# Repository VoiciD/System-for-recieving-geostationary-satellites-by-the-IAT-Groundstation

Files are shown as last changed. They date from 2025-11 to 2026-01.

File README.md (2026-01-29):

# System-for-recieving-geostationary-satellites-by-the-IAT-Groundstation
Die Arbeit beschäftigt sich mit der Planung, Entwicklung und Umsetzung eines Empfangssystems
für geostationären Satelliten mit einem Downlink im X-Band. Als Satellite bietet sich dabei der
Amateurfunksatellit Es’Hail-2 (QO-100) an, welcher einen Schmal- und Breitbandtransponder
mit Downlink im X-Band besitzt. In dieser Arbeit wird nur der Downlink des Schmalbandtrans-
ponder betrachtet.
Neben der Untersuchung des Satelliten gehört zur Planung und Entwicklung des Empfangs-
systems die Auswahl der passenden Komponenten. Im Zuge dessen wird an der Hochschule
vorhandene Antenne auf ihre Tauglichkeit überprüft, sowie neue notwendige Komponenten des
Empfangssystems ausgewählt. Für die Auswahl der passenden Komponenten ist eine theore-
tische Betrachtung des Downlinks notwendig. Besonderer Fokus wird dabei auf die Übertra-
gungsstrecke zwischen dem Satelliten und dem Standort des Empfangssystem am IAT gelegt.
Insbesondere die Dämpfung in der Atmosphäre bei unterschiedlichen Wetterbedingungen - kla-
rer Himmel, leichter Regen und Regen - und ihre Auswirkungen werden untersucht. Ermittelt
werden konnten Dämpfungen für klaren Himmel von LATklarerHimmel = 0.547 dB, leichter Regen
von LATleichterRegen = 0.947 dB und bei starken Niederschlägen von LATRegen = 9.61 dB. Diese
haben ebenfalls Auswirkungen auf das Rauschen des Empfangssystem. Für das Eigenrauschen
des Empfangssystems konnte eine äquivalente Rauschtemperatur Te,sys = 336.63 K und eine
Rauschzahl von Fsys = 3.34 dB ermittelt werden.
Für die einzelen Wetterbedingungen wird anschließend das Link Budget und der Signal-zu-
Rauschabstand am Ein- und Ausgang ermittelt womit eine Aussage über die Aufrechterhaltung
des Downlinks getroffen werden kann. Dabei kommt raus, dass der Downlink auch bei starken
Niederschlägen Aufrecht erhalten werden kann.
Mit dem entwickelten und aufgebauten Empfangssystem am IAT ist es möglichen den Downlink
des Schmalbandtransponder auf Es’Hail-2 (QO-100) zu empfangen. Jedoch ist die Leistung am
Ausgang PRX um 11.59 dB geringer, als in der Theorie berechnet. Da die gemessene Rauschleis-
tung nur um 0.93 dB von der berechneten Rauschleistung abweicht, ist von einer nicht optimalen
Ausrichtung der Antenne auf den Satelliten auszugehen.
Zum Schluss hin werden die berechneten und gemessenen Empfangsparameter des Empfangssys-
tem am IAT mit den Empfangsparameter mit einem Empfangssystem an der Goonhilly Bodensta-
tion in Cornwall (England) verglichen. Die Empfangsparameter an der Goonhilly Bodenstation
sind leicht besser, können aber mit der geographisch gesehen besseren Lage zum Satelliten und
dem größeren Antennendurchmesser von 1.3 m und damit verbundenen größeren Antennenge-
winn erklärt werden.

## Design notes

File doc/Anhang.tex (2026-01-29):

\subsection{Literaturverzeichnis}
\printbibliography
\subsection{Abbildungsverzeichnis}
\listoffigures
\subsection{Tabellenverzeichnis}
\listoftables

\subsection{Python Skripts}
\begin{lstlisting}[caption={Simulation eines Mischers in Python}, label={lst:mischer-python}]
import numpy as np
import matplotlib.pyplot as plt
import scipy.signal as sig
#Define Samplingtime and Sampling Frequency
ts = 0.001              #Samplingtime 0.001s
t = np.arange(0,1,ts)   #time axis
#Define the signals and noise
A_s = 1*10**(-3)
A_r = 1*10**(-3)
A_i = 0.1*10**(-3)
f_s_t = 200                                 #Input Frequency
f_i_t = 100                                 #Image Frequency
f_n_t = 150                                 #LO Frequency
s_t = A_s * np.cos(2*np.pi*f_s_t*t)         #Input Signal
i_t = A_i * np.cos(2*np.pi*f_i_t*t)         #Image Signal
n_t = A_r * np.cos(2*np.pi*f_n_t*t)         #LO Signal
x_t = s_t * n_t                             #Mixing
xsp_t = i_t * n_t                             #Mixing
#Using the FFT
n = len(t)
fs = int(1/ts)                              #Defining the Sampling Frequency and those the sampling points
x_t_fft = np.fft.fft(x_t,fs)                #Doing the FFT
s_t_fft = np.fft.fft(s_t,fs)                #Doing the FFT
n_t_fft = np.fft.fft(n_t,fs)                #Doing the FFT
i_t_fft = np.fft.fft(i_t,fs)                #Doing the FFT
xsp_t_fft = np.fft.fft(xsp_t,fs)                #Doing the FFT
shifted_x_t_fft = np.fft.fftshift(x_t_fft)  #bringing the 0 Hz into the center
shifted_s_t_fft = np.fft.fftshift(s_t_fft)  #bringing the 0 Hz into the center
shifted_n_t_fft = np.fft.fftshift(n_t_fft)  #bringing the 0 Hz into the center
shifted_i_t_fft = np.fft.fftshift(i_t_fft)  #bringing the 0 Hz into the center
shifted_xsp_t_fft = np.fft.fftshift(xsp_t_fft)  #bringing the 0 Hz into the center
mag_x = abs(shifted_x_t_fft)/n                          #calculating the magnitude
mag_s = abs(shifted_s_t_fft)/n                          #calculating the magnitude
mag_n = abs(shifted_n_t_fft)/n                          #calculating the magnitude
mag_i = abs(shifted_i_t_fft)/n                          #calculating the magnitude
mag_xsp = abs(shifted_xsp_t_fft)/n                          #calculating the magnitude
mag_x_dB = 10*np.log10(mag_x[int(fs/2):]/0.001)
mag_s_dB = 10*np.log10(mag_s[int(fs/2):]/0.001)
mag_n_dB = 10*np.log10(mag_n[int(fs/2):]/0.001)
mag_i_dB = 10*np.log10(mag_i[int(fs/2):]/0.001)
mag_xsp_dB = 10*np.log10(mag_xsp[int(fs/2):]/0.001)
freq = np.arange(0,500,len(t)/fs)
#Plotting
plt.figure()
plt.subplot(211)
plt.plot(freq,mag_s_dB, label = "HF-Signal")
plt.plot(freq,mag_n_dB, label = "LO-Signal")
plt.plot(freq,mag_i_dB, label = "SP-Signal")
plt.ylabel("Signalstrength in [dBm]")
plt.xlabel("Frequency in [MHz]")
plt.grid()
plt.legend(loc='upper right')
plt.tight_layout(h_pad=1.5, w_pad=0.8) 
plt.subplot(212)
plt.plot(freq,mag_x_dB, label = "ZF-Signal")
plt.plot(freq,mag_xsp_dB, label = "SP-Signal")
plt.ylabel("Signalstrength in [dBm]")
plt.xlabel("Frequency in [MHz]")
plt.grid()
plt.legend(loc='upper right')
plt.tight_layout(h_pad=1.5, w_pad=0.8)  
\end{lstlisting}

\begin{lstlisting}[caption={Simulation von Rauschen und SNR in Python}, label={lst:Rauschen-SNR-python}]
import numpy as np
import matplotlib.pyplot as plt
import scipy.signal as sig
#Define Samplingtime and Sampling Frequency
ts = 0.001              #Samplingtime 0.001s
t = np.arange(0,1,ts)   #time axis
#Define the signals and noise
A_s = 1*10**(-3)
A_r = 3*10**(-3)
f_s_t = 50
s_t = A_s * np.sin(2*np.pi*f_s_t*t)         #wanted signal
n_t = A_r * np.random.randn(len(t))         #Generating Noise with the length of the time axis
x_t = s_t + n_t
#Using the FFT
n = len(t)
fs = int(1/ts)                              #Defining the Sampling Frequency and those the sampling points
s_t_fft = np.fft.fft(x_t,fs)                #Doing the FFT
shifted_s_t_fft = np.fft.fftshift(s_t_fft)  #bringing the 0 Hz into the center
mag = abs(shifted_s_t_fft)/n                          #calculating the magnitude
freq = np.arange(-500,500,len(t)/fs)
mag = 10*np.log10(mag[int(fs/2):]/0.001)
freq = np.arange(0,500,len(t)/fs)
#Plotting
plt.figure()
plt.subplot(311)
plt.plot(t,s_t*1000,label = "Wanted signal")
plt.plot(t,n_t*1000,label = "Noise")
plt.ylabel("Voltage in [mV]")
plt.xlabel("Time in [s]")
plt.grid()
plt.legend(loc='upper right')
plt.subplot(312)
plt.plot(t,x_t*1000,label = "Mixed signal")
plt.ylabel("Voltage in [mV]")
plt.xlabel("Time in [s]")
plt.grid()
plt.legend(loc='upper right')
plt.subplot(313)
plt.plot(freq,mag, label = "FFT of the mixed signal")
plt.ylabel("Signalstrength in [dBm]")
plt.xlabel("Frequency in [Hz]")
plt.grid()
plt.legend(loc='upper right')
plt.tight_layout(h_pad=1.5, w_pad=0.8)    
\end{lstlisting}

\begin{lstlisting}[caption={Berechnung der Dämpfung durch Regen}, label={lst:Dämpfung-durch-Regen-python}]
import numpy as np
import matplotlib.pyplot as plt
elevation = np.deg2rad(27.36)  #elevation of the Antenna [°]
tau = np.deg2rad(-12.412)       #skew of the Antenna
h_0 = 3                         #Height of the isothermic barrier of the region from the groundstation[km]
h_Station = 0.023               #Height of the groundstation above Sealevel [km]
freq = 10.5                    #Frequency at which the link operates [GHz]
cordiantes_station = (53.055, 8.78,0.0)
#determination of the effective rain height [km]
h_R = h_0 + 0.36
#determination of path length the EM-Wave has to travel below the 
D_s = (h_R-h_Station)/(np.sin(elevation))
#determination of the horizontal projection caused by the path length of the EM-Wave
D_HP = D_s*np.cos(elevation)
#determination of the Rain intensity [mm/h] which exceeding the anual mean by 0.01% of the time
R_001 = 35                    #Mean in the northern part of Germany 35 to 40 mm/h 
R_graph = np.arange(0,40, 0.1 ) #For Graph Plotting 0 mm/H to 40mm/h
#determination of the frequency dependend coeffizients. Equations from the Book
# k_H = 3.949*10**(-6)*freq**(3.4078)
# k_V = 2.785*10**(-6)*freq**(3.5032)
# alpha_H = -0.7451*np.log10(freq)+2.0211
# alpha_V = -0.8083*np.log10(freq)+2.0723
#von ITU-R P.838-3
k_H = 0.01217
k_V = 0.01129
alpha_H = 1.2571
alpha_V = 1.2156
#determination of the specific rain attenuatuion
k = (k_H + k_V + (k_H-k_V) * (np.cos(elevation))**2 * np.cos(2*tau))/2
alpha = (k_H * alpha_H + k_V * alpha_V + (k_H * alpha_H - k_V * alpha_V) * (np.cos(elevation))**2 * np.cos(2*tau)) / (2*k)
gamma_R001 = k*(R_001)**alpha
print("y_R001:",gamma_R001,"dB/km")
#calculation horizontal reduction factor
r001 = 1 / (1 + 0.78 * np.sqrt((D_HP*gamma_R001) / freq) - 0.38 * (1 - np.exp(-2 * D_HP)))
#calculation vertical adjustment factor
cc001 = np.rad2deg(np.arctan((h_R-h_Station)/(D_HP*r001)))
if cc001 > np.rad2deg(elevation):
    D_R001 = (D_HP*r001)/np.cos(elevation)
else:
    D_R001 = (h_R-h_Station)/np.sin(elevation)
if abs(cordiantes_station[0]) > 36:
    X = 36 - abs(cordiantes_station[0])
else:
    X = 0
v001 = 1 / (1 + np.sqrt(np.sin(elevation)) * (31 * (1 - np.exp( (-1)* ( elevation/(1+X))))*(np.sqrt(D_R001 *gamma_R001))/(freq**2)-0.45))
#for graph 
A_graph = np.empty_like(R_graph)
gamma_Rgraph = np.empty_like(R_graph)
for i, R in enumerate(R_graph): 
    gamma_Rgraph[i] = k * (R)**alpha
    rgraph = 1 / (1 + 0.78 * np.sqrt((D_HP * gamma_Rgraph[i]) / freq) - 0.38 * (1 - np.exp(-2 * D_HP)))
    ccgraph = np.rad2deg(np.arctan((h_R - h_Station) / (D_HP * rgraph)))
    if ccgraph > np.rad2deg(elevation):
        D_Rgraph = (D_HP * rgraph) / np.cos(elevation)
    else:
        D_Rgraph = (h_R - h_Station) / np.sin(elevation)
    if abs(cordiantes_station[0]) > 36:
        X = 36 - abs(cordiantes_station[0])
    else:
        X = 0
    vgraph = 1 / (1 + np.sqrt(np.sin(elevation)) * (31 * (1 - np.exp(-1 * (elevation / (1 + X)))) * 
                      np.sqrt(D_Rgraph * gamma_Rgraph[i]) / (freq**2) - 0.45))
    D_Regengraph = D_Rgraph * vgraph
    A_graph[i] = gamma_Rgraph[i] * D_Regengraph
print("Vertikal adjusmentfaktor 0.01:",v001)
#calculation effective path length D_Regen
D_Regen001 = D_R001*v001
print("Effectiv Path lenght through the rain 0.01:",D_Regen001,"km")
#calculation worst case attenuation for rain exceeded for 0.01% of an avarage year
A_001 = gamma_R001*D_Regen001
print("worst case attenuation caused by rain exceeded for 0.01% of an avarage year:",A_001,"dB")
plt.figure("Attenuation caused by rain 10 GHz")
plt.title("Dämpfung durch starke Niederschläge bei f = 10 GHz")
plt.plot(R_graph,A_graph)
plt.ylabel("Dämpfung in dB")
plt.xlabel("Niederschlagsmenge in mm/h")
plt.grid()
# Attenuatuion for other percanteges
unit = 1
p = 5*unit
long = 8.78
if p >= 1*unit or abs(long) >= 36:
    beta = 0
elif p < 1*unit and abs(long) < 36 and elevation >= 25:
    beta = (-1)*0.005*(abs(long)-36)
else:
    beta = (-1)*0.005*(abs(long)-36)+1.8-4.25*np.sin(elevation)
exponent = (-1)*(0.655+0.033*np.log(p)-0.045*np.log(A_001)-beta*(1-p)*np.sin(elevation))
A_other = A_001*(p/0.01)**exponent
print("Attenuation for Rainrates exceeding",p,"% of the time the anual avarage:",A_other,"dB")   
\end{lstlisting}

\begin{lstlisting}[caption={Berechnung des Link Budgets}, label={lst:Link-Budget-python}]
import numpy as np
import matplotlib.pyplot as plt
#Allgemeine Parameter
k = 1.38*10**(-23)
P_T = 17.78                         #Sendeleistung Es'Hail-2 in W
P_T_dBm = 42.5
G_T = 50.12                         #Gewinn der Sendeantenne
EIRP = P_T * G_T                    #EIRP von Es'Hail-2
EIRP_dBm = 59.5
B = 2.7*10**3                       #Bandbreite des Downlinks
L_FR = 2.9*10**(20)                 #Freiraumdämpfung
L_FR_dB = 204.61
L_OT = 3.33                         #Senderseitige Fehlausrichtung
L_OT_dB = 5.23
L_OR = 0.69                         #Empfangsseitige Fehlasusrichtung
L_OR_dB = 0.69
G_R = 7244.36
G_LNC = 316227.76
G_SDR = 1000
L_sys = 5.02  
G_sys = G_LNC*G_SDR*(1/L_sys)
T0 = 290
#Äquivalente Rauschtemperatur
Te1 = 133.4                #133.4
TeLNC = 139.2
Te2 = 200.1
TeBiasTee = 118.9
Te3 = 17.4
TePatchfeld = 58
Te4 = 8.7
TeRFSwitch = 20.3
Te5 = 8.7
TeSDR = 1539.9
G1 = 0.685
GLNC = 316227.77
G2 = 0.59
GBiasTee = 0.71
G3 = 0.94
GPatchfeld = 0.83
G4 = 0.97
GRFSwitch = 0.93
G5 = 0.97
T_esys = Te1 + (TeLNC/(G1) ) + (Te2/(G1*GLNC) ) + (TeBiasTee/(G1*GLNC*G2) ) + (Te3/(G1*GLNC*G2*GBiasTee) ) + (TePatchfeld/(G1*GLNC*G2*G3) ) + (Te4/(G1*GLNC*G2*G3*GPatchfeld) ) + (TeRFSwitch /(G1*GLNC*G2*G3*GPatchfeld*G4) )+ (Te5 /(G1*GLNC*G2*G3*GPatchfeld*G4*GRFSwitch) )+ (TeSDR /(G1*GLNC*G2*G3*GPatchfeld*G4*GRFSwitch*G5) )
print("Äquivalente Rauschtemperatur Te,sys:",T_esys,"K")
#klarer Himmel
print("Für Bedingung klarer Himmel:")
L_ATklarerHimmel = 1.13             #Dämpfung in der Atmosphäre bei klarem Himmel
L_ATklarerHimmel_dB = 0.547
T_AklarerHimmel = 6.5               #Antennentemperatur bei klaren Himmel
P_R_klarer_Himmel = EIRP*G_R*(1/L_FR)*(1/L_OT)*(1/L_OR)*(1/L_ATklarerHimmel)
P_R_klarer_Himmel_dB = 10*np.log10(P_R_klarer_Himmel/(0.001))
print("empfangene Leistung $P_R$:",P_R_klarer_Himmel,"W")
print("empfangene Leistung $P_R$",P_R_klarer_Himmel_dB,"dBm")
P_RX_klarer_Himmel = EIRP*G_R*(1/L_FR)*(1/L_OT)*(1/L_OR)*(1/L_ATklarerHimmel)*G_sys
P_RX_klarer_Himmel_dB = 10*np.log10(P_RX_klarer_Himmel/(0.001))
print("Ausgangsleistung des Empfangssystems $P_{RX}$:",P_RX_klarer_Himmel,"W")
print("Ausgangsleistung des Empfangssystems $P_{RX}$",P_RX_klarer_Himmel_dB,"dBm")
N_i = k*T_AklarerHimmel*B
SNR_i_klarerHimmel = P_R_klarer_Himmel/N_i
SNR_i_klarerHimmel_dB = 10*np.log10(SNR_i_klarerHimmel)
print("SNR am Eingang bei klaren Himmel:",SNR_i_klarerHimmel_dB,"dB")
N_o = k*(T_AklarerHimmel+T_esys)*B
SNR_o_klarer_Himmel = P_R_klarer_Himmel/N_o
SNR_o_klarer_Himmel_dB = 10*np.log10(SNR_o_klarer_Himmel)
print("SNR am Ausgang des Empfangssystems:",SNR_o_klarer_Himmel_dB,"dB")
T_S_klarer_Himmel = (T_AklarerHimmel/L_sys)+T0*(1-(1/L_sys))+T_esys
CN0_klarer_Himmel = P_RX_klarer_Himmel/(k*T_S_klarer_Himmel)
CN0_klarer_Himmel_dBHz = 10*np.log10(CN0_klarer_Himmel)
print("Qualität des Downlinks:",CN0_klarer_Himmel_dBHz,"dBHz")
Link_Budget_klarer_Himmel_label = np.array(["Sende-\nLeistung","EIRP","Freiraum-\nDämpfung","Ausrichtungs-\nVerluste","Dämpfung\n Atmosphäre","Empfangene\nLeistung","Leistung\n am Ausgang"])
Link_Budget_klarer_Himmel = np.array([P_T,EIRP_dBm,EIRP_dBm-L_FR_dB,EIRP_dBm-L_FR_dB-L_OR_dB-L_OT_dB,EIRP_dBm-L_FR_dB-L_OR_dB-L_OT_dB-L_ATklarerHimmel_dB,P_R_klarer_Himmel_dB,P_RX_klarer_Himmel_dB])
plt.figure("LinkBudget clear Sky")
plt.title("Link Budget bei klaren Himmel")
for i, val in enumerate(Link_Budget_klarer_Himmel):
    plt.annotate(f'{val:.2f}', (i, val), textcoords="offset points",
                 xytext=(0,10), ha='center')  # 10 Pkt über dem Punkt
plt.plot(Link_Budget_klarer_Himmel_label,Link_Budget_klarer_Himmel,'o-')
plt.ylabel("Leistung in dBm")
plt.grid()
plt.ylim([-180,90])
plt.xticks(range(len(Link_Budget_klarer_Himmel_label)), Link_Budget_klarer_Himmel_label, rotation=45)
plt.tight_layout(pad=0.5)
plt.show()
#leichter Regen
print("Für die Bedingung leichter Regen:")
L_ATleichterRegen = 1.24
L_ATleichterRegen_dB = 0.947
T_AleichterRegen = 19.29
P_R_leichter_Regen = EIRP*G_R*(1/L_FR)*(1/L_OT)*(1/L_OR)*(1/L_ATleichterRegen)
P_R_leichter_Regen_dB = 10*np.log10(P_R_leichter_Regen/(0.001))
print("empfangene Leistung $P_R$:",P_R_leichter_Regen,"W")
print("empfangene Leistung $P_R$",P_R_leichter_Regen_dB,"dBm")
P_RX_leichter_Regen = EIRP*G_R*(1/L_FR)*(1/L_OT)*(1/L_OR)*(1/L_ATleichterRegen)*G_sys
P_RX_leichter_Regen_dB = 10*np.log10(P_RX_leichter_Regen/(0.001))
print("Ausgangsleistung des Empfangssystems $P_{RX}$:",P_RX_leichter_Regen,"W")
print("Ausgangsleistung des Empfangssystems $P_{RX}$",P_RX_leichter_Regen_dB,"dBm")
N_i = k*T_AleichterRegen*B
SNR_i_leichter_Regen = P_R_leichter_Regen/N_i
SNR_i_leichter_Regen_dB = 10*np.log10(SNR_i_leichter_Regen)
print("SNR am Eingang bei klaren Himmel:",SNR_i_leichter_Regen_dB,"dB")
N_o = k*(T_AleichterRegen+T_esys)*B
SNR_o_leichter_Regen = P_R_leichter_Regen/N_o
SNR_o_leichter_Regen_dB = 10*np.log10(SNR_o_leichter_Regen)
print("SNR am Ausgang des Empfangssystems:",SNR_o_leichter_Regen_dB,"dB")
T_S_leichter_Regen = (T_AleichterRegen/L_sys)+T0*(1-(1/L_sys))+T_esys
CN0_leichter_Regen = P_RX_leichter_Regen/(k*T_S_leichter_Regen)
CN0_leichter_Regen_dBHz = 10*np.log10(CN0_leichter_Regen)
print("Qualität des Downlinks:",CN0_leichter_Regen_dBHz,"dBHz")
Link_Budget_leichter_Regen_label = np.array(["Sende-\nLeistung","EIRP","Freiraum-\nDämpfung","Ausrichtungs-\nVerluste","Dämpfung\n Atmosphäre","Empfangene\nLeistung","Leistung\n am Ausgang"])
Link_Budget_leichter_Regen = np.array([P_T,EIRP_dBm,EIRP_dBm-L_FR_dB,EIRP_dBm-L_FR_dB-L_OR_dB-L_OT_dB,EIRP_dBm-L_FR_dB-L_OR_dB-L_OT_dB-L_ATleichterRegen_dB,P_R_leichter_Regen_dB,P_RX_leichter_Regen_dB])
plt.figure("LinkBudget light Rain")
plt.title("Link Budget bei leichten Regen")
for i, val in enumerate(Link_Budget_leichter_Regen):
    plt.annotate(f'{val:.2f}', (i, val), textcoords="offset points",
                 xytext=(0,10), ha='center')  # 10 Pkt über dem Punkt
plt.plot(Link_Budget_leichter_Regen_label,Link_Budget_leichter_Regen,'o-')
plt.ylabel("Leistung in dBm")
plt.grid()
plt.ylim([-180,90])
plt.xticks(range(len(Link_Budget_leichter_Regen_label)), Link_Budget_leichter_Regen_label, rotation=45)
plt.tight_layout(pad=0.5)
plt.show()
#Regen
print("Für die Bedingung Regen:")
L_ATRegen = 9.14
L_ATRegen_dB = 9.61
T_ARegen = 240.1
P_R_Regen = EIRP*G_R*(1/L_FR)*(1/L_OT)*(1/L_OR)*(1/L_ATRegen)
P_R_Regen_dB = 10*np.log10(P_R_Regen/(0.001))
print("empfangene Leistung $P_R$:",P_R_Regen,"W")
print("empfangene Leistung $P_R$",P_R_Regen_dB,"dBm")
P_RX_Regen = EIRP*G_R*(1/L_FR)*(1/L_OT)*(1/L_OR)*(1/L_ATRegen)*G_sys
P_RX_Regen_dB = 10*np.log10(P_RX_Regen/(0.001))
print("Ausgangsleistung des Empfangssystems $P_{RX}$:",P_RX_Regen,"W")
print("Ausgangsleistung des Empfangssystems $P_{RX}$",P_RX_Regen_dB,"dBm")
N_i = k*T_ARegen*B
SNR_i_Regen = P_R_Regen/N_i
SNR_i_Regen_dB = 10*np.log10(SNR_i_Regen)
print("SNR am Eingang bei klaren Himmel:",SNR_i_Regen_dB,"dB")
N_o = k*(T_ARegen+T_esys)*B
SNR_o_Regen = P_R_Regen/N_o
SNR_o_Regen_dB = 10*np.log10(SNR_o_Regen)
print("SNR am Ausgang des Empfangssystems:",SNR_o_Regen_dB,"dB")
T_S_Regen = (T_ARegen/L_sys)+T0*(1-(1/L_sys))+T_esys
CN0_Regen = P_RX_Regen/(k*T_S_Regen)
CN0_Regen_dBHz = 10*np.log10(CN0_Regen)
print("Qualität des Downlinks:",CN0_Regen_dBHz,"dBHz")
Link_Budget_Regen_label = np.array(["Sende-\nLeistung","EIRP","Freiraum-\nDämpfung","Ausrichtungs-\nVerluste","Dämpfung\n Atmosphäre","Empfangene\nLeistung","Leistung\n am Ausgang"])
Link_Budget_Regen = np.array([P_T,EIRP_dBm,EIRP_dBm-L_FR_dB,EIRP_dBm-L_FR_dB-L_OR_dB-L_OT_dB,EIRP_dBm-L_FR_dB-L_OR_dB-L_OT_dB-L_ATRegen_dB,P_R_Regen_dB,P_RX_Regen_dB])
plt.figure("LinkBudget Rain")
plt.title("Link Budget bei Regen")
for i, val in enumerate(Link_Budget_Regen):
    plt.annotate(f'{val:.2f}', (i, val), textcoords="offset points",
                 xytext=(0,10), ha='center')  # 10 Pkt über dem Punkt
plt.plot(Link_Budget_Regen_label,Link_Budget_Regen,'o-')
plt.ylabel("Leistung in dBm")
plt.grid()
plt.ylim([-180,90])
plt.xticks(range(len(Link_Budget_Regen_label)), Link_Budget_Regen_label, rotation=45)
plt.tight_layout(pad=0.5)
plt.show()
\end{lstlisting}

\begin{lstlisting}[caption={Berechnung von Azimut, Elevatin und Skew der Antenne}, label={lst:Antenne-berechnung-python}]
import numpy as np
lat_ant = np.deg2rad(53.055)
long_ant = np.deg2rad(8.78)
lat_sat = np.deg2rad(0)
long_sat = np.deg2rad(25.8)
r_geo = 35790
r_earth = 6378
d_long = long_ant-long_sat
#Brechnung der Azimut
azimut = np.rad2deg(np.arctan((np.tan(d_long))/(np.sin(lat_ant))))+180
print("Azimut:",azimut,"°")
#Berechnung der Elevation
ratio = r_earth/(r_earth+r_geo)
elevation = np.rad2deg(np.arctan((np.cos(lat_ant)*np.cos(d_long)-ratio)/(np.sqrt(1-(np.cos(lat_ant)*np.cos(d_long))**2))))
print("Elevation:",elevation,"°")
#Berechnung Skew
offset = 0
skew = np.rad2deg(np.arctan((np.sin(d_long))/(np.tan(lat_ant))))-offset
print("Skew:",skew,"°")
\end{lstlisting}

\begin{lstlisting}[caption={Vergleich der Link Budgets},label={lst:Vergleich-Link-Budget}]
import numpy as np
import matplotlib.pyplot as plt
k = 1.38*10**(-23)
P_T = 17.78                         #Sendeleistung Es'Hail-2 in W
P_T_dBm = 42.5
G_T = 50.12                         #Gewinn der Sendeantenne
EIRP = P_T * G_T                    #EIRP von Es'Hail-2
EIRP_dBm = 59.5
B = 2.7*10**3                       #Bandbreite des Downlinks
L_FR = 2.9*10**(20)                 #Freiraumdämpfung
L_FR_dB = 204.61
L_OT = 3.33                         #Senderseitige Fehlausrichtung
L_OT_dB = 5.23
L_OR = 0.69                         #Empfangsseitige Fehlasusrichtung
L_OR_dB = 0.69
L_ATklarerHimmel = 1.13             #Dämpfung in der Atmosphäre bei klarem Himmel
L_ATklarerHimmel_dB = 0.547
T_AklarerHimmel = 6.5               #Antennentemperatur bei klaren Himmel
G_R = 7244.36
G_LNC = 316227.76
G_SDR = 1412.54
L_sys = 5.02  
G_sys = G_LNC*G_SDR*(1/L_sys)
P_R_klarer_Himmel = EIRP*G_R*(1/L_FR)*(1/L_OT)*(1/L_OR)*(1/L_ATklarerHimmel)
P_R_klarer_Himmel_dB = 10*np.log10(P_R_klarer_Himmel/(0.001))
P_RX_klarer_Himmel = EIRP*G_R*(1/L_FR)*(1/L_OT)*(1/L_OR)*(1/L_ATklarerHimmel)*G_sys
P_RX_klarer_Himmel_dB = 10*np.log10(P_RX_klarer_Himmel/(0.001))
Link_Budget_klarer_Himmel_label = np.array(["Sende-\nLeistung","EIRP","Freiraum-\nDämpfung","Ausrichtungs-\nVerluste","Dämpfung\n Atmosphäre","Empfangene\nLeistung","Leistung\n am Ausgang"])
Link_Budget_klarer_Himmel = np.array([P_T,EIRP_dBm,EIRP_dBm-L_FR_dB,EIRP_dBm-L_FR_dB-L_OR_dB-L_OT_dB,EIRP_dBm-L_FR_dB-L_OR_dB-L_OT_dB-L_ATklarerHimmel_dB,P_R_klarer_Himmel_dB,P_RX_klarer_Himmel_dB])
G_Goon_dB = 65
L_FR_G_dB = 204.34
L_OT_G_dB = 1.91
P_R_G = -107.77
P_RX_G = -42.77
Link_Budgter_klarer_Himmel_Goonhilly = np.array([P_T,EIRP_dBm,EIRP_dBm-L_FR_G_dB,EIRP_dBm-L_FR_G_dB-L_OR_dB-L_OT_G_dB,EIRP_dBm-L_FR_G_dB-L_OR_dB-L_OT_G_dB-L_ATklarerHimmel_dB,P_R_G,P_RX_G])
plt.figure("LinkBudget clear Sky")
plt.title("Vergleich des Link Budgets bei klaren Himmel")
for i, val in enumerate(Link_Budget_klarer_Himmel):
    plt.annotate(f'{val:.2f}', (i, val), textcoords="offset points",
                 xytext=(0,10), ha='center')  # 10 Pkt über dem Punkt
    for i, val in enumerate(Link_Budgter_klarer_Himmel_Goonhilly):
        plt.annotate(f'{val:.2f}', (i, val), textcoords="offset points",
                     xytext=(0,-15), ha='center')  # 10 Pkt über dem Punkt
plt.plot(Link_Budget_klarer_Himmel_label,Link_Budget_klarer_Himmel,'o-',label="IAT")
plt.plot(Link_Budget_klarer_Himmel_label,Link_Budgter_klarer_Himmel_Goonhilly,'o-',label="Goonhilly")
plt.ylabel("Leistung in dBm")
plt.grid()
plt.legend()
plt.ylim([-180,90])
plt.xticks(range(len(Link_Budget_klarer_Himmel_label)), Link_Budget_klarer_Himmel_label, rotation=45)
plt.tight_layout(pad=0.5)
plt.show()    
\end{lstlisting}

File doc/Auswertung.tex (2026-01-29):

\subsection{Empfangen des Downlinks und vergleichen der theoretischen Empfangsparameter mit den erreichten Empfangsparametern}
Nach dem Aufstellen und Ausrichten der Antenne, sowie dem Aufbau des restlichen Empfangssystems kann über den USRP X310 mit der erstellten SDR-Software der empfangene Downlink grafisch dargestellt und demoduliert werden.
\begin{figure}[H]
    \centering
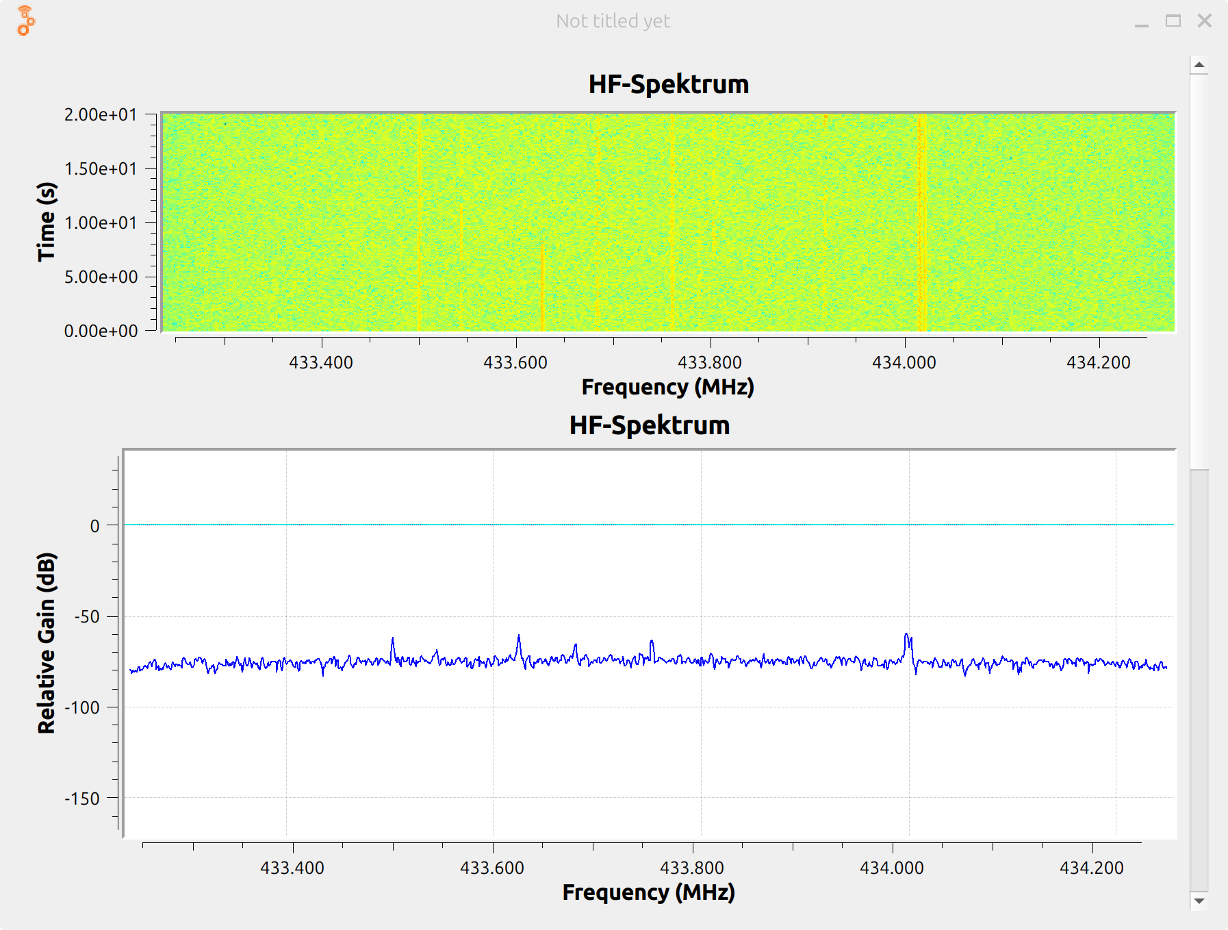
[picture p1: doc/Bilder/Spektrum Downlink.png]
    
    \caption{Mit dem Empfangssystem am IAT empfangener Downlink des Schmalbandtransponder auf Es'Hail-2 (QO-100)}
    \label{fig:Empfangener-Downlink-EsHail2}
\end{figure}
Die Abbildung \ref{fig:Empfangener-Downlink-EsHail2} zeigt den mit dem am IAT aufgebauten Empfangssystem empfangenen Downlink des Schmalbandtransponders auf Es'Hail-2 (QO-100) als Wasserfalldiagramm (oben) und als FFT-Spektrum (unten). In der SDR-Software ist die Verstärkung des USRP X310 auf $G_\mathrm{SDR}=25\,\text{dB}$ eingestellt um einen möglichst guten Kontrast der Signale zum Rauschen im Wasserfalldiagramm zu erzielen. Gut zu erkennen sind die untere und obere Funkbarke bei $343.5\,\text{MHz}$, bzw. $344\,\text{MHz}$. Auch die mittlere Funkbarke bei $433.75\,\text{MHz}$ ist zu erkennen. Auch konnte eine Einseitenbandübertragung empfangen und demoduliert werden. Die Audioaufnahme ist im GitHub-Repository hinterlegt.\newline
Um die rechnerisch bestimmten Empfangsparameter auf ihre Korrektheit zu überprüfen, werden diese mit den in der Praxis erreichten Empfangsparametern verglichen. Mithilfe eines Spektrumanalysator anstelle des USRP X310 können, unter Berücksichtigung der um $G_\mathrm{SDR,max}=31.5\,\text{dB}$ verringerten Verstärkung, die Leistung $P_\mathrm{RX}$, die Rauschleistung $N_\mathrm{o}$ und der Signal-zu-Rauschabstand $SNR_\mathrm{o}$ am Ausgang gemessen werden.
\begin{figure}[H]
    \centering
    \includesvg[width=0.5\linewidth]{Bilder/Messaufbau Spektrum}
    \caption{Verwendeter Messaufbau}
    \label{fig:Messaufbau-Spektrum}
\end{figure}
Die Abbildung \ref{fig:Messaufbau-Spektrum} zeigt den angewendeten Messaufbau. Als Spekrumanalysator wird ein Rohde \& Schwarz ZVL verwendet. Gemessen wird mit einer $RBW=3\,\text{kHz}$ und einer $VBW=3\,\text{kHz}$. Das Referenzlevel wird auf $-20\,\text{dBm}$ gesetzt und die Dämpfung auf $0\,\text{dB}$. Das Wetter zum Zeitpunkt der Messung ist es bewölkt gewesen.
\begin{figure}[H]
    \centering
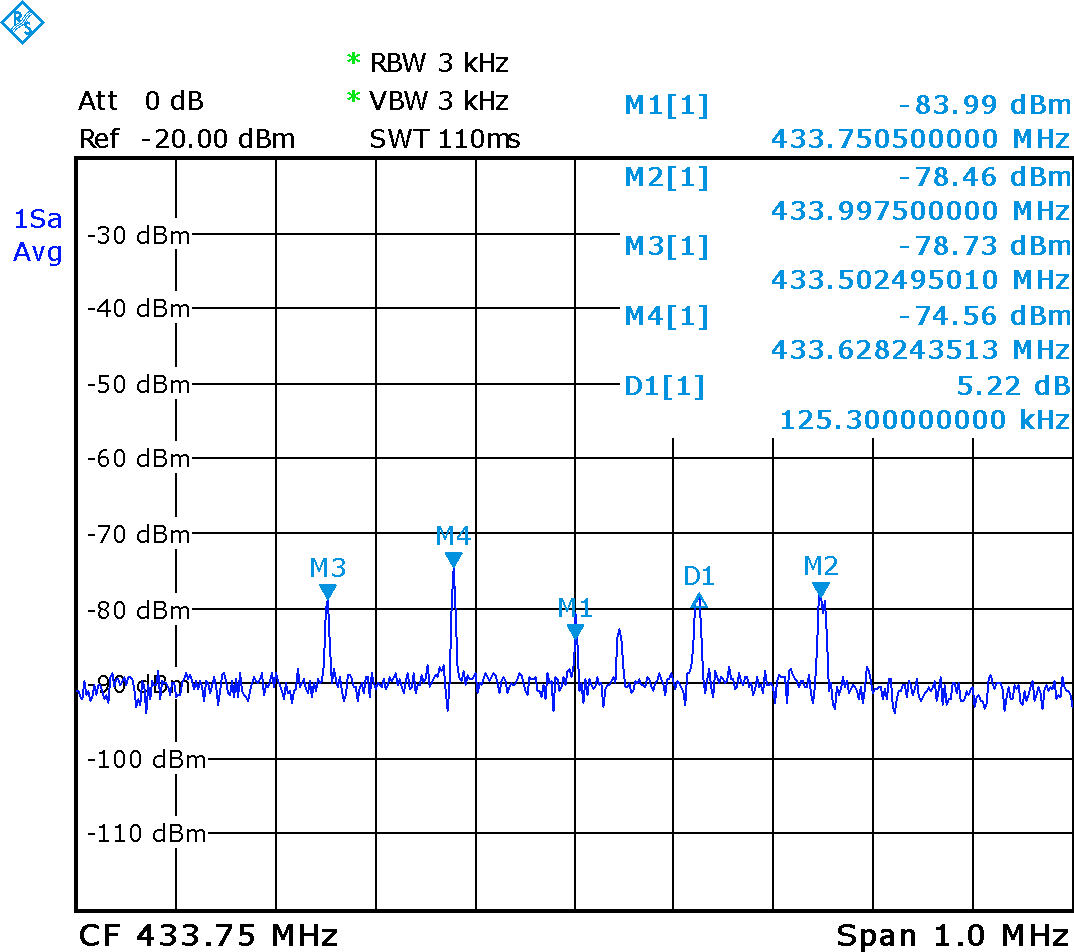
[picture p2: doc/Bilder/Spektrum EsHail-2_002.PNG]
    
    \caption{Mit dem Spektrumanalysator aufgenommenes Frequenzspektrum des empfangenen Downlinks von Es'Hail-2 (QO-100)}
    \label{fig:Empfangener-Downlink-EsHail-2}
\end{figure}
Die Abbildung \ref{fig:Empfangener-Downlink-EsHail-2} zeigt den empfangenen Downlink des Schmalbandtransponders auf Es'Hail-2 (QO-100). Der Marker 1 sitzt bei $433.75\,\text{MHz}$ auf der mittleren BPSK Funkbarke, welche sich im HF-Bereich bei $10489.75\,\text{MHz}$ befindet. Die Marker 2 und 3 sitzen auf den äußeren Funkbarken bei $433.5\,\text{MHz}$ und $434\,\text{MHz}$, bzw. $10489.5\,\text{MHz}$ und $10490\,\text{MHz}$ im HF-Bereich. 
\begin{equation*}
    \Delta f=f_\mathrm{HF,center}-f_\mathrm{ZF,center}=10489.75\,\text{MHz}-433.75\,\text{MHz}=10056\,\text{MHz}
\end{equation*}
Die Frequenzdifferenz zwischen der mittleren Funkbarke im HF-Bereich und im ZF-Bereich beträgt $\Delta f=10056\,\text{MHz}$ und entspricht damit der gewünschten Frequenz des lokalen Oszillator von $f_\mathrm{LO}=10056\,\text{MHz}$. Somit kann von einer korrekten Funktionsweise des LNC ausgegangen werden.\newline
Der Marker 4 markiert eine digitale Übertragung im Downlink bei $433.628\,\text{MHz}$. Diese wird zum Vergleich der in Theorie bestimmten Empfangsparameter verwendet. Gemessen wird an diesem Signal ein Pegel von $-74.56\,\text{dBm}$. Mit der Berücksichtigung der Verstärkung des USRP X310 $G_\mathrm{SDR}=31.5\,\text{dB}$ kann die reale Leistung am Ausgang des Empfangssystems $P_\mathrm{RX}$ bestimmt werden.
\begin{equation}
    P_\mathrm{RX,real}=-74.56\,\text{dBm}+31.5\,\text{dB}=-43.05\,\text{dBm}
    \label{eq:reale-Ausgangsleistung}
\end{equation}
Die reale Leistung am Ausgang liegt bei $P_\mathrm{RX,real}=-43.05\,\text{dBm}$. Die reale Ausgangsleistung liegt damit $2.8\,\text{dB}$ unter der bestimmten Ausgangsleistung für starke Niederschläge $P_\mathrm{RX}=-40.25\,\text{dBm}$ und $11.87\,\text{dB}$ unter der empfangenen Leistung bei klaren Himmel $P_\mathrm{RX}=-31.18\,\text{dB}$ Um weitere Aussagen treffen zu können, kann die Rauschleistung am Ausgang und der Signal-zu-Rauschabstand begutachtet werden. Gemessen wird eine Rauschleistung von $N_\mathrm{o}\approx-90\,\text{dBm}$, was nach der Verstärkung durch den SDR einer Rauschleistung von $N_\mathrm{o,real}=-58.5\,\text{dBm}$ entsprechen würde. Da es zum Zeitpunkt der Messung bewölkt gewesen ist, Wolken aber keinen großen Einfluss auf das Rauschen oder die Dämpfung $(0.2\,\text{dB})$ haben, wird es mit der Rauschleistung bei einem klaren Himmel verglichen.
\begin{equation}
\begin{split}
        N_\mathrm{o,klarerHimmel}&=k\cdot (T_\mathrm{A}+T_\mathrm{e,sys})\cdot B \cdot G\\
        &=1.38\cdot10^{-23}\,\frac{\text{J}}{\text{K}}\cdot(6.5+336.63\,\text{K})\cdot2.7\,\text{kHz}\cdot 10^{\frac{55\,\text{dB}}{10}}\\
        &=1.14\cdot10^{-9}\,\text{W}=-59.43\,\text{dBm}
\end{split}
\label{eq:rechnerische-Rauschleistung}
\end{equation}
Rechnerisch kann eine Rauschleistung bei einem klaren Himmel von $N_\mathrm{o,real}=-59.43\,\text{dBm}$ bestimmt werden. Die gemessene Rauschleistung liegt damit $0.97\,\text{dB}$ über und damit sehr nah an der rechnerisch bestimmten Rauschleitung. Mit der Rauschleistung
$N_\mathrm{o}=-58.5\,\text{dBm}$ und der Leistung am Ausgang $P_\mathrm{RX,real}=-43.05\,\text{dBm}$ kann der reale Signal-zu-Rauschabstand am Ausgang des Empfangssystems $SNR_\mathrm{o,real}$ bestimmt werden.
\begin{equation}
    SNR_\mathrm{o,real}=-43.05\,\text{dBm}-(-58.5\,\text{dBm})= 15.45\,\text{dB}
    \label{eq:realer-Signal-zu-Rauschabstand}
\end{equation}
Der reale Signal-zu-Rauschabstand am Ausgang beträgt $SNR_\mathrm{o,real}
= 15.45\,\text{dB}$. Dieser ist um $12.81\,\text{dB}$ geringer, als der rechnerisch bestimmte Signal-zu-Rauschabstand bei einem klaren Himmel $SNR_\mathrm{o,klarerHimmel}=28.26\,\text{dB}$. Grund dafür ist die um $11.87\,\text{dB}$ verringerte Leistung am Ausgang $P_\mathrm{RX}$ und die um $0.97\,\text{dB}$ leicht höhere Rauschleistung. Da die berechnete Rauschleistung $N_\mathrm{o}$ nahezu mit der gemessenen Rauschleistung $N_\mathrm{o,real}$ übereinstimmt ist davon auszugehen, dass die Antenne noch nicht optimal mit der Hauptkeule auf den Satelliten ausgerichtet ist, was zu einer Verringerung der empfangenen Leistung $P_\mathrm{R}$ und damit auch zu einer Reduzierung der Leistung am Ausgang $P_\mathrm{RX}$ und dem Signal-zu-Rauschabstand führt. Durch die hohe Richtwirkung ist der Bereich, indem ein Signal von Es'Hail-2 (QO-100) empfangen wird, sehr schmal. In Kombination mit der Unhandlichkeit der Antenne ist eine genaue Ausrichtung der Hauptkeule mit dem maximalen Gewinn $G_\mathrm{R,max}=38.6\,\text{dBi}$ schwer. Weitere Versuche die Antenne besser auszurichten und damit die Leistung am Ausgang $P_\mathrm{RX}$ zu erhöhen, blieben erfolglos.\newline
Abschließend kann aus der Rauschleistung $N_\mathrm{o,real}=-58.5\,\text{dBm}=1.41\cdot10^{-9}\,\text{W}$ die Rauschtemperatur $T_\mathrm{S}=T_\mathrm{A}+T_\mathrm{e,sys}$ bestimmt werden.
\begin{equation}
    T_\mathrm{S,real}=\frac{N_\mathrm{o,real}}{k\cdot B \cdot G}=\frac{
    1.41\cdot10^{-9}\,\text{W}}{1.38\cdot10^{-23}\frac{\text{J}}{\text{K}}\cdot 2.7\,\text{kHz}\cdot10^{\frac{79.49\,\text{dB}}{10}}}=425.58\,\text{K}
    \label{eq:reale-Rauschtemperatur}
\end{equation}
Die Rauschtemperatur $T_\mathrm{S,real}=425.58\,\text{K}$ ist $95.45\,\text{K}$ höher, als die theoretische Rauschtemperatur $T_\mathrm{S}=6.5\,\text{K}+336.63\,\text{K}=343.13\,\text{K}$. Grund dafür wird mit großer Wahrscheinlichkeit eine höhere Antennentemperatur $T_\mathrm{A}$ sein, da bei der Berechnung von einer idealen Antenne ohne Nebenkeule in Richtung des Bodens ausgegangen wird.
\begin{equation}
    G/T=\frac{G_\mathrm{R,max}}{T_\mathrm{S,real}}=\frac{7244.36}{425.58\,\text{K}}=17.02\,\text{1/K}=12.31\,\text{dB/K}
    \label{eq:reale-Empfangsgüte}
\end{equation}
Durch die höhere Rauschtemperatur $T_\mathrm{S,real}=425.58\,\text{K}$ wird die Empfangsgüte, verglichen mit der Empfangsgüte bei einem klaren Himmel $G/T=13.24\,\text{dB/K}$, um $0.93\,\text{dB/K}$ auf $G/T=12.31\,\text{K}$ reduziert, was einem Verlust von $19.3\%$ entspricht.\newline
Insgesamt sind die Ergebnisse zufriedenstellend und decken sich in einem bestimmten Rahmen mit den in der Theorie bestimmten Empfangsparametern. Ausgenommen davon sind die empfangene Leistung $P_\mathrm{RX,real}=-43.05\,\text{dBm}$ und damit auch der Signal-zu-Rauschabstand von $SNR_\mathrm{o,real}=15.45\,\text{dB}$, was aber mit der nicht genauen Ausrichtung der Antenne erklärt werden kann.

\subsection{Vergleich der Empfangsparameter der IAT Bodenstation mit den Empfangsparameter der Goonhilly Bodenstation}
Für eine bessere Einschätzung werden die Empfangsparameter des Empfangssystem am IAT mit den Empfangsparameter des Empfangssystems an der Goonhilly Bodenstation in Cornwall (England) verglichen.\newline 
An der Goonhilly Bodenstation hat der Britisch Amateur Television Club (BATC) ein Empfangssystem für den Downlink des Schmal- und Breitbandtransponder auf Es'Hail-2 (QO-100) errichtet. Über eine Webseite kann jeder auf den empfangenen Downlink zugreifen. Von Interesse ist dabei die Webseite für den Downlink des Schmalbandtransponder.\cite{OnlineMonitor}\newline
Als Antenne wird eine $1.3\,\text{m}$ Parabolantenne von Hirschmann verwendet, wobei das genaue Modell nicht benannt wird. Eine ähnlich wirkende Antenne mit gleichen Durchmesser und Hersteller weißt bei einer Frequenz von $11.5\,\text{GHz}$ einen Gewinn von $G_\mathrm{R,Goonhilly}=40.2\,\text{dBi}$ auf\cite{Empfangssystem_Goonhilly}\cite{Hirschmann}. Bei dem eingesetzten rauscharmen Signalumsetzer (LNB) handelt es sich Octagon Quad OQSLO Green LNB. Dieser verstärkt die empfangenen Signale um $G_\mathrm{LNB}=60-65\,\text{dB}$ und setzt diese anschließend in ein niedrigeres Frequenzband um.\cite{Octagon}\newline
Als Software Defined Radio wird ein AirSpy SDR verwendet, wobei es sich wahrscheinlich um einen AirSpy R2 handelt. Für diesen konnte keine Verstärkungsparameter ermittelt werden, weshalb von einer Verstärkung von $G_\mathrm{SDR,Goonhilly}=0\,\text{dB}$ ausgegangen wird.\cite{Empfangssystem_Goonhilly}\cite{Airspy_R2}\newline
Im ersten Schritt kann die von der Antenne empfangene Leistung $P_\mathrm{R}$ verglichen werden. Dafür müssen zunächst die Dämpfungen in der Übertragungsstrecke von Es'Hail-2 (QO-100) zu der Goonhilly Bodenstation ermittelt werden. Die größten Einfluss hat die Freiraumdämpfung $L_\mathrm{FR}$, welcher von der Entfernung $D_\mathrm{SAT,Goonhilly}$ des Satelliten zu der Bodenstation abhängig ist.\newline
Die Goonhilly Bodenstation befindet sich an den Koordinaten $50.05\degree,-5.18\degree$. Mithilfe der Koordinaten kann die Entfernung zum Satelliten und damit auch die Freiraumdämpfung bestimmt werden werden. Vorgegangen wird dabei wie in Abbildung \ref{fig:EntfernungEsHail2}.
\begin{equation*}
    h=r_\mathrm{0}\cdot \sin(\alpha)=6378\,\text{km}\cdot \sin(50.05\degree)=4889.41\,\text{km}
\end{equation*}
Mit der Höhe $h$ wird die Höhe der Bodenstation über dem Äquator angegeben. Mithilfe dieser Höhe kann mit dem Satz des Pythagoras der Teilradius $r_\mathrm{01}$ bestimmt werden.
\begin{equation*}
    r_\mathrm{01}=\sqrt{r_\mathrm{0}^2- h^2}=\sqrt{(6378\,\text{km})^2-(4889.41\,\text{km})^2}=4095.43\,\text{km}
\end{equation*}
Über den Teilradius $r_\mathrm{01}$ kann der Teilradius $r_\mathrm{02}$ bestimmt werden.
\begin{equation*}
    r_\mathrm{02}=r_\mathrm{0}-r_\mathrm{01}=6378\,\text{km}-4889.41\,\text{km}=1488.6\,\text{km}
\end{equation*}
Im letzten Schritt wird mit der Höhe $h$, dem zusammengesetzten Radius $r+r_\mathrm{02}$ der Umlaufbahn von Es'Hail-2 (QO-100) zu der Bodenstation, die Entfernung $D_\mathrm{SAT,Goonhilly}$ zwischen der Bodenstation und Es'Hail-2 (QO-100) bestimmt.
\begin{equation}
    \begin{split}
      D_\mathrm{SAT,Goonhilly}&=\sqrt{h^2+(r+r_\mathrm{02})^2}\\
    &=\sqrt{(4095.43\,\text{km})^2+(35790\,\text{km}+1488.6\,\text{km})^2}\\
    &=37502.89\,\text{km}
    \end{split}
\end{equation}
Verglichen mit der Entfernung von der Bodenstation am IAT aus $D_\mathrm{SAT}=38676\,\text{km}$ ist die Bodenstation bei Goonhilly $D_\mathrm{SAT,Goonhilly}=37502.89\,\text{km}$ etwas geringer. Die geringere Entfernung wird zu einer geringeren Freiraumdämpfung $L_\mathrm{FR}$ führen. Diese kann mit Gleichung \ref{eq:Freiraumdämpfung} und einer Wellenlänge $\lambda =\frac{c}{f_\mathrm{center}}=\frac{3\cdot 10^8\,\text{m/s}}{10489.750\,\text{MHz}}=0.0286\,\text{m}$ bestimmt werden.
\begin{equation}
    L_\mathrm{FR}=20\cdot \log_{10}\left(\frac{4\pi\cdot D_\mathrm{SAT,Goonhilly}}{\lambda}\right)=20\cdot \log_{10}\left(\frac{4\pi\cdot 37502.89\,\text{km}}{0.0286\,\text{m}}\right)=204.34\,\text{dB}
    \label{eq:Freiraumdämpfung-Goonhilly}
\end{equation}
Im Vergleich zur Freiraumdämpfung zur Bodenstation am IAT $L_\mathrm{FR}=204.61\,\text{dB}$ ist die Dämpfung zur Bodenstation in Goonhilly mit $L_\mathrm{FR}=204.34\,\text{dB}$ um $0.27\,\text{dB}$ geringer. Diese Differenz wird sich aber nicht groß auf die empfangene Leistung auswirken.\newline
Weitere Verluste treten durch die Fehlausrichtung von Sende- und Empfangsantenne aufeinander aus. Diese können mit der Gleichung \ref{eq:Berechnung-Fehlausrichtung-Sender}, bzw. mit \ref{eq:Berechnung-Fehlausrichtung-Empfänger} bestimmt werden. Der Winkel der Fehlausrichtung auf der Seite des Senders $\theta_\mathrm{T}$ entspricht dem Winkel $\beta$ in Abbildung \ref{fig:EntfernungEsHail2}. Dieser kann mit der Entfernung $r+r_\mathrm{02}$ und der Entfernung $D_\mathrm{SAT,Goonhilly}$ bestimmt werden.
\begin{equation*}
    \theta_\mathrm{T}=\beta=\arccos\left( \frac{r+r_\mathrm{02}}{D_\mathrm{SAT,Goonhilly}}\right) = \arccos\left( \frac{35790\,\text{km}+1488.6\,\text{km}}{37502.89\,\text{km}}\right)=6.26\degree
\end{equation*}
Mit dem Winkel $\theta_\mathrm{T}$ kann der Verlust durch die sendeseitige Fehlausrichtung bestimmt werden.
\begin{equation}
    L_\mathrm{\theta T}=12\cdot\left( \frac{\theta_\mathrm{T}}{\theta_\mathrm{3dB}}\right)^2=12\cdot\left( \frac{6.26\degree}{17.4\degree}\right)^2=1.91\,\text{dB}
    \label{eq:Fehlausrichtung-Sender-Goonhilly}
\end{equation}
Der Winkel der empfangsseitigen Fehlausrichtung kann, wie bei der Bodenstation am IAT, mit $\theta_\mathrm{R}=1\degree$ angenommen werden.
\begin{equation}
    L_\mathrm{\theta R}=12\cdot\left( \frac{\theta_\mathrm{R}}{\theta_\mathrm{3dB}}\right)^2=12\cdot\left( \frac{1\degree}{17.4\degree}\right)^2=0.69\,\text{dB}
    \label{eq:Fehlausrichtung-Empfänger-Goonhilly}
\end{equation}
Durch die geringere Entfernung $D_\mathrm{SAT,Goonhilly}$ zum Satelliten sinkt der Winkel der Fehlausrichtung zwischen der Sende- und der Empfangsantenne, was zur einer Reduzierung der Verluste führt. Im Vergleich zu den Verlusten der sendeseitigen Fehlausrichtung des Empfangssystems am IAT $L_\mathrm{\theta T}=5.23\,\text{dB}$, sind die Verluste an der Goonhilly Bodenstation $L_\mathrm{\theta T}=1.91\,\text{dB}$ um $3.32\,\text{dB}$ geringer. Das wird zu einer Verdopplung der empfangenen Leistung $P_\mathrm{R}$ gegenüber dem Empfangssystem am IAT führen.\newline
Für die Dämpfung durch die Atmosphäre wird die Bedingung klarer Himmel verwendet, da zum Zeitpunkt des Vergleiches der theoretischen Empfangsparameter des Empfangssystem am IAT mit den erreichten Empfangsparameter des Empfangssystems an der Goonhilly Bodenstation ein Wolkenfreier Himmel, sowie kein Regen vorhergesagt gewesen sind. Daher wird die Dämpfung durch die Atmosphäre mit $L_\mathrm{ATklarerHimmel}=0.547\,\text{dB}$ aus Gleichung \ref{eq:Dämpfung-in-der-Atmosphäre-klarer-Himmel} angenommen. Zusammen mit der in Gleichung \ref{eq:Freiraumdämpfung-Goonhilly} Freiraumdämpfung, den Verlusten durch Fehlausrichtung \label{eq:Fehlausrichtung-Sender-Goonhilly} und \label{eq:Fehlausrichtung-Empfänger-Goonhilly}, sowie der Dämpfung in der Atmosphäre bei klaren Himmel in \ref{eq:Dämpfung-in-der-Atmosphäre-klarer-Himmel} und einem Antennengewinn $G_\mathrm{R,Goonhilly}=40.2\,\text{dBi}=10471.29$, kann mit Gleichung \ref{eq:empfangene-Leistung} die empfangene Leistung $P_\mathrm{R}$ bestimmt werden. Das $EIRP$ von Es'Hail-2 (QO-100) ist in Tabelle \ref{tab:LinkBudet-EsHail-2} mit $EIRP=891.25\,\text{W}$ angegeben.
\begin{equation}
\begin{split}
        P_\mathrm{R}&=EIRP\cdot G_\mathrm{R,Goonhilly}\cdot \frac{1}{L_\mathrm{FR}}\cdot \frac{1}{L_\mathrm{\theta T}} \cdot \frac{1}{L_\mathrm{\theta R}} \cdot \frac{1}{L_\mathrm{ATklarerHimmel}}\\
        &=891.25\,\text{W}\cdot 10471.29\cdot \frac{1}{2.72\cdot 10^{20}}\cdot\frac{1}{1.55}\cdot \frac{1}{1.17}\cdot \frac{1}{1.13}\\
        &=1.67\cdot 10^{-14}\,\text{W}=-107.77\,\text{dBm}
\end{split}
\label{eq:Empfangene-Leistung-Goonhilly}
\end{equation}
Wie erwartet ist die empfangene Leistung an der Goonhilly Bodenstation mit $P_\mathrm{R}=-107.77\,\text{dB}$ um $2.9\,\text{dB}\approx3\,\text{dB}$ größer als die empfangene Leistung $P_\mathrm{R}=-110.67\,\text{dBm}$ des Empfangssystems am IAT. Grund die dafür sind die niedrigeren Verluste der sendeseitigen Fehlausrichtung $L_\mathrm{\theta T}$, welche mit der geographischen besseren Lage der Goonhilly Bodenstation erklärt werden können.\newline
Mithilfe der Verstärkung von $G_\mathrm{LNB,max}=65\,\text{dB}$ kann die Leistung am Ausgang  $P_\mathrm{RX}$ des Goonhilly Empfangssystems rechnerisch bestimmt werden.
\begin{equation}
    P_\mathrm{RX}=P_\mathrm{R}+ G_\mathrm{LNB,max}=-107.77\,\text{dBm}+65\,\text{dB}=-42.77\,\text{dBm}
    \label{eq:theoretische-Ausgangsleistung-Goonhilly}
\end{equation}
Die Leistung am Ausgang des Empfangssystem in Goonhilly ist mit $P_\mathrm{RX}=-42.77\,\text{dBm}$ um $0.28\,\text{dB}$ höher, als die Leistung am Ausgang $P_\mathrm{RX,real}=-43.05\,\text{dBm}$ des Empfangssystems am IAT. Grund dafür ist die nicht optimale Ausrichtung der Antenne am IAT auf den Satelliten. In der Theorie ist eine Ausgangsleitung von $P_\mathrm{RX}=-31.18\,\text{dBm}$ des Empfangssystem am IAT möglich. Die Differenz würde dann $11.59\,\text{dB}$ betragen. Grund für die in der Theorie größere Leistung am Ausgang ist die größere Verstärkung $G_\mathrm{sys}=79.49\,\text{dB}$, verglichen mit der Verstärkung $G_\mathrm{LNB,max}=65\,\text{dB}$ des Empfangssystem an der Goonhilly Bodenstation, des Empfangssystem am IAT.\newline
\begin{figure}[H]
    \centering
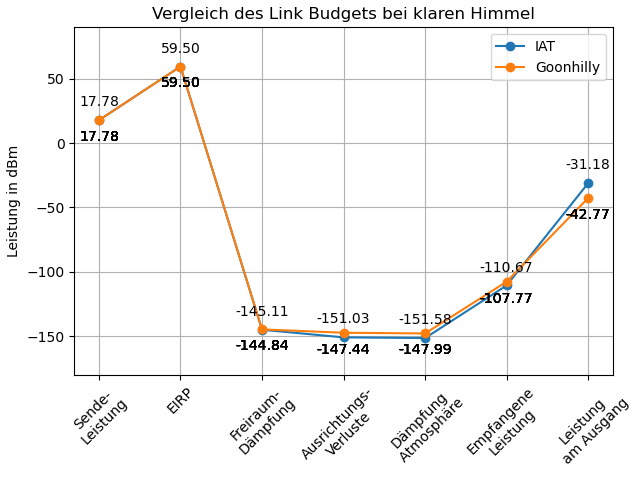
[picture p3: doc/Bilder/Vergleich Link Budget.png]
    
    \caption{Vergleich des theoretischen Link Budgets des Empfangssystems an der Goonhilly Bodenstation (orange) und am IAT (blau).}
    \label{fig:Vergleich-Link-Budget}
\end{figure}
In der Abbildung \ref{fig:Vergleich-Link-Budget} ist, zum besseren Vergleichen, das ermittelte Link Budget des Empfangssystems an der Goonhilly Bodenstation (orange) und das theoretische Link Budget des Empfangssystems am IAT (blau) dargestellt. Das verwendete Python-Skript ist im GitHub-Repository und im Anhang unter \ref{lst:Vergleich-Link-Budget} hinterlegt. Die Werte des Empfangssystem in Goonhilly sind unter den Linien und die Werte des Empfangssystems am IAT sind über den Linien dargestellt. Die Unterschiede machen sich ab der Übertragungsstrecke bemerkbar. Durch die geographische bessere Lage zu Es'Hail-2 (QO-100) ist die Freiraumdämpfung $L_\mathrm{FR}$, im Vergleich zum Link Budget des Empfangssystems an der IAT Bodenstation, um $0.27\,\text{dB}$ oder um $6\%$ geringer. Die geographisch bessere Lage des Empfangssystems an der Goonhilly Bodenstation hat auch niedrigere Verluste durch die Fehlausrichtung auf Seite des Senders $L_\mathrm{\theta T}$ zur Folge. Im Vergleich zu den Verlusten der senderseitigen Fehlausrichtung des Empfangssystems an der IAT Bodenstation $L_\mathrm{\theta T}=5.23\,\text{dB}$ sind die Verlusten der senderseitigen Fehlausrichtung des Empfangssystems in Goonhilly mit $L_\mathrm{\theta T}=1.91\,\text{dB}$ um $3.32\,\text{dB}$ geringer, was zu einer Verdopplung der empfangenen Leistung $P_\mathrm{R}=-107.77\,\text{dBm}$ gegenüber der empfangenen Leistung des Empfangssystems an der IAT Bodenstation $P_\mathrm{R}=-110.67\,\text{dBm}$ führt. Auch ist der Gewinn $G_\mathrm{R,Goonhilly}=40.2\,\text{dBi}$ der Antenne des Goonhilly Empfangssystems um $0.6\,\text{dB}$ höher, als der Antennengewinn $G_\mathrm{R,IAT}=38.6\,\text{dBi}$ der Antenne des Empfangssystems am IAT, was mit der größeren Antennenfläche erklärt werden kann. Auch das führt zu einer Erhöhung der empfangene Leistung $P_\mathrm{R}$ des Empfangssystem in Goonhilly. Durch die größere Verstärkung $G_\mathrm{sys}=79.49\,\text{dB}$ des Empfangssystems am IAT, ist die Ausgangsleistung mit $P_\mathrm{RX}=-31.18\,\text{dBm}$ um  $11.59\,\text{dB}$ größer, als die Ausgangsleistung $P_\mathrm{RX}=-42.77\,\text{dBm}$ des Empfangssystems an der Goonhilly Bodenstation.\newline
Eine messtechnische Ermittlung der Ausgangsleistung des Empfangssystem an der Goonhilly Bodenstation ist nicht möglich. Der Leistungsmesser auf der Weboberfläche gibt nur Werte in dB ohne Bezug an. Ebenfalls kann das die Rauchleistung am Ausgang des Empfangssystems und damit auch der Signal-zu-Rauschabstand $SNR_\mathrm{o,Goonhilly}$ nicht bestimmt werden, da keine Information zum Eigenrauschen des Empfangssystems vorhanden sind. Auch kann ohne die äquivalente Rauschtemperatur $T_\mathrm{e,Goonhilly}$ die Empfangsgüte der Bodenstation nicht ermittelt werden.

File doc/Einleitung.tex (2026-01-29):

Im heutigen Zeitalter sind Satelliten nicht mehr aus unseren Leben wegzudenken. Sie werden für die verschiedenste Dinge benötigt, wie Navigation zur Arbeit oder nächsten Urlaubsziel, für Rundfunk und Fernsehn, für Internet und für vieles mehr. Damit aus den Satelliten auch ein Nutzen gezogen werden kann, muss eine Kommunikationsmöglichkeit mit diesen bestehen. Hier für werden sogenannte Bodenstationen eingesetzt. Bodenstation werden zur Steuerung und Verfolgen der Satelliten, sowie zum Senden und Empfangen von Daten und Informationen von Satelliten eingesetzt.\newline
Zurzeit entsteht am Institut für Aerospace Technologie (IAT) eine Satellitenbodenstation. Für die ersten Versuche und Test eignen sich der Empfang von Satelliten in einer geostationären Umlaufbahn. Eine akktraktive Möglichkeit bietet dabei der Kommunikations- und Amateurfunksatellit Es'Hail-2, auch bekannt unter den Rufname Qatar Oscar 100 (QO-100). Neben dem Equipment zur kommerziellen Nutzung des Satelliten, befinden sich ebenfalls zwei Amateurfunktransponder an Bord von Es'Hail-2 (QO-100). Bei den beiden Transponder handelt es sich um einen Schmal- und Breitbandtransponder, welche von Amateurfunkern aus verschiedenen Länder für verschiedene Zwecke frei verwendet werden können.
\subsection{Motivation}
Schon seit längerer Zeit interessiere ich mich privat für Kommunikations- und Hochfrequenztechnik, sowie für Satelliten und Raumfahrt im Allgemeinen. In den letzten zwei Jahren hat sich dieses Interesse zunehmend auf den Bereich der Satellitenkommunikation konzentriert. Erste eigene Versuche, Signale und Bilder der NOAA-Wettersatelliten zu empfangen, haben mein technisches Interesse weiter vertieft.\newline
Daher war es mir ein besonderes Anliegen, für meine Bachelorarbeit ein Thema im Bereich der Kommunikations- und Hochfrequenztechnik beziehungsweise der Satellitenkommunikation zu wählen. Über Prof. Dr. Peik und Prof. Dr. García ergab sich schließlich die Möglichkeit, im Rahmen der entstehenden Bodenstation des IAT ein Empfangssystem für geostationäre Satelliten im X‑Band zu planen, zu entwickeln und aufzubauen.

\subsection{Zielsetzung und Vorgehen}
Diese Arbeit beschäftigt sich mit der Planung, Entwicklung und dem Aufbau einer Empfangsstation für den Downlink des Schmalbandtransponder auf Es'Hail-2 (QO-100), der sich im X-Band befindet. Ziel ist der Aufbau und die Inbetriebnahme eines funktionsfähigen Empfangssystems, sowie das erfolgreiche Empfangen und Dekodieren von Amateurfunksignalen.\newline
Zur Erreichung des Ziels werden im ersten Schritt der Schmalbandtransponder und der 
Satellit Es'Hail-2 (QO-100) genauer untersucht. Dabei werden die technischen Eigenschaften des Satelliten und des Downlink, sowie relevante Empfangsparameter recherchiert.\newline
Im zweiten Schritt wird der Downlink theoretisch betrachtet. Besonderer Fokus liegt dabei auf der Übertragungsstrecke zwischen dem Satelliten und der Bodenstation am IAT. Untersucht werden die verschiedenen Dämpfungen, welche in den unterschiedlichen Abschnitten der Übertragungsstrecke auftreten. Von besonderem Interesse sind dabei die Dämpfungen in der Atmosphäre bei verschiedenen Wetterbedingungen und deren Auswirkungen auf den Downlink. Auf Basis dieser Informationen kann dann anschließend ein geeignetes Empfangssystem geplant und entwickelt werden.\newline 
Hierzu wird zunächst eine an der Hochschule bereits vorhandene Satellitenschüssel auf ihre Eignung für den Empfang des Downlinks überprüft. Weiterhin muss ein geeigneter Antennenfeed zum empfangen des Downlink, ein Verstärker zur Anhebung der empfangenen Signale auf ein verarbeitbaren Pegel, ein Abwärtsmischer zur Umsetzung der empfangenen Signale vom X-Band in einen niedrigeren Frequenzbereich, sowie geeignete Koaxialleitungen für die unterschiedlichen Abschnitte des Empfangssystems gewählt werden. Die ausgewählten Komponenten müssen dabei mit dem bereits vorhandenen Equipment - einer RF-Schaltmatrix von Mini-Circuits, einem Patchfeld und einem USRP X310 Software Defined Radio - kompatibel sein.\newline
Im nächsten Schritt werden die Eigenschaften des geplanten Empfangssystems ermittelt. Dazu gehören die im RF-Bereich des Empfangssystems auftretenden Dämpfungen und Verluste, die erzielten Verstärkungen, sowie das Eigenrauschen der Komponenten und damit des gesamten Empfangssystems. Mit diesen Werten kann die Empfangsgüte und die theoretischen Empfangsparameter, wie empfangene Leistung, empfangenes Rauschen, Rauschleistung im Empfangssystem, Leistung am Ausgang, das Link Budget und die Qualität des Downlinks für unterschiedliche Wetterbedingungen ermittelt und miteinander verglichen werden. Auf dieser Grundlage kann eine Aussage über die Leistungsfähigkeit des entwickelten Empfangssystems getroffen werden.\newline
Abschließend wird der Aufbau des geplanten und entwickelten Empfangssystems dokumentiert und eine Software zur Steuerung des Software Defined Radio, sowie zur Dekodierung der unterschiedlichen Signale im Downlink mithilfe von GNU Radio entwickelt. Zu dem werden die in der Praxis erreichten mit den in der Theorie bestimmten Empfangsparameter verglichen, sowie das Link Budget des Empfangssystem am IAT mit dem Link Budget des Empfangssystem an der Goonhilly in Cornwall (England) Bodenstation verglichen.

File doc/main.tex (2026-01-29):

\documentclass[a4paper,11pt]{article}

% Pakete für Zeichencodierung und Spracheinstellungen
\usepackage[utf8]{inputenc}    % UTF-8 Zeichenkodierung
\usepackage[T1]{fontenc}       % Korrekte Darstellung von Umlauten

\usepackage[ngerman]{babel}    % Deutsche Spracheinstellungen
\usepackage{amsmath}
\usepackage{amssymb}
% Pakete für Layout und Formatierung
\usepackage{graphicx}          % Einbindung von Bildern
\usepackage{svg}               % Einbinden von .svg
\usepackage{geometry}          % Anpassung der Seitenränder
\usepackage{float}             % Exakte Positionierung von Abbildungen
\usepackage{fancyhdr}          % Anpassung von Kopf- und Fußzeilen
\usepackage{pdfpages}          % Für \includepdf
\usepackage{titlesec}          % Anpassung der Überschriftenformatierung
\usepackage{tocloft}           % Anpassung des Inhaltsverzeichnisses
\usepackage{hyperref}
\usepackage{gensymb}
\usepackage{tabularx}

\usepackage{listings}
\usepackage{xcolor}

\lstset{
  language=Python,
  basicstyle=\ttfamily\small,
  keywordstyle=\color{blue},
  commentstyle=\color{gray},
  stringstyle=\color{red},
  showstringspaces=false,
  breaklines=true
}

% Paket für das Literaturverzeichnis
\usepackage{csquotes}
\usepackage[backend=biber, style=ieee]{biblatex} % IEEE-Zitierstil mit Biber als Backend
\addbibresource{Literaturverzeichnis.bib}       % Einbindung der Literaturdatenbank

% Paket zur Nutzung der letzten Seitenzahl
\usepackage{lastpage} % Ermöglicht „Seite X von Y“-Format

% Seitenlayout
\geometry{
  top=2cm,    % Abstand zum oberen Rand
  bottom=3cm, % Abstand zum unteren Rand
  left=2.5cm, % Abstand zum linken Rand
  right=2.5cm % Abstand zum rechten Rand
}

% Kein Absatzeinzug
\setlength\parindent{0pt}

% Kopf- und Fußzeilen
\setlength\headheight{26pt}  % Höhe der Kopfzeile
\setlength\headsep{35pt}     % Abstand zwischen Kopfzeile und Text
\pagestyle{fancy}
\fancyhf{}
\lhead{Daniel Albinger (5183249)}
\chead{Bachelor Thesis}
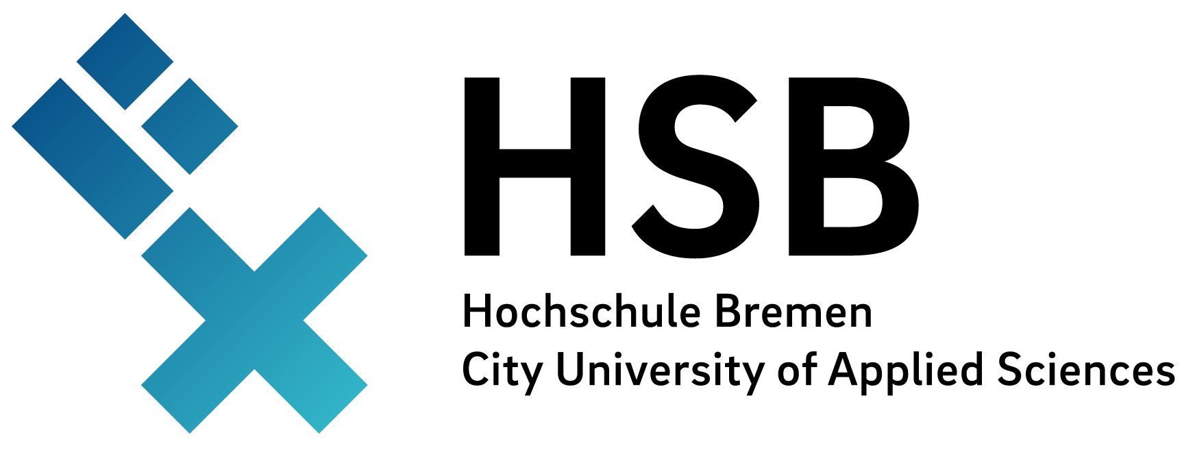
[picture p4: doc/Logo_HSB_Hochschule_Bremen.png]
\rhead{}
\cfoot{} % Keine Seitenzahl auf Titelseite und Inhaltsverzeichnis

\begin{document}

% Titelseite
\begin{titlepage}
    \centering
    \\[1cm]
    {\scshape\LARGE Hochschule Bremen\\}
    {\scshape\Large Fakultät 4: Elektrotechnik und Informatik\\[1.5cm]}
    {\huge\bfseries Bachelor Thesis\\[0.5cm]}
    {\vspace{20mm}}
    {\Large\bfseries Systems zum Empfang von Geostationären Satelliten durch die IAT Bodenstation\\[0.5cm]}
    {\Large\bfseries Daniel Albinger (5183249)\\[2cm]}
    {\Large\bfseries Prüfer\\[0.5cm]}
    \begin{tabular}{l}
    1. Prüfer: Prof.\ Dr.\ Peik \\ 
    2. Prüfer: Prof.\ Dr.\ García \\
    \end{tabular}\\[2cm]
    {\Large\bfseries Bearbeitungszeitraum:\\ 20. November 2025 bis 03. Februar 2026}\\[2cm]
    \vfill
\end{titlepage}

\newpage
\section*{Abstrakt}
Die Arbeit beschäftigt sich mit der Planung, Entwicklung und Umsetzung eines Empfangssystems für geostationären Satelliten mit einem Downlink im X-Band. Als Satellite bietet sich dabei der Amateurfunksatellit Es'Hail-2 (QO-100) an, welcher einen Schmal- und Breitbandtransponder mit Downlink im X-Band besitzt. In dieser Arbeit wird nur der Downlink des Schmalbandtransponder betrachtet.\newline
Neben der Untersuchung des Satelliten gehört zur Planung und Entwicklung des Empfangssystems die Auswahl der passenden Komponenten. Im Zuge dessen wird an der Hochschule vorhandene Antenne auf ihre Tauglichkeit überprüft, sowie neue notwendige Komponenten des Empfangssystems ausgewählt. Für die Auswahl der passenden Komponenten ist eine theoretische Betrachtung des Downlinks notwendig. Besonderer Fokus wird dabei auf die Übertragungsstrecke zwischen dem Satelliten und dem Standort des Empfangssystem am IAT gelegt. Insbesondere die Dämpfung in der Atmosphäre bei unterschiedlichen Wetterbedingungen - klarer Himmel, leichter Regen und Regen - und ihre Auswirkungen werden untersucht. Ermittelt werden konnten Dämpfungen für klaren Himmel von $L_\mathrm{ATklarerHimmel}=0.547\,\text{dB}$, leichter Regen von $L_\mathrm{ATleichterRegen}=0.947\,\text{dB}$ und bei starken Niederschlägen von $L_\mathrm{ATRegen}=9.61\,\text{dB}$. Diese haben ebenfalls Auswirkungen auf das Rauschen des Empfangssystem. Für das Eigenrauschen des Empfangssystems konnte eine äquivalente Rauschtemperatur $T_\mathrm{e,sys}=336.63\,\text{K}$ und eine Rauschzahl von $F_\mathrm{sys}=3.34\,\text{dB}$ ermittelt werden.\newline
Für die einzelen Wetterbedingungen wird anschließend das Link Budget und der Signal-zu-Rauschabstand am Ein- und Ausgang ermittelt womit eine Aussage über die Aufrechterhaltung des Downlinks getroffen werden kann. Dabei kommt raus, dass der Downlink auch bei starken Niederschlägen Aufrecht erhalten werden kann.\newline
Mit dem entwickelten und aufgebauten Empfangssystem am IAT ist es möglichen den Downlink des Schmalbandtransponder auf Es'Hail-2 (QO-100) zu empfangen. Jedoch ist die Leistung am Ausgang $P_\mathrm{RX}$ um $11.59\,\text{dB}$ geringer, als in der Theorie berechnet. Da die gemessene Rauschleistung nur um $0.93\,\text{dB}$ von der berechneten Rauschleistung abweicht, ist von einer nicht optimalen Ausrichtung der Antenne auf den Satelliten auszugehen.\newline
Zum Schluss hin werden die berechneten und gemessenen Empfangsparameter des Empfangssystem am IAT mit den Empfangsparameter mit einem Empfangssystem an der Goonhilly Bodenstation in Cornwall (England) verglichen. Die Empfangsparameter an der Goonhilly Bodenstation sind leicht besser, können aber mit der geographisch gesehen besseren Lage zum Satelliten und dem größeren Antennendurchmesser von $1.3\,\text{m}$ und damit verbundenen größeren Antennengewinn erklärt werden.

\newpage

\includepdf[pages=-]{KI-Eigenständigkeitserklärung.pdf}
\newpage

\section*{Danksagungen}
Ich möchte noch ein paar Danksagungen aussprechen. Zu einem möchte mich bei Herrn Prof. Dr. Peik und bei Herrn Prof. Dr. García für die möglich Machung der Arbeit, sowie für Hilfestellungen während der Arbeit bedanken.\newline
Ebenfalls möchte ich mich bei Tim Kruse für die Hilfe bei technischen Problemen mit dem Equipment, Bestellung der Komponenten, beim Aufbau des Empfangssystems, insbesondere bei der Montage und Ausrichtung der Antenne bedanken.\newline
Auch möchte ich mich bei Simon Cossens und Nils Renner für ihre Unterstützung und Ratschläge zur Problemlösung bedanken.

\newpage
% Inhaltsverzeichnis ohne Seitenzahl
\pagenumbering{gobble}  % Keine Seitenzahl auf Inhaltsverzeichnis
\tableofcontents

\newpage  

% Seitenzahlen beginnen hier im Format „Seite X von Y“

\pagenumbering{arabic}  
\setcounter{page}{1}  
\cfoot{Seite \thepage\ von \pageref{LastPage}}
\section{Einleitung}
\input{Einleitung}
\newpage
\section{Geschichte von Satelliten}
\input{Theorie_Satelliten}
\newpage
\section{Theorie und Grundlagen}
\input{Theorie}
\input{Theorie_Antennen}
\input{Rauschen}
\newpage
\section{Theoretische Betrachtung des Downlink von Es'Hail-2 (QO-100) zur Bodenstation am IAT}
\label{chap:Theoretische-Betrachtung-des-Downlinks}
\input{Theoretischer Aufbau des Downlinks}

\newpage
\section{Aufbau des Empfangssystems}
\input{Praktischer Aufbau der Empfangskette}
\newpage
\section{Auswerten und Vergleichen der Ergebnisse}
\input{Auswertung}
\newpage
\section{Zusammenfassung}
\input{Zusammenfassung}
\newpage
\section{Anhang}
\input{Anhang}

\end{document}

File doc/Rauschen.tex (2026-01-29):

\subsection{Rauschen}
In jedem System tritt neben dem gewünschten Nutzsignal $s(t)$, welches die gewünschte Informationen enthält, zusätzlich Rauschen auf. Einfach gesagt handelt es sich beim Rauschen um eine unerwünschte Form an Energie, welche auch als eine Signal $n(t)$ angesehen werden kann. Das Rauschsignal $n(t)$ überlagert das Nutzsignal $s(t)$ und erschwert so das Empfangen und die anschließende Weiterverarbeitung des Nutzsignals $s(t)$.\newline
Genauer betrachtet handelt es sich beim Rauschen um einen stochastischen Prozess. Das bedeutet, dass der Verlauf des Rauschens nicht periodisch und damit zufällig ist. Der Verlauf, sowie die Amplitude des Rauschens können nicht vorhergesagt werden. Zudem enthält Rauschen keine brauchbaren Informationen.\cite{HEUERMANN_2018}\newline
In der Planung und Entwicklung von Kommunikationssystemen spielt das Rauschen eine wichtige Rolle. Für eine problemlose Übertragung, Empfang und Weiterverarbeitung des Nutzsignals $s(t)$ muss zwischen der Leistung des Nutzsignals $P_\mathrm{Signal}$ und der Rauschleistung $P_\mathrm{Rausch}$ eine gewisse Differenz eingehalten werden. Das Verhältnis der Leistung des Signals $P_\mathrm{Signal}$ zu der Rauschleistung $P_\mathrm{Rausch}$ wird Signal-zu-Rausch-Abstand (engl. Signal-to-Noise-Ratio), kurz $SNR$, genannt.\newline
\begin{equation}
    \label{eq:SNR}
    SNR=\frac{P_{\text{Signal}}}{P_{\text{Rausch}}}=\frac{S}{N}
\end{equation}
Das SNR kann auch logarithmisch in dB angeben werden.
\begin{equation}
    \label{eq:SNRdB}
    SNR_{\text{dB}}=10\cdot \log_{10}\left(\frac{P_{\text{Signal}}}{P_{\text{Rausch}}}\right)=S_{\text{dB}}-N_{\text{dB}}
\end{equation}
Das $SNR$ ist ein Maß für die Qualität der Übertragung, Empfangs und Weiterverarbeitung des Nutzsignals $s(t)$. Auch wenn die Rauschleistung $N$ im Vergleich zur Leistung $S$ des Nutzsignals $s(t)$ sehr gering ist, ist die Rauschleistung $N$ letztendlich der limitierende Faktor in jedem Kommunikationssystem.\newline
Ist der Abstand zwischen der Signalleistung $S$ zum Rauschen $N$ und damit auch das $SNR$ zu gering, kann das Nutzsignal $s(t)$ eventuell nicht mehr einwandfrei vom Rauschen unterschieden werden. Das führt zu Fehlern in der Weiterverarbeitung oder zu Aussetzern in der Übertragung. Mit einem steigenden $SNR$ wird auch der Abstand zwischen der Signalleistung $S$ und Rauschleistung $N$ immer größer. Dadurch kann das Nutzsignal $s(t)$ besser vom Rauschen unterschieden werden und die Fehler in der Weiterverarbeitung und die Ausfallzeit in der Übertragung sinken.
\begin{figure}[H]
    \centering
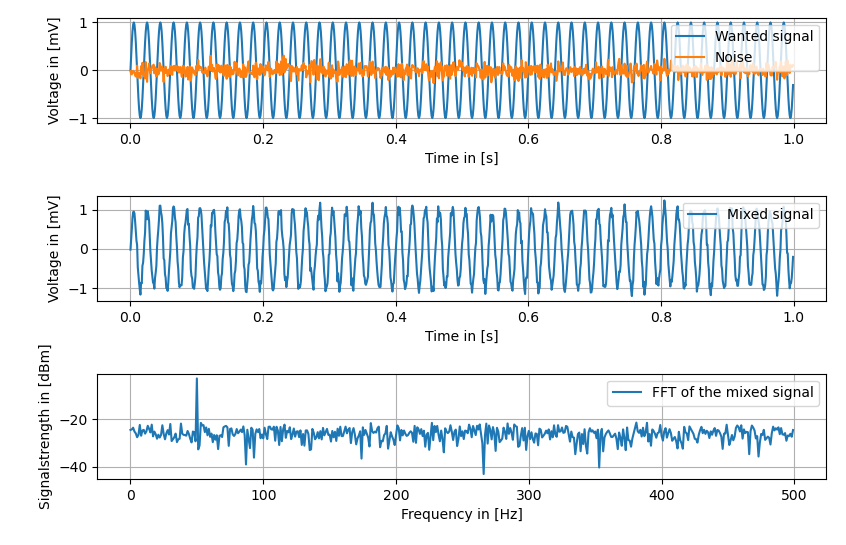
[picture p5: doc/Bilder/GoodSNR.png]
    
    \caption{Ein von Rauschen überlagertes Nutzsignal $s(t)$ mit einer Frequenz von $f=50\,\text{Hz}$ im Zeit- und Frequenzbereich}
    \label{fig:GoodSNR}
\end{figure}
Die Abbildung \ref{fig:GoodSNR} zeigt ein sinusförmiges Nutzsignal $s(t)$ mit einer Frequenz $f=50\,\text{Hz}$, welches von Rauschen überlagert wird. Der mittlere Plot zeigt die Kombination beider Signale im Zeitbereich. Das Rauschen hat einen geringfügigen Einfluss auf die Form des Nutzsignals, jedoch kann immer noch ein sinusförmiger Verlauf erahnt werden. Im unteren Plot ist das Frequenzspektrum des von Rauschen überlagerte Signal dargestellt. Hier ist Nutzsignal $s(t)$ bei $f=50\,\text{Hz}$, dank des hohen $SNR\approx20\,\text{dB}$, klar vom Rauschen unterscheidbar. 
\begin{figure}[H]
    \centering
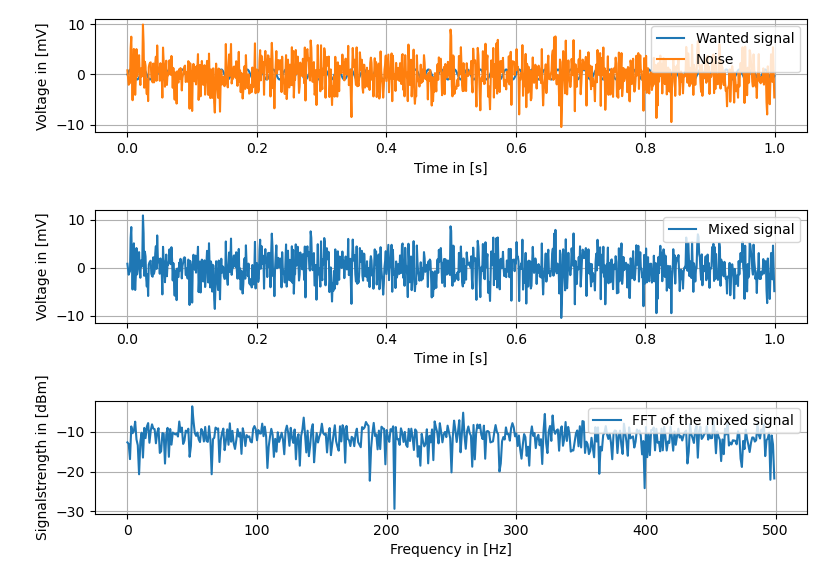
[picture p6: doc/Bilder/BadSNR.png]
    
    \caption{Das Nutzsignal $s(t)$ verschwindet im Rauschen}
    \label{fig:BadSNR}
\end{figure}
Die Abbildung \ref{fig:BadSNR} zeigt das gleiche Nutzsignal $s(t)$ wie in Abbildung \ref{fig:GoodSNR}. Jedoch ist Rauschen diesmal deutlich stärker. Im Zeitbereich hat das Rauschen nicht zu vernachlässigende Auswirkungen auf das Nutzsignal. Es kann eine sinusförmiger Verlauf des Nutzsignals erkannt werden. Auch im Frequenzspektrum kann das Nutzsignal $s(t)$ nicht vom Rauschen unterschieden werden.\newline
In diesem Fall wäre eine Weiterverarbeitung des Nutzsignals $s(t)$ nicht möglich, da es zu vielen Fehlern kommen würde. Bei digitalen Modulationen hängt die Bitfehlerrate (engl. Bit-error-rate) $BER$ vom $SNR$ ab.
\begin{figure}[H]
    \centering
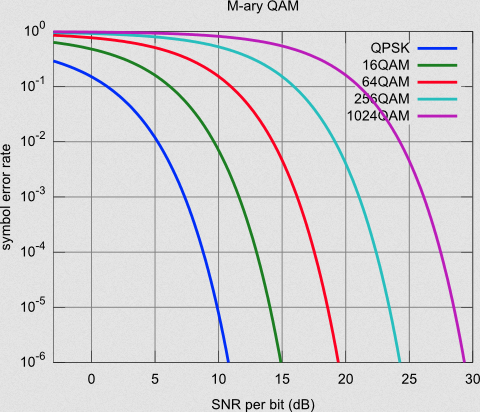
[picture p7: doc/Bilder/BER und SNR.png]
    
    \caption{Beispiel für die $BER$ anhand einer n-QAM\cite{Bild-BER}}
    \label{fig:BeispielBER}
\end{figure}
Die Abbildung \ref{fig:BeispielBER} zeigt die BER anhand für verschiedene QAM. Zu erkennen ist, dass bei steigendem $SNR$ die Fehlerrate immer stärker sinkt.\newline
Die Verteilung der Rauschleistung $N$ über das Frequenzspektrum wird mit dem Leistungsdichtespektrum $S_\text{N}(f)$ angegeben. Die Einheit des Leistungsdichtespektrum ist $\left[\frac{\text{W}}{\text{Hz}}\right]$. Herleiten lässt sich das Leistungsdichtespektrum mithilfe der Fouriertransformation aus der Autokorrelationsfunktion (AKF) und einer Normallast von $1 \Omega$.\cite{Thiede_2013}
\begin{equation}
    S_\text{N}(f)=\frac{N}{2\cdot B} = \frac{k\cdot T_\mathrm{0}}{2}=\frac{n_\text{0}}{2}
    \label{eq:PDS-Funktion}
\end{equation}
Dabei ist $n_\mathrm{0}$ das thermischen Grundrauschen. Bei Raumtemperatur $T_\mathrm{0}=290\,\text{K}$ beträgt das thermischen Grundrauschen $n_\mathrm{0}=1.38\cdot10^{-23}\,\frac{\text{J}}{\text{K}}\cdot 290\,\text{K}=4\cdot10^{-21}\text{J}=-174\,\frac{\text{dBm}}{\text{Hz}}$

\subsection{Arten und Quellen von Rauschen}
Rauschen kann sehr vielfältig sein. Es gibt viele verschiedene Arten an Rauschen, welches aus verschiedenen Quellen stammt und in den unterschiedlichsten Bereichen auftritt. Bei den Rauschquellen kann hauptsächlich zwischen natürlichen und künstlichen Rauschquellen unterschieden werden. Zu den natürliche Rauschquellen gehören unter anderem thermisches Rauschen, Schrotrauschen und 1/f-Rauschen. Aber auch Atmosphärisches- und kosmisches Hintergrundrauschen gehören mit zu den natürlichen Rauschquellen. Zum künstlichen Rauschen würde das Rauschen zählen, welches durch elektronische Geräte, z.B. bei der Spannungswandlung oder Datenübertragungen, erzeugt wird. Das künstliche Rauschen kann auch industrielles Rauschen genannt werden.
\subsubsection*{Thermisches Rauschen}
Alle Metalle und elektrische Bauteile, wie Widerstände und Halbleiter, erzeugen ab einer Temperatur $T_\mathrm{0}>0\,\text{K}$ eigenständig eine Rauschenergie. Dieses Rauschen wird auch als thermisches oder Gaußsches Rauschen bezeichnet.\newline
Zurückführen lässt sich das thermische Rauschen auf die zufällige Bewegung von Elektronen und Löchern innerhalb der Metalle und elektrischen Bauteile. Bei einer Temperatur $T_\mathrm{0}=0\,\text{K}$ stehen alle Ladungsträger. Damit wird auch kein Rauschen durch die Ladungsträger generiert. Ab einer Temperatur $T_\mathrm{0}>0\,\text{K}$ fangen die Ladungsträger an sich in zufällige Richtungen zu Bewegen, was zu der Entstehung von Rauschen führt.\cite{HEUERMANN_2018}\newline
\begin{figure}[H]
    \centering
    \includesvg[width=0.75\linewidth]{Bilder/thermal noise}
    \caption{Rauschspannung durch thermisches Rauschen}
    \label{fig:rauschspannung-thermischesRauschen}
\end{figure}
An den Anschlüssen eines Widerstandes oder einer anderen beliebigen Impedanz liegt aufgrund der Bewegung der Ladungsträger eine gewisse Spannung $U_{\text{Rausch}}$ an.\cite{HEUERMANN_2018} Das Rauschen kann als ein Signal $n(t)$ angesehen werden dessen Spannung $U_{\text{Rausch}}$ im Mittelwert 
\begin{equation*}
    \overline{U}_{\text{Rausch}}=\lim_{T\to\infty}\frac{1}{T}\int^T_0n(t)\space dt = 0
\end{equation*}
entspricht. Über den quadratische Mittelwert oder Niquist-Gleichung allerdings lässt sich der Effektivwert der Spannung ermitteln.\cite{NoiseFigur}\cite{Thiede_2013}\newline
\begin{equation*}
    U_\text{Rausch,eff.}=\sqrt{4\cdot k\cdot T_\mathrm{0}\cdot B\cdot R}
\end{equation*}
Über den Effektivwert $U_\text{Rausch,eff}$ der Spannung , welche auch Niquistgleichung genannt wird, lässt sich die Leistung des Rauschens ermitteln.\cite{NoiseFigur}
\begin{equation}
    N_\text{T}=P_\text{Rausch}= \frac{U_\text{Rausch,eff.}^2}{4R} = \frac{4R \cdot T_\mathrm{0}\cdot B}{4R}= k\cdot T_\mathrm{0}\cdot B
    \label{eq:thermisches-Rauschen}
\end{equation}
Die Leistung des thermischen Rauschen $N_\text{T}$ ist letztendlich unabhängig von dem Widerstand $R$ und nur noch abhängig von der Boltzmannkonstante $k=1,38\cdot 10^{-23}\,\frac{\text{J}}{\text{K}}$, der Temperatur $T_\mathrm{0}$ und der gewählten Bandbreite $B$.\cite{NoiseFigur}\cite{HEUERMANN_2018}\cite{Thiede_2013}\newline
Die Gleichung \ref{eq:thermisches-Rauschen} kann auch verwendet werden, um das von Zweitoren erzeugte Rauschen, z.B. am Ausgang eines rauscharmen Verstärkers, zu bestimmen. Die Temperatur $T_\mathrm{0}$ wird dabei durch die äquivalente Rauschtemperatur $T_\text{e}$ ersetzt.\cite{HEUERMANN_2018}\newline
Die Leistung des thermischen Rauschen ist unabhängig von der Frequenz $f$ und ist gleichmäßig über das gesamte Frequenzspektrum verteilt. Somit ist das Leistungsdichtespektrum $S_\text{N}(f)$ des thermischen Rauschens konstant. Damit handelt es sich beim thermischen Rauschen um sogenanntes weißes Rauschen\cite{Thiede_2013} Die thermische Rauschleistung $N_\text{T}$ in einem System steigt mit der gewählten Bandbreite $B$.

\subsubsection*{Schrotrauschen (Shot Noise)}
Erwähnt wird das Schrotrauschen erstmals von Schottky im Jahre 1918, weshalb es auch Schottky-Rauschen genannt wird. Auftreten tut das Schrotrauschen in Halbleiterbauelemente, wie z.B. Dioden, zusätzlich zum thermischen Rauschen.\cite{HEUERMANN_2018}\newline
Seinen Ursprung hat das Schrotrauschen in der zufälligen Bewegung von Ladungsträgern zwischen dem Leitungs- und Valenzband. Die damit verbundene Fluktuation von Energie erzeugt das Rauschen. Der energetische Abstand zwischen den beiden Bändern wird Potentialschwelle genannt.\cite{HEUERMANN_2018}\newline
\begin{figure}[H]
    \centering
    \includesvg[width=0.75\linewidth]{Bilder/Potentialschwelle}
    \caption{Darstellung der Potentialschwelle zwischen dem Leitungs- und Valenzband}
    \label{fig:Potentialschwelle}
\end{figure}
In einem Halbleiter erfolgt der Transport von Energie durch gequantelte Ladungsträger statt. Bei gequantelten Ladungsträgern handelt es sich um Teilchen, wie Elektronen oder Löcher, deren Ladung der elementar Ladung $e = 1.602 \cdot 10^{-19}\text{As}$ oder ein vielfaches davon entspricht.\cite{HEUERMANN_2018}\cite{leifiphysik-elementarladung}\newline
Das Schrotrauschen ist proportional zum mittleren fließenden Strom in dem jeweiligen Halbleiter. Da sich der mittlere fließende Strom je nach Halbleiter und Anwendung unterscheidet, muss das Schrotrauschen immer individuell betrachtet werden.\cite{HEUERMANN_2018}\cite{Thiede_2013}\newline

\subsubsection*{1/f-Rauschen (Flicker Noise)}
Das 1/f-Rauschen ist ein weiteres Rauschen, welches zusätzlich zum thermischen Rauschen und Schrotrauschen, vor allem in niedrigen Frequenzbereichen, auftritt. Es nicht nur limitiert auf elektronische Bauteile, sondern tritt auch in Musik, Biologie und in der Wirtschaft auf.\cite{Analog-Devices-Flicker-Noise}\newline
Beim 1/f-Rauschen handelt es sich um sogenanntes pinkes Rauschen\cite{liquid-flicker}. Anders als beim weißen Rauschen, wie thermisches Rauschen, welches eine gleichbleibende Leistungsdichte $S(f)$ über das gesamte Frequenzspektrum aufweist, nimmt beim 1/f-Rauschen die Leistungsdichte $S(f)$ mit steigender Frequenz $f$ immer weiter abnimmt. Daher stammt auch der Name 1/f-Rauschen.\cite{liquid-flicker}
\begin{figure}[H]
    \centering
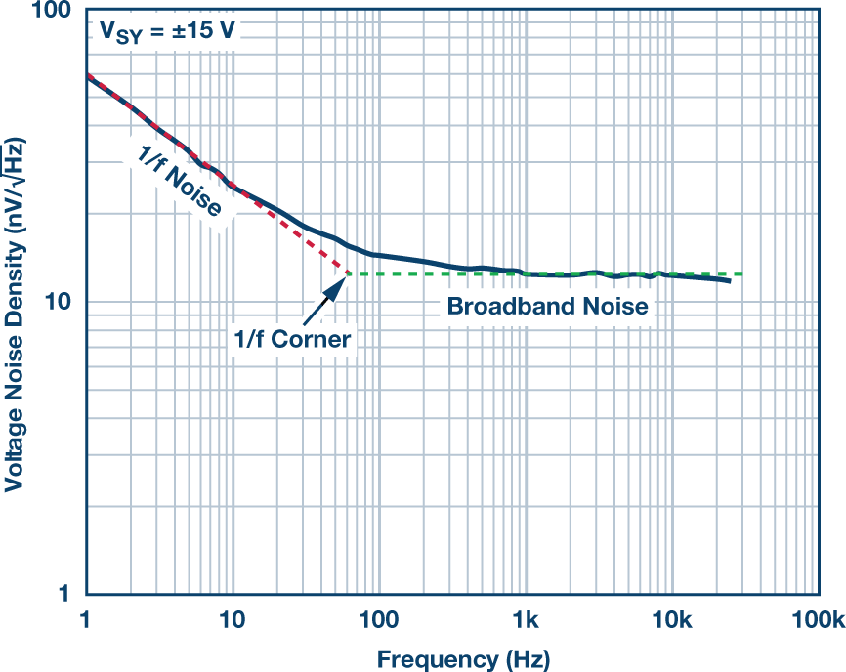
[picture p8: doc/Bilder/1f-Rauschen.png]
    
    \caption{Darstellung des 1/f-Rauschen eines ADA4622-2\cite{Analog-Devices-Flicker-Noise}}
    \label{fig:1/f-Rauschen}
\end{figure}
Der Graph in Abbildung \ref{fig:1/f-Rauschen} zeigt den Verlauf des 1/f-Rauschens eines ADA4622-2 mit zunehmender Frequenz $f$. Im niedrigen Frequenzbereich $f\leq60\,\text{Hz}$ dominiert die Leistungsdichte $S(f)$ des 1/f-Rauschen gegenüber dem thermischen Rauschen. Ab einer Grenzfrequenz $f_\mathrm{c}=60\,\text{Hz}$ geht das 1/f-Rauschen langsam im thermischen Rauschen unter.\cite{Thiede_2013} \cite{HEUERMANN_2018}\newline
Die Leistungsdichte $S(f)$ und die Grenzfrequenz $f_\text{c}$ des 1/f-Rauschen unterscheiden sich je nach Halbleitermaterial, z.b. Germanium und Silizium, und Bauelement, wie z.B. Diode oder MOSFET.\cite{HEUERMANN_2018}\newline
Eine genaue Erklärung für das 1/f-Rauschen gibt es nicht\cite{HEUERMANN_2018}\cite{Analog-Devices-Flicker-Noise}. Es gibt aber verschiedene Theorien zur Entstehung des 1/f-Rauschen. Eine einfache Theorie besagt, dass ein Transistor in tiefen Frequenzen mit das Rauschen mit einer Verstärkung $G=\frac{1}{f}$ verstärkt und so das Grundrauschen anhebt\cite{HEUERMANN_2018}. Eine weitere Theorie zur Quelle des 1/f-Rauschen besagt, dass das 1/f-Rauschen aus der zufälligen Bewegung der Ladungsträger und der damit verbundenen Änderung der Ladungsträgerkonzentration hervorgeht. Diese Fluktuationen der Energie entstehen durch Defekte in der Gitterstruktur des Halbleiters. Auftreten tun diese Defekte überwiegend an der Oberfläche des Halbleiters, auch Interface genannt. Die Ladungsträger werden von diesen Defekten \dq gefangen\dq{} oder \dq freigelassen\dq{} (engl. trapping und detrapping). Dieser Vorgang soll zum Rauschen führen.\cite{liquid-flicker}\cite{Thiede_2013}\newline
Auch wenn das 1/f-Rauschen nur niedrigen Frequenzbereich auftrifft, muss es auch für Anwendungen in höheren Frequenzbereichen berücksichtigt werden. Durch die nichtlineare Eigenschaften von nichtlinearen Bauteilen, wie z.B. Dioden, welche auch in einem Mischer eingesetzt werden um Signale in verschiedene Frequenzbereiche umzusetzen, kann auch das Rauschen durch den Prozess der Frequenzumsetzung in höheren Frequenzbereiche umgesetzt werden und den Rauschpegel anheben.\cite{HEUERMANN_2018}

\subsubsection*{Äquivalente Rauschtemperatur}
Bei der äquivalenten Rauschtemperatur $T_\mathrm{e}$ handelt es sich nicht um eine physikalische Temperatur, sondern um eine rein fiktive Erhöhung der Temperatur, welche als Rechengröße verwendet wird.\newline
Mit den bisherigen Erkenntnissen lässt sich schlussfolgern, das jedes Bauteil, egal ob Widerstand oder Halbleiter, rauscht. Auf Bauteilebene kann das Rauschen in seinen einzelnen Formen mit thermischen Rauschen, 1/f-Rauschen, Schrotrauschen, etc. beschrieben werden. In komplexeren Schaltungen kann die Beschreibung des Rausches in all seinen verschiedenen Formen sehr aufwendig werden. Mithilfe einer äquivalente Rauschtemperatur $T_\text{e}$ lässt sich das Rauschen eines einzelnen Bauteils, Zweitores oder ganzen Systemen in einer theoretischen Erhöhung der Temperatur ausdrücken.\newline
\begin{figure}[H]
    \centering
    \includesvg[width=0.75\linewidth]{Bilder/Äquivalente Rauschtemperatur}
    \caption{Beispiel für die Äquivalente Rauschtemperatur}
    \label{fig:Beispiel-Äquivalente-Rauschtemperatur}
\end{figure}
Die Grafik in Abbildung \ref{fig:Beispiel-Äquivalente-Rauschtemperatur} zeigt ein Beispiel für die äquivalente Rauschtemperatur $T_\mathrm{e}$. Die Grafik zeigt ein Zweitor, an wessen Eingang die Rauschleistung $N_\mathrm{i}=k\cdot T_\mathrm{0}\cdot B$ anliegt. Dabei wird von einer angepassten Rauschquelle ausgegangen. Das zusätzliche Rauschen des Zweitors wird in der Rauschleistung am Ausgang $N_\mathrm{o}=k\cdot(T_\mathrm{0}+T_\mathrm{e})\cdot B\cdot G$ durch die fiktive Erhöhung der Temperatur um $T_\mathrm{e}$ ausgedrückt. Ebenfalls wird die Verstärkung $G$ des Zweitores berücksichtigt.\cite{Thiede_2013}
\begin{equation}
    N_\mathrm{o}= k \cdot (T_\text{e}+T_\text{0}) \cdot B \cdot G
    \label{eq:Rauschleistung-Ausgang-Zweitor}
\end{equation}
Bei der fiktiven Erhöhung der Temperatur $T_\mathrm{0}$ um $T_\mathrm{e}$ handelt es sich in Summe genau um die Temperatur, bei welcher am Ausgang des Zweitors rechnerisch genau die Rauschleistung $N_\mathrm{o}$ anliegt, welche bei der tatsächlich Temperatur $T_\mathrm{0}$ des Systems gemessen wird.\cite{Thiede_2013}
Die äquivalente Rauschtemperatur $T_\text{e}$ kann umgekehrt auch aus der Rauschleistung $N_\mathrm{o}$ am Ausgang des Zweitores gewonnen werden.
\begin{equation}
    T_\mathrm{e}=\frac{N_\mathrm{o}}{k\cdot B \cdot G}-T_\mathrm{0}
    \label{eq:Äquivalente Rauschtemperatur}
\end{equation}
Die Summe $(T_\mathrm{0}+T_\mathrm{e})$ wird Rauschtemperatur $T_\mathrm{R}$, bestehend aus der physikalischen Temperatur $T_\mathrm{0}$ des Systems und der äquivalenten Rauschtemperatur $T_\mathrm{e}$. Die Rauschtemperatur $T_\mathrm{R}$ ist immer größer als die physikalische Temperatur $T_\mathrm{0}$, da kein reales Zweitor frei von Rauschen ist und somit $T_\mathrm{e}>0\,\text{K}$.\cite{Thiede_2013}
\subsubsection*{Rauschzahl}
Die Rauschzahl $F$ gibt an, wie stark das $SNR$ durch das jeweilige Zweitor verschlechtert wird. Bei Raumtemperatur $(T_\mathrm{0}=290\,\mathrm{K})$ entspricht die Rauschzahl $F$ dem Verhältnis vom $SNR_\mathrm{in}$ am Eingang des Zweitors, zum $SNR_\mathrm{out}$ am Ausgang des Zweitores.\cite{HEUERMANN_2018}
\begin{equation}
    F=\frac{SNR_\mathrm{in}}{SNR_\mathrm{out}}
    \label{eq:Rauschzahl-bei-T0}
\end{equation}
Bei der Weiterführung der Gleichung \ref{eq:Rauschzahl-bei-T0} kann die Rauschzahl $F$ nur mithilfe der physikalischen Temperatur $T_\mathrm{0}$ und der äquivalenten Rauschtemperatur $T_\mathrm{e}$ des Zweitores bestimmt werden.
\begin{equation}
        F=\frac{SNR_\mathrm{in}}{SNR_\mathrm{out}}=\frac{\frac{S_\mathrm{in}}{k\cdot T_\mathrm{0}\cdot B}}{\frac{S_\mathrm{in}\cdot G}{k\cdot (T_\mathrm{0}+T_\mathrm{e})\cdot B \cdot G}}=\frac{T_\mathrm{0}+T_\mathrm{e}}{T_\mathrm{0}}=1+\frac{T_\mathrm{e}}{T_\mathrm{0}}
    \label{eq:Rauschzahl-aus-Te-und-T0}
\end{equation}
Ein ideales Zweitor hat eine äquivalente Rauschtemperatur $T_\mathrm{e}=0\,\text{K}$, was mit der Gleichung \ref{eq:Rauschzahl-aus-Te-und-T0} zu einer Rauschzahl $F=1$ führt. Da jedes reale Zweitor rauscht, ist die äquivalente Rauschtemperatur $T_\mathrm{e}>\mathrm{0\,\text{K}}$ und damit die Rauschzahl $F>1$.\newline
Die Gleichung \ref{eq:Rauschzahl-aus-Te-und-T0} zeigt auch, dass jedes reale Zweitor zwangsläufig das $SNR$ verschlechtert. Damit ein Zweitor ein größeres $SNR_\mathrm{out}$ am Ausgang aufweist, als das $SNR_\mathrm{in}$ am Eingang des Zweitores, müsste es eine äquivalente Rauschtemperatur $T_\mathrm{e}<0\,\text{K}$ aufweisen. Da das physikalisch nicht möglich ist, verschlechtert jedes reale Zweitor zwangsläufig das $SNR$.\cite{HEUERMANN_2018}\newline
Ebenfalls kann die Rauschzahl logarithmisch in $[\text{dB}]$ angegeben werden.
\begin{equation}
    F_\mathrm{dB}=10\cdot\log_{10}\left(1+\frac{T_\mathrm{e}}{T_\mathrm{0}}\right)
    \label{eq:Rauschzahl-dB}
\end{equation}
Die Rauschzahl $F$ passiver Zweitore, wie z.B. Koaxialleitungen, Dämpfungsglieder, etc., ist gleich ihrem Verlust $L$.\cite{HEUERMANN_2018}
\begin{equation}
    F=\frac{1}{G}=L
    \label{eq:Rauschzahl-passives-Zweitor}
\end{equation}
Auch lässt sich in einem $50\,\Omega-\text{System}$ die Rauschzahl $F$ direkt aus den S-Parametern, genauer der Einfügedämpfung $S_\mathrm{21}$, bestimmen.\cite{HEUERMANN_2018}
\begin{equation}
    F_\mathrm{dB}=-S_\mathrm{21,dB}=20\cdot\log_{10}\left(\frac{1}{|S_\mathrm{21}|}\right)
\end{equation}
Bei der Verschaltung mehrere Zweitore ergibt sich für das Gesamtsystem eine Gesamtrauschzahl $F_\mathrm{ges}$, sowie eine gesamte äquivalente Rauschtemperatur $T_\mathrm{e,ges}$. Je nach Verschaltung der Zweitore wird die Rauschzahl $F_\mathrm{ges}$ und die Äquivalente Rauschtemperatur $T_\mathrm{e,ges}$ des Gesamtsystems unterschiedlich bestimmt.\newline
\begin{figure}[H]
    \centering
    \includesvg[width=0.7\linewidth]{Bilder/Kettenschaltung Zweitore}
    \caption{Kaskadierung von mehreren Zweitoren}
    \label{fig:Kettenschaltung-Zweitore}
\end{figure}
Beim Kaskadieren von mehreren Zweitoren, wie in Abbildung \ref{fig:Kettenschaltung-Zweitore} dargestellt, setzt sich die Gesamtrauschzahl $F_\mathrm{ges}$ aus der Summe der Rauschzahlen $F_\mathrm{x}$, wobei $x=1,2,3,\dots$, der einzelnen Zweitore, sowie deren Verstärkungen $G_\mathrm{x}$, zusammen.\cite{HEUERMANN_2018}
\begin{equation}
    F_\mathrm{ges}=F_\mathrm{1}+\frac{F_\mathrm{2}-1}{G_\mathrm{1}}+\frac{F_\mathrm{3}-1}{G_\mathrm{1}\cdot G_\mathrm{2}}+\dots
    \label{eq:Gesamtrauschzahl-Kaskade}
\end{equation}
Die äquivalente Rauschtemperatur $T_\mathrm{e,ges}$ setzt sich ähnlich aus den äquivalenten Rauschzahlen $T_\mathrm{ex}$, wobei $x=1,2,3,\dots$, der einzelnen Zweitore, sowie deren Gewinn $G_\mathrm{x}$, zusammen.\cite{HEUERMANN_2018}
\begin{equation}
    T_\mathrm{e,ges}=T_\mathrm{e1}+\frac{T_\mathrm{e2}}{G_\mathrm{1}}+\frac{T_\mathrm{e3}}{G_\mathrm{1}\cdot G_\mathrm{2}}+\dots
    \label{eq:Gesamt-äquivalente-Rauschtemperatur-Kaskade}
\end{equation}
Die beiden Gleichungen \ref{eq:Gesamtrauschzahl-Kaskade} und \ref{eq:Gesamt-äquivalente-Rauschtemperatur-Kaskade} werden auch Friis'sche Gleichungen genannt.\cite{HEUERMANN_2018}
\subsubsection*{Antennentemperatur}
Bei der Antennentemperatur $T_\mathrm{A}$ handelt es sich um eine fiktive Temperatur und nicht um die physikalische Temperatur $T_\mathrm{0}$ der Antenne. Eine Antenne ist eine Rauschquelle, welche mit einer äquivalenten Rauschtemperatur $T_\mathrm{A}$ beschrieben werden kann. Diese äquivalente Rauschtemperatur $T_\mathrm{A}$ wird Antennentemperatur genannt.\cite{Balanis_2005}\cite{Satellite_Communications_Systems}\newline
Das Rauschen einer verlustlosen Antenne stammt von aufgenommen Emissionen von rauschenden Objekten im Umfeld der Antenne. Wie viel und aus welchem Einfallwinkel $(\theta,\varphi)$ die Emissionen von der Antennen aufgenommen wird, hängt von ihrer Strahlungscharakteristik ab.\cite{Balanis_2005}\cite{Satellite_Communications_Systems}\newline
Die Antennentemperatur kann durch die Integration der Emissionen aller rauschender Objekte im Umfeld Antenne bestimmt werden.\cite{Balanis_2005}\cite{Satellite_Communications_Systems}
\begin{equation}
    T_\mathrm{A}=\frac{1}{4\pi}\int^{2\pi}_0\int^{\pi}_0T_\mathrm{B}(\theta,\varphi)\cdot G(\theta,\varphi)\sin(\theta)\,d\theta\,d\varphi
    \label{eq:eigentliche-Antennentemperatur}
\end{equation}
Dabei $T_\mathrm{B}$ die sogenannte Helligkeitstemperatur (engl. Brightness Temperatur). Die Helligkeitstemperatur $T_\mathrm{B}$ gibt die Intensität der Strahlungsleistung eines Objektes in Form einer äquivalenten Rauschtemperatur an. Je stärker ein Objekt rauscht, desto größer ist auch die von diesem ausgehende Strahlungsleistung. Das führt zu einer Erhöhung der Helligkeitstemperatur $T_\mathrm{B}$. Die Helligkeitstemperatur $T_\mathrm{B}$ ist abhängig von der physikalischen Temperatur $T_\mathrm{M}$ des jeweiligen Objektes und einem Abstrahlkoeffizienten $\epsilon$.\cite{Balanis_2005}\cite{Satellite_Communications_Systems}
\begin{equation}
    T_\mathrm{B}(\varphi,\theta)= \varepsilon(\varphi,\theta)\cdot T_\mathrm{M}
    \label{eq:Brightness-Temperatur}
\end{equation}
Die Helligkeitstemperatur $T_\mathrm{B}$ ist $T_\mathrm{B}\leq T_\mathrm{M}$, da der Abstrahlkoeffizient nur Werte $0\leq\epsilon\leq1$ annimmt.\cite{Balanis_2005}\newline
Die Atmosphäre und das Wetter haben ebenfalls Einfluss auf die Antennentemperatur $T_\mathrm{A}$.\newline 
\begin{figure}[H]
    \centering
    \includesvg[width=0.75\linewidth]{Bilder/Antennentemperatur Grafik}
    \caption{Zusammensetzung der Antennentemperatur $T_\mathrm{A}$ und Einfluss durch Regen}
    \label{fig:Antennentemperatur}
\end{figure}

Bei optimalen Voraussetzung, bedeutet klarer Himmel, setzt sich die Antennentemperatur $T_\mathrm{A}$ aus der Helligkeitstemperatur des Himmels $T_\mathrm{Sky}$ und des Bodens um die Antenne $T_\mathrm{Ground}$ zusammen.\cite{Satellite_Communications_Systems}
\begin{equation}
    T_\mathrm{A}=T_\mathrm{Sky}+T_\mathrm{Ground}
    \label{eq:Antennentemperatur-klarer-Himmel}
\end{equation}
Die Helligkeitstemperatur des Himmels $T_\mathrm{Sky}$ kann über die Gleichung \ref{eq:eigentliche-Antennentemperatur} bestimmt werden, wobei $T_\mathrm{B}$ die Helligkeitstemperatur in des jeweiligen Einfallwinkels $(\theta,\varphi)$ der Antenne ist. In der Praxis ist jedoch nur der Bereich des Himmels innerhalb der $3\,\text{dB-Strahlbreite}$ $\theta_\mathrm{3dB}$ der Antenne für die Helligkeitstemperatur relevant, da sich in diesem Bereich der maximale Gewinn $G_\mathrm{max}$ der Antenne befindet. Daher kann die Helligkeitstemperatur des Himmels $T_\mathrm{Sky}$ in Abhängigkeit der Frequenz $f$ für mehrere Elevationswinkel $\epsilon$ der Antenne in einem Graphen dargestellt werden.\cite{Satellite_Communications_Systems}\newline
\begin{figure}[H]
    \centering
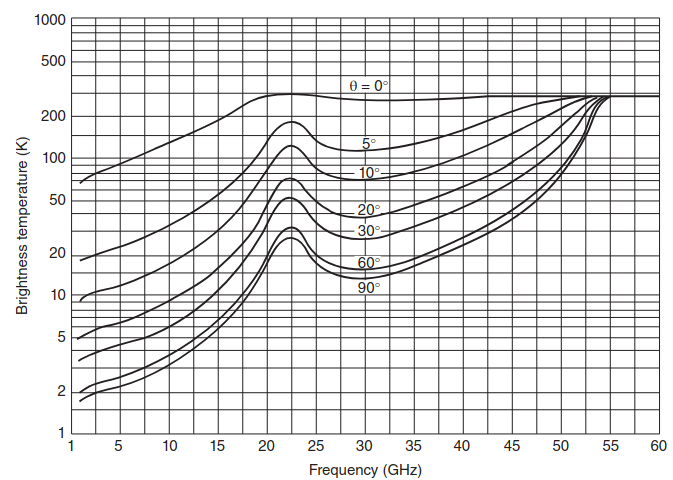
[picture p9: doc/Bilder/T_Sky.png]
    
    \caption{Darstellung der Helligkeitstemperatur des Himmels in Abhängigkeit der Frequenz $f$ für mehrere Elevationswinkel $\epsilon$.\cite{Satellite_Communications_Systems}}
    \label{fig:Temperatur-Himmel}
\end{figure}
Das vom Boden ausgehende Rauschen wird von den Nebenkeulen der Antenne eingefangen und teilweise auch von der Hauptkeule, wenn der Elevationswinkel $\epsilon$ klein genug ist. Die Helligkeitstemperatur des Bodens $T_\mathrm{Ground}$ setzt sich dabei aus dem aufgenommen Rauschen aller Nebenkeulen zusammen. Der Beitrag einer einzelnen Nebenkeule kann mit folgenden Gleichung bestimmt werden.\cite{Satellite_Communications_Systems}
\begin{equation}
    T_\mathrm{i}=G_\mathrm{i}\cdot T_\mathrm{G}\left(\frac{\Omega_i}{4\pi}\right)
    \label{eq:Temperatur-Boden-über-Nebenkeulen}
\end{equation}
Dabei ist $G_\mathrm{i}$ der durchschnittliche Gewinn der betrachten Nebenkeulen, $\Omega_\mathrm{i}$ der Raumwinkel, welchen die Nebenkeule abdeckt und $T_\mathrm{G}$ die eigentlich Helligkeitstemperatur des Bodens. Diese kann als folgend angenommen werden.\cite{Satellite_Communications_Systems}
\begin{equation}
    T_\mathrm{G}=
    \begin{cases}
    290\,\text{K}&,\epsilon\leq-10\degree\\
    150\,\text{K}&,-10\degree\leq\epsilon\leq0\degree\\
    50\,\text{K}&,0\degree\leq\epsilon\leq10\degree\\
    10\,\text{K}&,10\degree\leq\epsilon\leq90\degree\\
    \end{cases}
    \label{eq:Helligkeitstemperatur-Boden}
\end{equation}
Im Falle von Regen muss zusätzlich die durch Regen hervorgerufene Dämpfung $L_\mathrm{Regen}$, sowie die physikalische Temperatur $T_\mathrm{m}$ der Wolken in der Antennentemperatur berücksichtigt werden.\cite{Satellite_Communications_Systems}
\begin{equation}
    T_\mathrm{A}=\frac{T_\mathrm{Sky}}{L_\mathrm{Regen}}+T_\mathrm{m}\left(1-\frac{1}{L_\mathrm{Regen}}\right)+T_\mathrm{Ground}
    \label{eq:Antennentemperatur-bei-Regen}
\end{equation}
Dabei kann die Temperatur der Wolken mit $T_\mathrm{m}=275\,\text{K}$ angenommen werden.\cite{Satellite_Communications_Systems}

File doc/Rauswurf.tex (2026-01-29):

\subsubsection*{Kreuzpolarisationseffekte}
In der Satellitenkommunikation werden oft Frequenzen mehrfach verwendet. Die EM-Wellen der einzelnen Satelliten werden dann eine orthogonal Polarisation zueinander. So kann die Kapazität der möglichen Links erhöht werden.\cite{ITU-RP.618-14}\newline
Neben der Dämpfung $L_\mathrm{Regen}$ hat der Regen auch eine depolarisierende Wirkung auf die EM-Wellen. Wenn EM-Wellen durch Regengebieten laufen, kann sich ihre Polarisierungsebene verändern. Der Grund liegt in der unterschiedlichen Form der Regentropfen.\cite{Satellite_Communications_Systems}
\begin{figure}[H]
    \centering
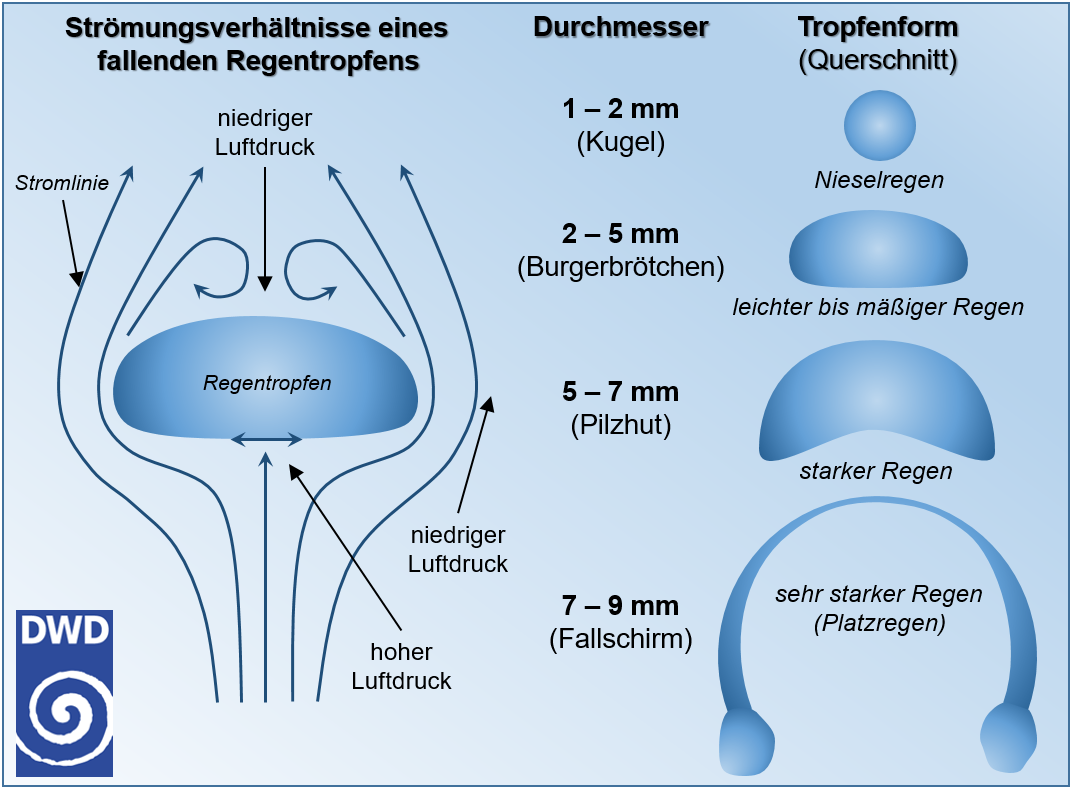
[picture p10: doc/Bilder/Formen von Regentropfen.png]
    
    \caption{Unterschiedliche Formen der Regentropfen, basierend auf ihrem\\ Durchmesser\cite{Regentropfen}}
    \label{FormenvonRegentropfen}
\end{figure}
Die Regentropfen nehmen je nach Größe unterschiedliche Formen an, wie es in Abbildung \ref{FormenvonRegentropfen} dargestellt ist. Während kleine Regentropfen mit einem Durchmesser von $1-2\,\text{mm}$ als Kugelförmig angenommen werden können, nehmen Regentropfen mit größerem Durchmesser stark nicht kugelförmige Formen an. Ein oft verwendetes Referenzmodel für Regentropfen ist ein abgeflachter Rotationskörper.\cite{Satellite_Communications_Systems}\newline
Aufgrund ihrer Form wirken Regentropfen wie anisotrope Streuer, was zwei Effekte mit sich bringt.\cite{Satellite_Communications_Systems}
\begin{itemize}
    \item Differentielle Dämpfung: Die horizontale und vertikale Polarisationskomponente erfahren unterschiedliche Dämpfungen.\cite{Satellite_Communications_Systems}
    \item Differentielle Phasenverschiebung: Die Phase der horizontalen und vertikalen Polarisationskomponente werden unterschiedlich stark verschoben.\cite{Satellite_Communications_Systems}
\end{itemize}
Beide Effekte führen zusammen zu einer Rotation in der Polarisationsebene und erzeugen damit eine Kreuzpolarisation.\cite{Satellite_Communications_Systems}\newline
Bei einer Kreuzpolarisation wird Energie zwischen zwei orthogonal zueinander polarisierten EM-Wellen ausgetauscht. Die Kreuzpolarisation verringert also die Isolation zwischen zwei orthogonal zueinander EM-Wellen.\cite{Satellite_Communications_Systems}
Auch Eis in den Wolken nah der $0\degree\text{C}$ isothermische Grenze verursacht ebenfalls eine Kreuzpolarisation.\cite{Satellite_Communications_Systems}\newline
Die Verringerung der Isolation durch die Kreuzpolarisation wird mit $XPD(p)\,[\text{dB}]$ ausgedrückt. Dabei wird die Isolation $XPD(p)\,[\text{dB}]$ nicht für $p\,\%$ der gegebenden Zeit, z.B. eines Jahres, überschritten.\cite{Satellite_Communications_Systems}\cite{ITU-RP.618-14}
\begin{equation}
    \label{EqIsolationKreuz}
    XPD(p)=XPD_\mathrm{Regen}-C_\mathrm{Eis}
\end{equation}
Dabei ist $XPD_\mathrm{Regen},\left[\text{dB}\right]$ der Kreuzpolarisationsanteil durch Regen und $C_\mathrm{Eis},\left[\text{dB}\right]$ der durch Eis in den Wolken\cite{Satellite_Communications_Systems}.\newline
Die folgende Bestimmung von $XPD(p)$ gilt für gleichen Pfad der Dämpfung durch Regen und kann für Frequenzen $6\,\text{GHz}\leq f \leq55\,\text{GHz}$ und einem Elevationswinkel der Antenne $\epsilon\leq60\degree$. $XPD_\mathrm{Regen}$ ist von mehreren Termen abhängig. \cite{ITU-RP.618-14}\newline
\begin{equation}
    \label{EqXPDRegen}
    XPD_\mathrm{Regen}=C_\mathrm{f}-C_\mathrm{A}+C_\mathrm{\tau}+C_\mathrm{\theta}+C_\mathrm{\sigma}
\end{equation}
Der Term $C_\mathrm{f}$ ist von der Frequenz $f,\left[\text{GHz}\right]$ abhängig.\cite{ITU-RP.618-14}
\begin{equation}
    C_\mathrm{f}=
    \begin{cases}
        60\cdot \log(f)-28.3 &,6\,\text{GHz}\leq f \leq9\,\text{GHz}\\
        26\cdot \log(f)+4.1 &,9\,\text{GHz}\leq f \leq36\,\text{GHz}\\
        35.9\cdot \log(f)-11.3 &,36\,\text{GHz}\leq f \leq55\,\text{GHz}\\
    \end{cases}
\end{equation}
Der von der Dämpfung durch Regen $L_\mathrm{Regen}$ abhängige Term $C_\mathrm{A}$ wird wie folgt bestimmt.\cite{ITU-RP.618-14}
\begin{equation}
    C_\mathrm{A}=V(f)\cdot\log_{10}(L_\mathrm{Regen\,p})
\end{equation}
Wobei $V(f)$ von der Frequenz $f\,\left[\text{GHz}\right]$ abhängig ist.\cite{ITU-RP.618-14}
\begin{equation}
    V(f)=
    \begin{cases}
        30.8\cdot f^{-0.21}&,6\,\text{GHz}\leq f\leq9\,\text{GHz}\\
        12.8\cdot f^{0.19}&,9\,\text{GHz}\leq f\leq20\,\text{GHz}\\
        22.6&,20\,\text{GHz}\leq f\leq40\,\text{GHz}\\
        13\cdot f^{0.15}&,40\,\text{GHz}\leq f\leq55\,\text{GHz}\\
    \end{cases}
\end{equation}
Der Term $C_\mathrm{\tau}$ gibt die Verschlechterung der Polarisation an.\cite{ITU-RP.618-14}
\begin{equation}
    C_\mathrm{\tau}=-10\cdot\log_{10}[1-0.484(1+\cos(4\tau)]\\
\end{equation}
Dabei ist $\tau$ der Winkel zwischen der EM-Welle und dem Boden. Dieser Winkel entspricht auch dem Neigung (engl. Skew) der Antenne. Dieser wird später in Kapitel \ref{Ausrichten der Antenne} bestimmt.\newline
Der Term $C_\mathrm{\theta}$ ist vom Elevationswinkel $\epsilon$ der Antenne abhängig. Auch dieser wird später in Kapitel \ref{Ausrichten der Antenne} bestimmt.\cite{ITU-RP.618-14}
\begin{equation}
    C_\mathrm{\theta}=-40\cdot\log_{10}(\cos{\epsilon})
\end{equation}
Der letzte Term $C_\mathrm{\sigma}$ gibt die Standardvariation der Verteilung des Einfallswinkels der Regentropfen auf die EM-Wellen an.\cite{Satellite_Communications_Systems}\cite{ITU-RP.618-14}
\begin{equation}
    C_\mathrm{\sigma}=0.0052\sigma^2
\end{equation}
Dabei nimmt $\sigma$ Werte von $\sigma=0\degree,5\degree,10\degree,15\degree$ für $p=1\,\%,0.1\,\%,0.01\,\%,0.001\%$ an.\cite{ITU-RP.618-14}\cite{Satellite_Communications_Systems}\newline
$C_\mathrm{Eis}\,\left[\text{dB}\right]$ der Anteil des Eises in den Wolken.\cite{Satellite_Communications_Systems}
\begin{equation}
    \label{EqCeis}
    C_\mathrm{Eis}=\frac{XPD_\mathrm{Regen}(0.3+0.1\cdot\log_{10}(p))}{2}
\end{equation}
Mit den Gleichungen \ref{EqIsolationKreuz} bis \ref{EqCeis} kann mithilfe von Python die Verschlechterung der Isolation zwischen zwei orthogonal zueinander Polarisierten Wellen bestimmt werden. Für $XPD_\mathrm{Regen},\,\left[\text{dB}\right]$ in Gleichung \ref{EqXPDRegen} ergibt sich für eine Frequenz von $f\approx10.5\,\text{GHz}$, mit der Dämpfung durch starke Regenschauer $L_\mathrm{Regen,0.01}=8.792\,\text{dB}$, einer Neigung der EM-Welle von $\tau=-12.412\degree$, einer Elevation $\epsilon=27.888\degree$ für $p=0.01\,\%$ 
\begin{equation*}
        XPD_\mathrm{Regen}=C_\mathrm{f}-C_\mathrm{A}+C_\mathrm{\tau}+C_\mathrm{\theta}+C_\mathrm{\sigma}=
\end{equation*}
Damit ergibt sich der Beitrag durch Eis in Wolken zu
\begin{equation}
    C_\mathrm{Eis}=\frac{XPD_\mathrm{Regen}(0.3+0.1\cdot\log_{10}(p))}{2}=
\end{equation}
Was zu einer Verschlechterung der Isolation zwischen den orthogonal zueinander polarisierten EM-Wellen
\begin{equation*}
    XPD(0.01\,\%)=XPD_\mathrm{Regen}-C_\mathrm{Eis}=
\end{equation*}
führt. Für leichte Regenschauer $p=5\,\%$ ergibt sich eine Verschlechterung von 
\begin{equation}
    XPD(5\,\%)=XPD_\mathrm{Regen}-C_\mathrm{Eis}=
\end{equation}
Die Verschlechterung der Isolation zwischen den orthogonal zueinander polarisierten EM-Wellen kann gegebenfalls zu einer Verschlechterung des SNR führen.->Maybe

Das $SNR_\mathrm{o,klarerHimmel}=6.67\,\text{dB}$ ist sehr gering. Grund dafür ist die hohe äquivalente Rauschtemperatur $T_\mathrm{e,sys}$ des Systems. Das erste Zweitor im Empfangssystem ist eine Koaxialleitung. Da eine Koaxialleitung ein passives Zweitor ist, bringt sie eine Gewisse Dämpfung mit sich. Dadurch fließt die äquivalente Rauschtemperatur vom zweiten Zweitor, des LNC, mit einer kleinen Verstärkung in die gesamte äquivalente Rauschtemperatur $T_\mathrm{e,sys}$ des RF-Bereiches ein. Diese Gegebenheit ist der Grund für hohe Rauschen und damit das niedrige $SNR_\mathrm{o}$ des Empfangssystem. Signale mit digitaler Modulation würden eine hohe Bitfehlerrate aufweisen.\newline
Um die Rauschleistung $N_\mathrm{o,klarerHimmel}$ zu verringern könnte z.B. das erste Zweitor der RF-Bereiches durch eine rauscharmen Verstärker (LNA) gebildet werden, welcher dann mit der Koaxialleitung mit dem LNC verbunden wird. Dadurch könnte die äquivalente Rauschtemperatur des RF-Bereiches $T_\mathrm{e,sys}$ deutlich reduziert werden. 
\begin{equation}
    T_\mathrm{e,sys-mit-LNA}=T_\mathrm{eLNA}+\frac{T_\mathrm{e1}}{G_\mathrm{LNA}}+\frac{T_\mathrm{eLNC}}{G_\mathrm{LNA}\cdot G_\mathrm{1}}+\dots=108.998\,\text{K}
    \label{eq:Te-mit-LNA}
\end{equation}
Das Ergebnis in Gleichung \ref{eq:Te-mit-LNA} ist durch die Erweiterung der Gleichung \ref{eq:äquivalente-Rauschtemperatur-Empfangsystem} um einen theoretischen LNA mit $G_\mathrm{LNA}=30\,\text{dB}$ und $T_\mathrm{eLNA}=100\,\text{K}$ als erstes Zweitor entstanden.\newline
Durch das einfügen des LNA kann die äquivalente des Empfangssystems theoretisch auf $T_\mathrm{e,sys-mit-LNA}=108.998\,\text{K}$ reduziert werden.
\begin{equation}
\begin{split}
    SNR_\mathrm{o,verbessert}&=\frac{P_\mathrm{R}}{k\cdot (T_\mathrm{A,klarerHimmel}+T_\mathrm{e,sys-mit-LNA})\cdot B}\\&=\frac{5.93\cdot 10^{-17}\,\text{W}}{1.38\cdot10^{-23}\,\frac{\text{J}}{\text{K}}\cdot(6.5\,\text{K}+108.998\,\text{K})\cdot2.7\,\text{kHz}}=13.77=11.39\,\text{dB}
\end{split}
    \label{eq:SNRo-klarer-Himmel}
\end{equation}
Durch die verbesserte äquivalente Rauschtemperatur $T_\mathrm{e,sys-mit-LNA}$ könnte das $SNR_\mathrm{o}$ auf $SNR_\mathrm{o,verbessert}=11.39\,\text{dB}$ verbessert werden. Dieses $SNR$ wäre deutlich besser für die Demodulation und würde die Bitfehlerrate deutlich verringern.\newline

Die Qualität des Downlinks bei klaren Himmel kann mit der Gleichung \ref{eq:Qualität-Downlink} bestimmt werden. Zuvor muss noch die Rauschtemperatur $T_\mathrm{S}$ mit Gleichung \ref{eq:Rauschen-Temperatur-System} bestimmt werden. Die Verluste des Empfangssystems betragen $L_\mathrm{sys}=7.01\,\text{dB}=5.02$. Die Antennentemperatur beträgt $T_\mathrm{A,klarerHimmel}=6.5\,\text{K}$, die physikalische Temperatur $T_\mathrm{0}=290\,\text{K}$ und die äquivalente Rauschtemperatur $T_\mathrm{e,sys}=336.63\,\text{K}$. 
\begin{equation}
\begin{split}
     T_\mathrm{S}&=\frac{T_\mathrm{A,klarerHimmel}}{L_\mathrm{sys}}+T_\mathrm{0}\left(1-\frac{1}{L_\mathrm{sys}}\right)+T_\mathrm{e,sys}\\
     &=\frac{6.5\,\text{K}}{5.02}+290\,\text{K}\left(1-\frac{1}{5.02}\right)+336.63\,\text{K}\\
     &=570.07\,\text{K}
\end{split}
\label{eq:Rauschen-Temperatur-System-klarer-Himmel}
\end{equation}
Zusammen mit der Leistung am Ausgang des RF-Bereiches $P_\mathrm{RX}$ aus Gleichung \ref{eq:Ausgang-Leistung-klarer-Himmel} kann die Qualität des Downlinks bei einem klaren Himmel bestimmt werden.
\begin{equation}
C/N_\mathrm{o}=\frac{P_\mathrm{RX}}{k\cdot T_\mathrm{S}}=\frac{3.74\cdot 10^{-9}\,\text{W}}{1.38\cdot10^{-23}\,\frac{\text{J}}{\text{K}}\cdot570.07\,\text{K}}=4.75\cdot10{11}\,\text{Hz}=117.3\,
\text{dBHz}
 \label{eq:Qualität-Downlink-klarer-Himmel}
\end{equation}
Wie bereits erwähnt könnte durch das Einbringen eines LNA in das Empfangssystem die Qualität des Downlinks verbessert werden. Mit der in Gleichung \ref{eq:Te-mit-LNA} bestimmten äquivalenten Rauschtemperatur $T_\mathrm{e,sys-mit-LNA}$ könnte die Rauschtemperatur $T_\mathrm{S}$ verringert werden.
\begin{equation}
\begin{split}
     T_\mathrm{S,verbessert}&=\frac{T_\mathrm{A,klarerHimmel}}{L_\mathrm{sys}}+T_\mathrm{0}\left(1-\frac{1}{L_\mathrm{sys}}\right)+T_\mathrm{e,sys-mit-LNA}\\
     &=\frac{6.5\,\text{K}}{5.02}+290\,\text{K}\left(1-\frac{1}{5.02}\right)+108.998\,\text{K}\\
     &=342,52\,\text{K}
\end{split}
\label{eq:Rauschen-Temperatur-System-klarer-Himmel-verbessert}
\end{equation}
Die theoretische Rauschtemperatur $T_\mathrm{S,verbessert}=342,52\,\text{K}$ ist $227.55\,\text{K}$ niedriger als die eigentliche Rauschtemperatur $T_\mathrm{S}=570.07\,\text{K}$. Das würde sich positiv auf die Qualität des Downlinks auswirken.
\begin{equation}
C/N_\mathrm{o}=\frac{P_\mathrm{RX}}{k\cdot T_\mathrm{S,verbessert}}=\frac{5.93\cdot10^{-17}\,\text{W}}{1.38\cdot10^{-23}\,\frac{\text{J}}{\text{K}}\cdot342,52\,\text{K}}=7537.85\,\text{Hz}=38.77\,
\text{dBHz}
 \label{eq:Qualität-Downlink-klarer-Himmel}
\end{equation}

\newline
Die Leistung am Ausgang des Empfangssystems $P_\mathrm{RX}$ in Goonhilly kann mithilfe einer Leistungsanzeige über die Weboberfläche ermittelt werden.\cite{OnlineMonitor}\newline
Bei zwei Einseitenbandübertagungen werden in einem Abstand von $10\,\text{s}$ 10 Messwerte aufgenommen. Bei den Messwerten handelt es sich um die momentane Spitzenleistung, welche von dem Leistungsmesser angezeigt wird. Die Bandbreite wird dabei auf die maximale zulässige Bandbreite bei Einseitenbandübertragungen von $B=2.7\,\text{kHz}$ eingestellt. Mit dem gleichen Prinzip wird das Rauschen am Ausgang des Empfangssystems gemessen. Dafür wird eine freie Frequenz im Downlink ausgewählt. Die Bandbreite beträgt hier ebenfalls $B=2.7\,\text{kHz}$. Anschließend wird für die jeweilige Messreihe der Durchschnitt in dB und in dBm ermittelt.

\begin{table}[H]
    \centering
    \begin{tabular}{c|c|c|c}
      Wert  & Übertragung 1 (dB) & Übertragung 2 (dB) & Rauschen (dB) \\
        \hline
      1  & $-67.1$ & $-70.9$ & $-85.4$ \\
      2  & $-72.4$ & $-71.1$ & $-85.6$ \\
      3  & $-73.1$ & $-69.9$ & $-84.9$ \\
      4  & $-71.6$ & $-69.2$ & $-86$ \\
      5  & $-74.3$ & $-70.6$ & $-85.1$ \\
      6  & $-65.3$ & $-72$ & $-85.3$ \\
      7  & $-75$ & $-69.2$ & $-85.6$ \\
      8 & $-68.1$ & $-71.4$ & $-85.5$ \\
      9  & $-67.9$ & $-72.8$ & $-85.4$ \\
      10  & $-69$ & $-73.4$ & $-86.4$ \\
      \hline
      Durchschnitt (dB) & $-70.38$ &$-71.05$ & $-85.52$\\ 
      Durchschnitt (dBm) & $-40.38$& $-41.05$ & $-55.52$ \\ 
    \end{tabular}
    \caption{Aufgenommene Messwerte des Empfangssystems an der Goonhilly Bodenstation}
    \label{tab:Messwerte-Goonhilly}
\end{table}
Die Tabelle \ref{tab:Messwerte-Goonhilly} zeigt die aufgenommenen Messwerte, sowie die Durchschnittswerte. Die durchschnittliche Leistung am Ausgang des Empfangssystems beträgt bei den Einseitenbandübertagungen $P_\mathrm{RX}=-40.38\,\text{dBm}$, bzw. $P_\mathrm{RX}=-41.05\,\text{dBm}$. Die Korrektheit der Messwerte kann mit dem Gewinn des Empfangssystems $G_\mathrm{LNB,max}=65\,\text{dB}$ und der Eingangsleistung $P_\mathrm{R}=-107.77\,\text{dBm}$ ermittelt werden.
\begin{equation}
    P_\mathrm{RX}=P_\mathrm{R}+ G_\mathrm{LNB,max}=-107.77\,\text{dBm}+65\,\text{dB}=-42.77\,\text{dBm}
    \label{eq:theoretische-Ausgangsleistung-Goonhilly}
\end{equation}
Die theoretische ermittelt Leistung am Ausgang des Empfangssystems $P_\mathrm{RX}=-42.77\,\text{dBm}$ deckt sich ungefähr mit der gemessene Leistung am Ausgang des Empfangssystems $P_\mathrm{RX}=-40.38\,\text{dBm}$, bzw. $P_\mathrm{RX}=-41.05\,\text{dBm}$. Aus diesem Grund können die gemessenen Werte als korrekt angenommen werden. Für weitere Rechnungen und Vergleichen wird der Mittelwert $P_\mathrm{RX}=-40.72\,\text{dBm}$ verwendet.\newline
Verglichen mit der theoretischen Ausgangsleistung bei einem klaren Himmel des Empfangssystems am IAT $P_\mathrm{RX}=-31.18\,\text{dBm}$ ist die Ausgangsleistung am des Empfangssystems in Goonhilly $P_\mathrm{RX}=-40.72\,\text{dBm}$ um $9.54\,\text{dB}$. Erklärt werden kann das mit der niedrigeren Verstärkung des Empfangssystems in Goonhilly $G_\mathrm{LNB,max}=65\,\text{dB}$, verglichen mit der Verstärkung $G_\mathrm{sys}=79.49\,\text{dB}$ des Empfangssystems am IAT. Auffällig dabei ist, dass die beiden Ausgangsleistungen nicht um die Differenz der beiden Verstärkungen von $14.49\,\text{dB}$ auseinander liegen. Mögliche Gründe können dabei ein höherer Antennengewinn $G_\mathrm{R,Goonhilly}$ der an der Goonhilly Bodenstation verwendeten Antenne oder eine weitere Verstärkende Komponente im Empfangssystem, welche nicht auf der Webseite angeben wird.
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

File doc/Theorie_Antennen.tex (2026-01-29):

\subsection{Antennenparameter}
Die Antenne ist mit der wichtigste Bestandsteil der Empfangskette an der Satellitenbodenstation. Erst mit einer geeigneten Antenne ist es mögliche die Signale vom Satelliten, welcher ebenfalls eine Antenne braucht um die Signale zu senden, zu empfangen. Die Antenne wandelt die leitungsgebundene Welle um und strahlt diese in den freien Raum ab oder empfängt die Wellen im freien Raum und gibt diese an die Leitung ab. Sie ist also das Verbindungsglied zwischen der leitungsgebundenen elektrischen Signal und der Welle im freien Raum.\cite{Balanis_2005}\newline
Die IEEE definiert eine Antenne als ein passives, lineares und reziprokes Bauelement, welches Radiowellen abstrahlen, als auch empfangen kann.\cite{IEEE145-1993}\cite{Balanis_2005}\newline
Eine Antenne kann über viele verschiedene Parameter beschrieben werden. Diese Parameter helfen dabei eine geeignete Antenne für die jeweilige Anwendung zu finden.
\subsubsection*{Strahlungsleistungsdichte}
Mit der Strahlungsleistungsdichte $S$ kann die, auf eine Oberfläche mit der Fläche $A$ im Fernfeld der Antenne, einwirkende Leistungsdichte beschrieben werden. Ihre Einheit ist 
$\text{W}/\text{m}^2$.\newline
Betrachtet wird dabei Leistungsdichte der elektromagnetischen Wellen welche sich im jeweiligen Raumwinkel $\frac{A}{r^2}$ befinden.\cite{Satellite_Communications_Systems}
Bei einem isotropen Kugelstrahler werden die elektromagnetischen Wellen mit der Sendeleistung $P_\mathrm{T}$ gleichmäßig in alle Richtungen $(\theta,\varphi)$ abgestrahlt. Daher ergibt sich kein spezifischer Raumwinkel für den isotropen Kugelstrahler, weshalb die Strahlungsdichte $S_\mathrm{0}$ des isotropen Kugelstrahler über die sich ausbreitende Kugeloberfläche betrachtet wird.\cite{Satellite_Communications_Systems}\newline
\begin{equation}
    S_0=\frac{P_\mathrm{TX}}{4\cdot \pi \cdot r^2 }
    \label{eq:isotroperkugelstrahler-strahlungsleistungsdichte}
\end{equation}
Bei einer realen Antenne gibt es eine bevorzugte Abstrahlrichtung $(\theta,\varphi)$, in welche die Antenne mit einem bestimmten Gewinn $G(\theta,\varphi)$ die elektromagnetischen Wellen mit der Sendeleistung $P_\mathrm{T}$ abstrahlt.\cite{Satellite_Communications_Systems}
\begin{equation}
    S(\theta,\varphi)=\frac{P_\mathrm{T}\cdot G(\theta,\varphi)}{4\cdot \pi \cdot r^2 }
    \label{eq:reale-strahlungsleistungsdichte}
\end{equation}
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

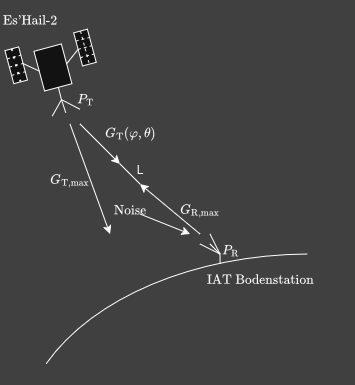
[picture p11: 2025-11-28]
doc/Bilder/Skizze Downlink.png

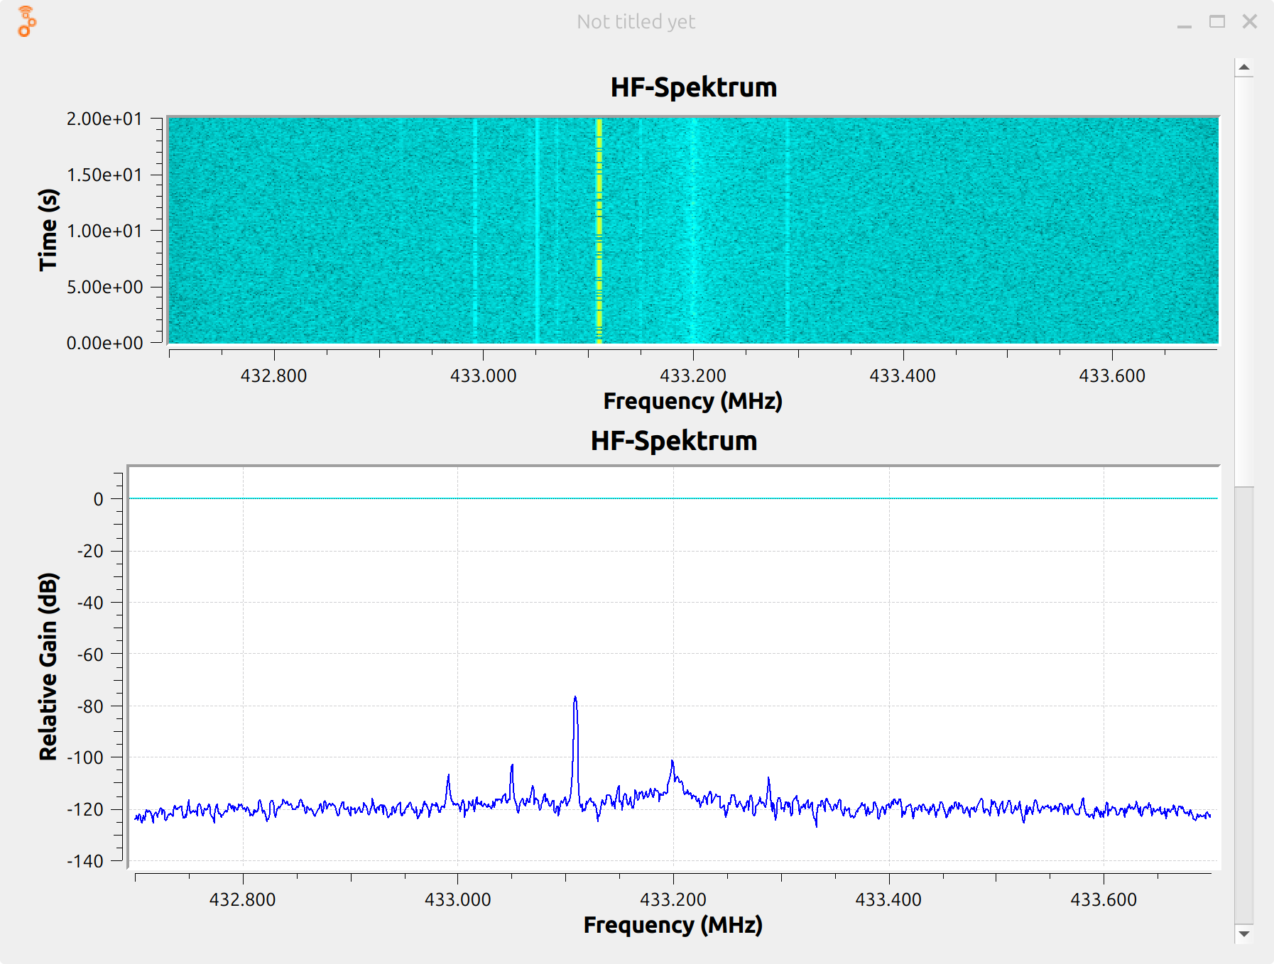
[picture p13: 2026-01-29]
doc/Bilder/HF-Spektrum USB.png

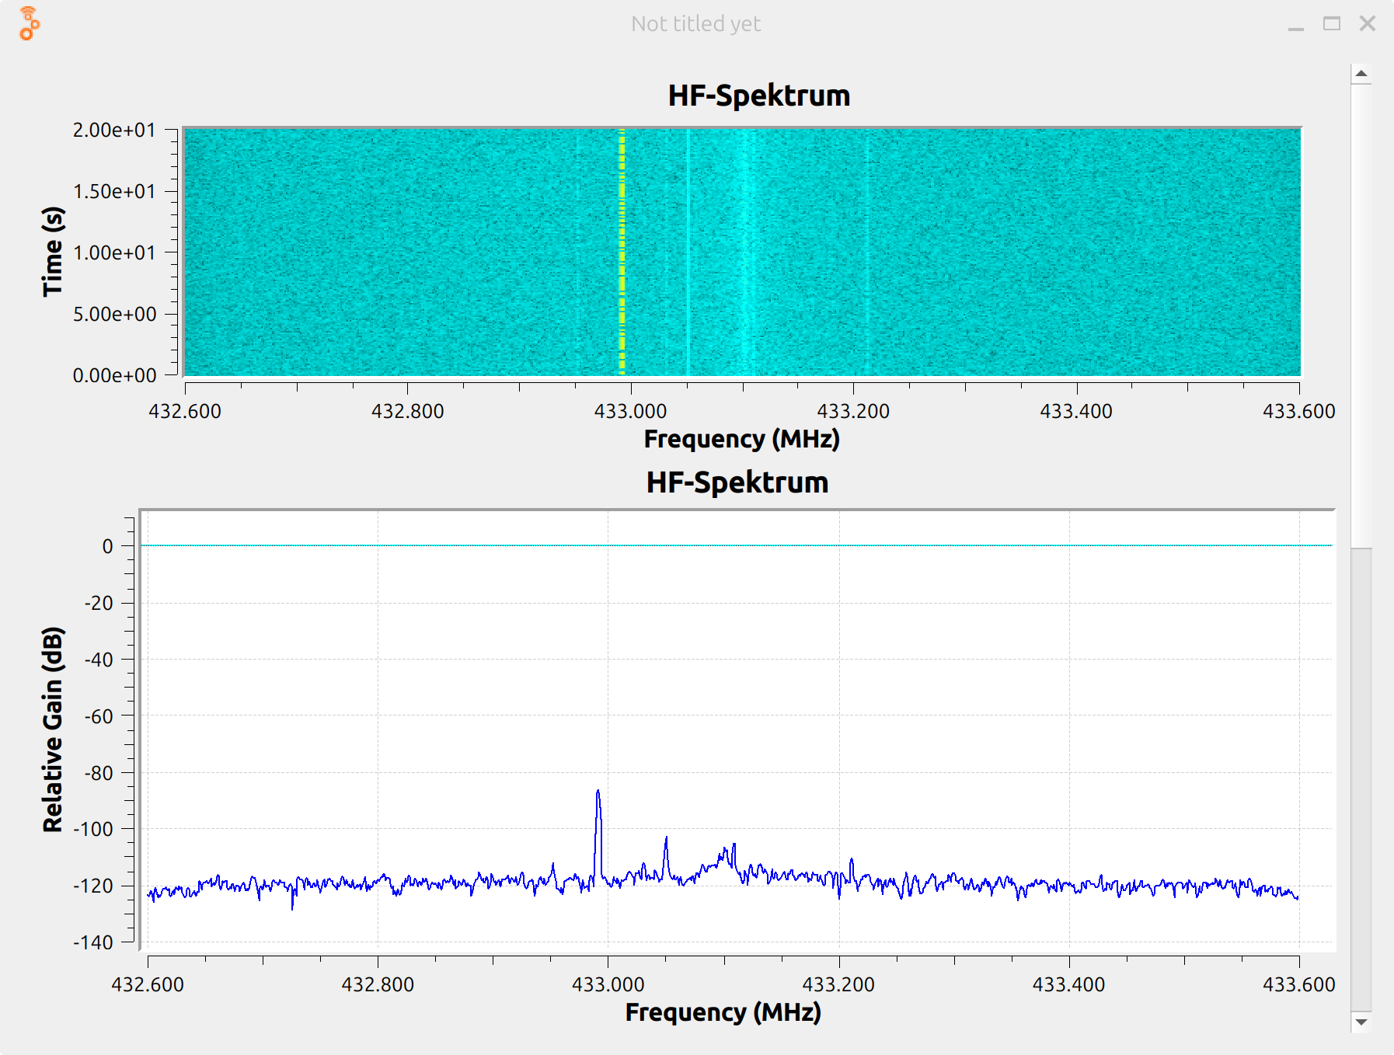
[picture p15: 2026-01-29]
doc/Bilder/CW HF Spektrum.png

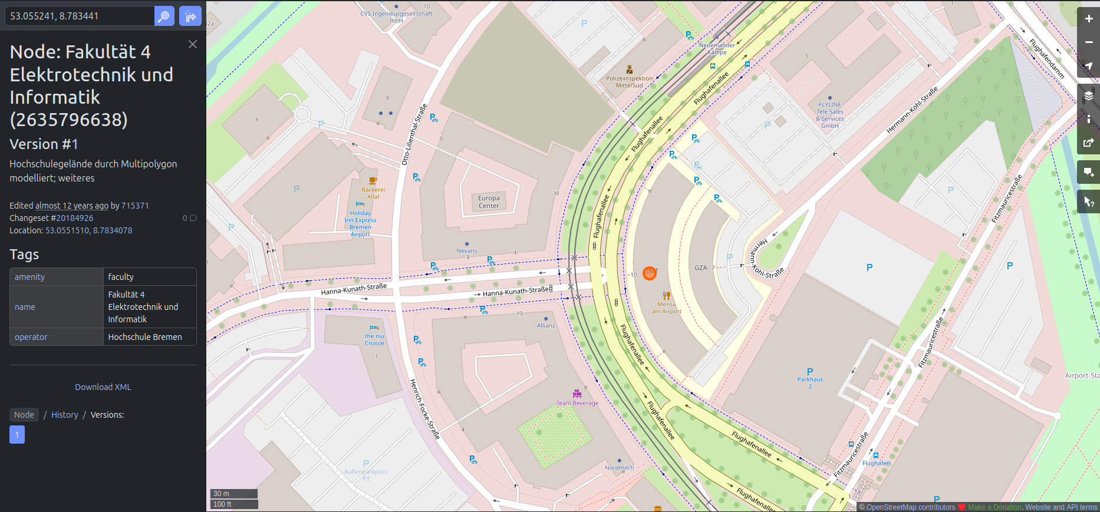
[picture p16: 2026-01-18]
doc/Bilder/Position Bodenstation.png

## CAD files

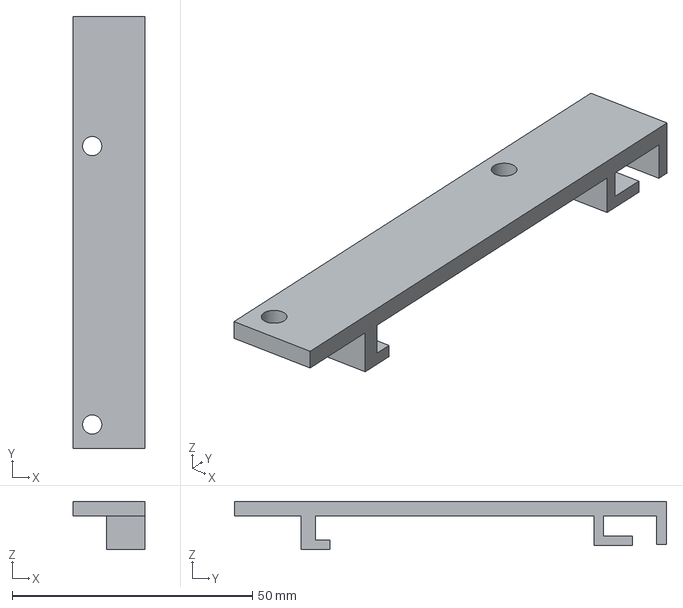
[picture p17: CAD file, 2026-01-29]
3D-Druck/Holder Downconverter-Body.step
15.0 x 90.0 x 10.0 mm

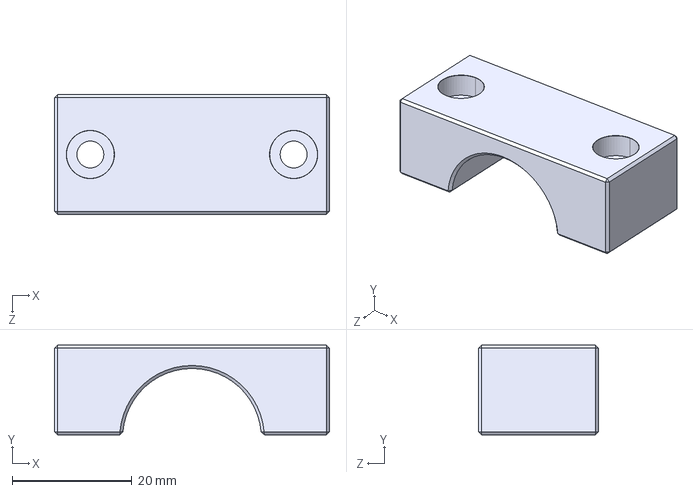
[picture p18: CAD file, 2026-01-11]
3D-Druck/Feed-Halter_Top.STEP
46.0 x 15.0 x 20.0 mm

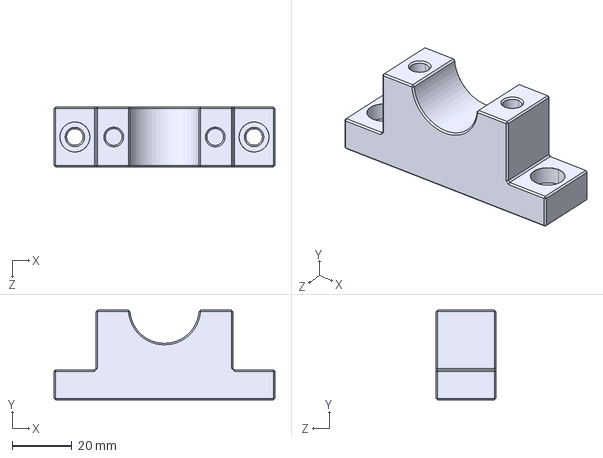
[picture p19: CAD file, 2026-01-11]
3D-Druck/Feed-Halter_Base.STEP
74.0 x 30.0 x 20.0 mm

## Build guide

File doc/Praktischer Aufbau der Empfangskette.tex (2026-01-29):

\subsection{Aufstellen und Ausrichten der Antenne}\label{Ausrichten der Antenne}
Die Antenne soll auf einem eigenen Antennenstandfuß auf dem Dach der Hochschule montiert werden. Der neue Antennenfeed wird mithilfe des alten Feedhalters im Fokuspunkt der Parabolschüssel montiert. Für die Anbringung des neuen Antennenfeeds wird ein Adapter entwickelt, welcher mithilfe eines 3D-Druckers angefertigt wird. Als Material wird PETG-HF von Bambu Lab verwendet. Die Druckdatei ist im GitHub-Repository hinterlegt.\newline
\begin{figure}[H]
    \centering
    \includesvg[width=0.5\linewidth]{Bilder/Aufbau Antennenmast}
    \caption{Skizze vom Aufbau der Antenne auf dem Dach der Hochschule}
    \label{fig:Aufbau-der-Antenne}
\end{figure}
Die Abbildung \ref{fig:Aufbau-der-Antenne} zeigt den geplanten Aufbau der Antenne auf dem Dach der Hochschule. Dieser ist zum größtenteils auch umgesetzt. Der vorgesehene Antennenmast und Antennenfuß ist nicht bis zum Abschluss der Arbeit angekommen, weshalb ein provisorischer Antennenmast gebaut wird.
\begin{figure}[H]
    \centering
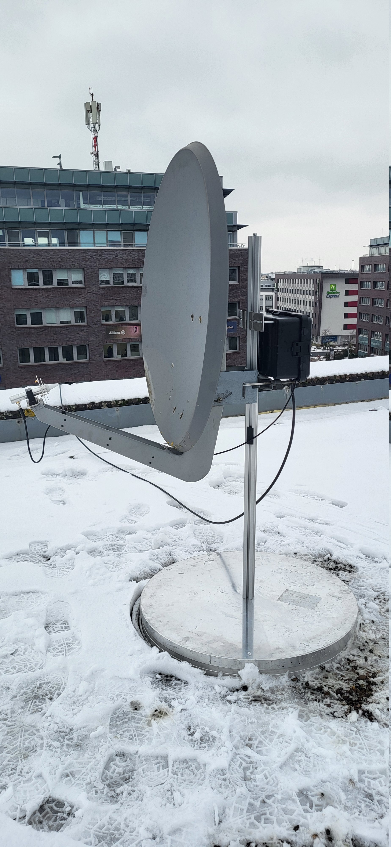
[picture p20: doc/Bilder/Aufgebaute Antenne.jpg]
    
    \caption{Umgesetzter Aufbau der Antenne auf dem Dach der Hochschule. Im Schwarzen Gehäuse am Mast ist der LNC untergebracht.}
    \label{fig:Umgesetzter-Aufbau-Antenne}
\end{figure}
Für die Ausrichtung der Antenne auf Es'Hail-2 (QO-100) muss der Azimut $\varphi$ und die Elevation $\varepsilon$ bestimmt werden. Mit Gleichung \ref{eq:Azimut} kann der Azimut $\varphi$ bestimmt werden. Die Koordinaten der Bodenstation $53.055\degree,8.78\degree$ können aus der Abbildung \ref{fig:Koordinaten der Bodenstation} entnommen werden. Der Satellit Es'Hail-2 (QO-100) befindet sich bei  $25.9\degree \text{E}$\cite{EsHail2}. Damit beträgt die Differenzen zwischen den Längengraden $\Delta long=53.055\degree-25.8\degree=27.255\degree$.
\begin{equation}
    \varphi=\arctan\left(\frac{\tan(\Delta long)}{\sin(lat_\mathrm{BS})} \right)=\arctan\left(\frac{\tan(27.255\degree)}{\sin(8.78\degree)} \right)=159.04\degree
    \label{eq:Azimut-Antenne}
\end{equation}
Für die Ermittlung der Elevation $\varepsilon$ der Antenne wird die Gleichung \ref{eq:Elevation} verwendet. Der Radius der Erde beträgt $r_\mathrm{0}=6378\,\text{km}$ und die Flughöhe von Es'Hail-2 (QO-100) kann mit $r=35790\,\text{km}$ angenommen werden.\cite{Satellitenkommunikation}
\begin{equation}
\begin{split}
    \varepsilon&=\arctan\left(\frac{\cos(lat_\mathrm{BS})\cdot\cos(\Delta long)-\frac{r_\mathrm{0}}{r_\mathrm{0}+r}}{\sqrt{1-\cos^2(lat_\mathrm{BS})\cdot\cos^2(\Delta long)}} \right)\\
    &=\arctan\left(\frac{\cos(8.78\degree)\cdot\cos(27.255\degree)-\frac{6378\,\text{km}}{6378\,\text{km}+35790\,\text{km}}}{\sqrt{1-\cos^2(8.78\degree)\cdot\cos^2(27.255\degree)}} \right)\\
    &=27.36\degree
\end{split}
    \label{eq:Elevation-Antenne}
\end{equation}
Zum Schluss muss noch die Drehung des Antennenfeeds um seine eigene Achse, der $Skew$, ermittelt werden. Dieser kann mit der Gleichung \ref{eq:Skew} bestimmt werden. Der Offset des Antennenfeeds beträgt $0\degree$.
\begin{equation}
    Skew = \arctan\left(\frac{\sin(\Delta long)}{\tan (lat_\mathrm{BS})}\right)-Offset=\arctan\left(\frac{\sin(27.255\degree)}{\tan (8.78\degree)}\right)=-12.4\degree
\end{equation}
Das Python-Skript zur Berechnung der Azimut $\varphi$, Elevation $\varepsilon$ und Drehung $Skew$ der Antenne ist im GitHub-Repository und im Anhang \ref{lst:Antenne-berechnung-python} hinterlegt. Mithilfe eines Kompass wird der Azimut $\varphi=159.04\degree$ der Antenne eingestellt. Die Elevation $\varepsilon=27.36\degree$ kann mithilfe einer Skala an der Antenne eingestellt werden. Die Neigung des Antennenfeeds um die eigene Achse $Skew=-12.4\degree$ wird mithilfe einer Winkellehre eingestellt. Als Ursprungpunkt wird dabei der SMA-Anschluss des X-Band Feeds gewählt.

\subsection{Abwärtsmischer, Fernspeiseweiche und Verkabelung im Serverschrank}
Der rauscharme Abwärtsmischer (LNC) wird neben der Antenne montiert. Um diesen vor Wettereinflüssen, wie Regen und Schnee, zu schützen, wird dieser in einem wasserdichten Gehäuse untergebracht (schwarzer Kasten in Abbildung \ref{fig:Umgesetzter-Aufbau-Antenne}).
\begin{figure}[H]
    \centering
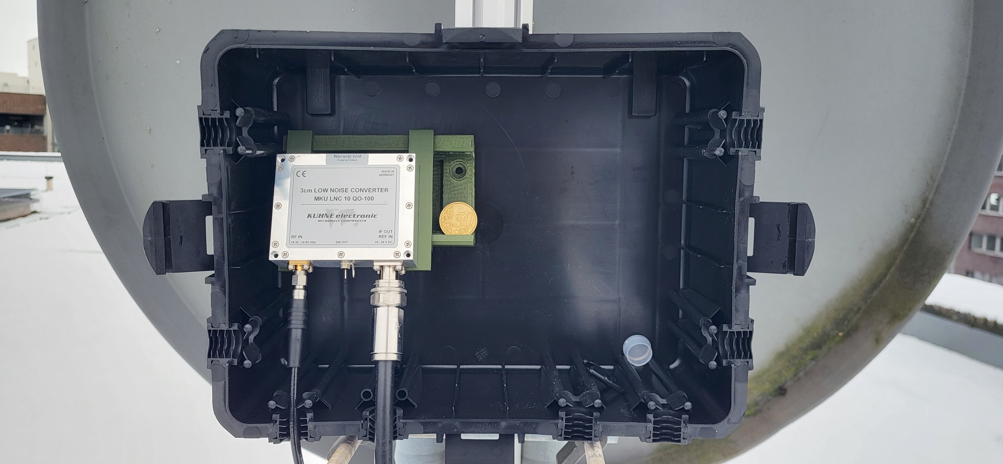
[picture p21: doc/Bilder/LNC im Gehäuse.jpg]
    
    \caption{Unterbringung des LNC im Gehäuse. Dank der Schiene kann dieser leicht ein- und ausgebaut werden. Die 50-Cent Münze dient als Größenvergleich.}
    \label{fig:LNC-im-Gehäuse}
\end{figure}
Der LNC wird, wie in Abbildung \ref{fig:LNC-im-Gehäuse} zu sehen, auf einer Schiene montiert. Die Druckdatei für die Halterung auf der Schiene sind ebenfalls im GitHub-Repositroy hinterlegt. Durch diese Schiene kann der LNC einfach montiert und bei Bedarf auch wieder demontiert werden. Das Gehäuse bietet theoretisch noch Platz für zusätzliche Komponenten, z.B. einen Aufwärtsmischer oder Leistungsverstärker für die Einrichtung eines Uplink zu Es'Hail-2 (QO-100). Ebenfalls bietet das Gehäuse mehrere Durchführungsmöglichkeiten für die Koaxialleitungen. Mithilfe der S\_04212\_B Koaxialleitung soll der Antennenfeed an den HF-Eingang des Abwärtsmischers angeschlossen werden. Über die LMR 400 FR Koaxialleitung wird das resultierende ZF-Signal zur Fernspeiseweiche im Serverschrank gebracht.
\begin{figure}[H]
    \centering
    \includesvg[width=0.5\linewidth]{Bilder/Verkabelung Serverschrank}
    \caption{Skizze der geplanten Verschaltung im Serverschrank}
    \label{fig:geplante-Verschaltung}
\end{figure}
Die Skizze in Abbildung \ref{fig:geplante-Verschaltung} zeigt die geplante Verschaltung im Serverschrank. Die Fernspeiseweiche wird an ein Labornetzteil angeschlossen, welches die Versorgungsspannung $V_\mathrm{CC}$ für den Abwärtsmischer liefert. Dieser soll im QO-100 SSB Betriebsmodus betrieben werden, wofür eine Spannung von $V_\mathrm{CC}=12-17\,\text{V}$ über die Fernspeiseweiche eingespeist werden muss. In diesem Modus liegt der HF-Bereich des Abwärtsmischer zwischen $10489\,\text{MHz}$ und $10490\,\text{MHz}$. Der Frequenzbereich des resultierende ZF-Singals liegt zwischen $433\,\text{MHz}$ und $434\,\text{MHz}$.Über die beiden Anschlusspins an der Fernspeiseweiche wird mit dem Labornetzteil eine Spannung von $V_\mathrm{CC}=15\,\text{V}$ angelegt.\newline
Nach der Fernspeiseweiche wird das ZF-Signal über eine LMR 400 FR Koaxialleitung an das Patchfeld angeschlossen. Ab hier kann die Verkabelung mithilfe der beiden Hyperflex 5 Koaxialleitungen leicht vorgenommen und bei Bedarf auch verändert werden. Mit dieser Koaxialleitung wird das ZF-Signal zur RF-Schaltmatrix und und anschließend an den USRP X310 angeschlossen.\newline
\begin{figure}[H]
    \centering
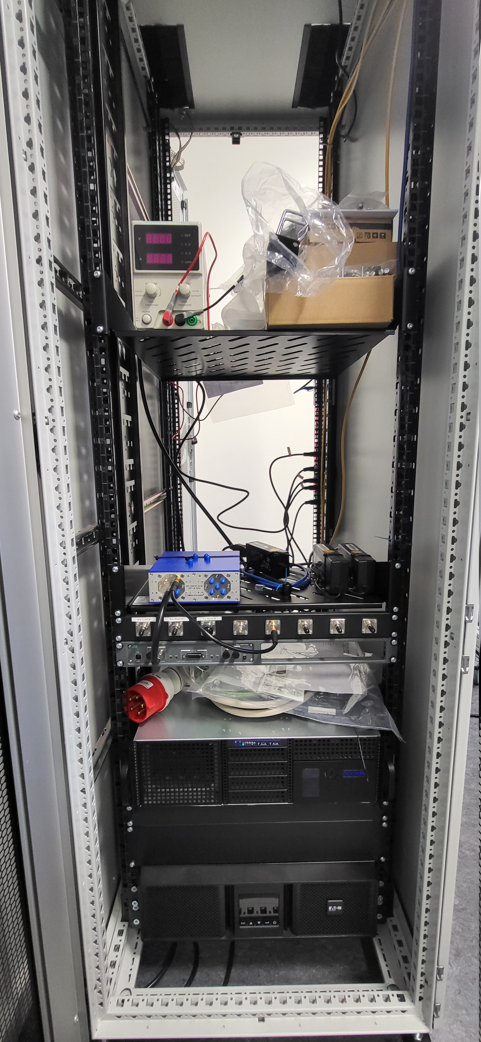
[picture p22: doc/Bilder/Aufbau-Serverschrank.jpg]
    
    \caption{Umgesetzter Aufbau der Komponenten im Serverschrank. Die Fernspeiseweiche ist nicht auf dem Bild zu sehen, da sie sich am hinteren Ende des Serverschranks befindet.}
    \label{fig:Aufbau-Serverschrank}
\end{figure}
Die Abbildung \ref{fig:Aufbau-Serverschrank} zeigt den umgesetzten Aufbau des Empfangssystem im Serverschrank. Der Aufbau konnte fast vollständig umgesetzt werden. Nur eine Hyperflex 5 Koaxialleitung ist nicht angekommen, weshalb eine kurze LMR 400 Leitung als Ersatz verwendet wird.

\subsection{Erstellen einer SDR-Software mit GNU Radio Companion}\label{kap:SDR Software}
Um den USRP X310 zu steuern und den Downlink von Es'Hail-2 (QO-100) verarbeiten zu können, wird mithilfe von GNU Radio Companion eine, für diese Anwendung spezifische, SDR-Software erstellt.\newline
GNU Radio ist ein freies und Open-Source Framework, welches Nutzern die Möglichkeit bietet Radio Systeme zu entwickeln, simulieren und anzuwenden. Der GNU Radio Companion ist das zugehörige Programm, mit welchen einfache Signalflussgraphen zur digitalen Signalverarbeitung erstellt werden können.\cite{GNU-Radio}

\subsubsection*{Herstellen der Verbindung zum USRP X310, einstellen der Frequenz und Ausgabe des Frequenzspektrums}
\begin{figure}[H]
    \centering
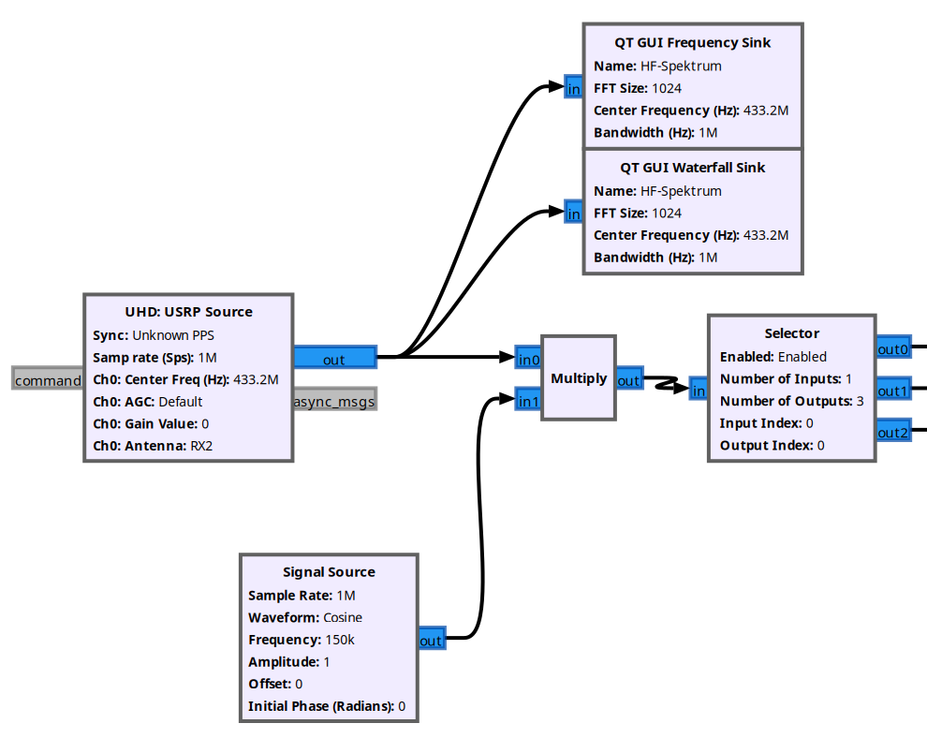
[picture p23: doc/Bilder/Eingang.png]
    
    \caption{Verwendeter Quellblock und variable Frequenzeinstellung in GNU Radio}
    \label{fig:Eingang}
\end{figure}
Die Abbildung \ref{fig:Eingang} zeigt den Anfangsbereich des Signalflussgraphen der erstellten SDR-Software. Den Anfang des Signalflussgraphen bildet ein Quellblock (engl. Source Block). Dieser wird benötigt, um eine Verbindung mit dem USRP X310 herzustellen. In GNU Radio gibt es mehrere verschiedene Quellblöcke zur Auswahl. Welcher verwendet werden kann hängt vom verwendeten SDR ab. Der verwendete USRP X310 bietet Unterstützung für den UHD-Treiber, weshalb als Quellblock ein UHD: URSP Quellblock verwendet wird.\cite{USRP-X310-Doku}\cite{GNU-Radio-USRP-Source}\newline
Über den Quellblock können viele verschiedene Einstellung des USRP X310 angepasst werden. Allerdings werden nicht alle Einstellmöglichkeiten benötigt. 
\begin{table}[H]
    \centering
    \begin{tabular}{c|c|p{7cm}}
       Einstellung  & Wert & Beschreibung\\
       \hline
        Abtastrate & $1\,\text{MS/s}$ & Setzen der Abtastrate vom SDR und damit auch die Bandbreite\cite{GNU-Radio-USRP-Source} \\
        Anzahl Kanäle & $1$ & Es wird nur ein Kanal für die geplante Anwendung benötigt. \\
        Mittenfrequenz & variabel & Die Mittenfrequenz kann variabel über eine Eingabe oder einen Schieber eingestellt werden. Als Standardwert wird $433.5\,\text{MHz}$ gewählt.\\
        RF Verstärkung & variabel & Die Verstärkung durch den USRP X310 kann variabel mit einem Schieber oder über eine Eingabe zwischen $0$ und $31.5\,\text{dB}$ angepasst werden. Als Standardverstärkung wird $0\,\text{dB}$ gewählt.\\
        Bandbreite & $0$ & Mit der Einstellung $0$ wird die Standardbreite vom Antialiasing Filter des USRP X310 verwendet.\cite{GNU-Radio-USRP-Source}\\
        Geräte Adresse & - & Hier kann die Geräte Adresse (z.B. IP-Adresse) des jeweilige USRP eingetragen werden. Das Feld wird leer gelassen. Damit wird der erste vom Programm gefundene USRP verwendet.\cite{GNU-Radio-USRP-Source}
    \end{tabular}
    \caption{Einstellungen im UHD: USRP Quellblock}
    \label{tab:Einstellungen-USRP-Quellblock}
\end{table}
Die Tabelle \ref{tab:Einstellungen-USRP-Quellblock} zeigt die getroffenen Einstellung im UHD: USRP Quellblock und damit auch die Einstellung des USRP X310. Die Mittenfrequenz wird Standardmäßig auf $433.5\,\text{MHz}$ gesetzt, da die ZF-Frequenz des Abwärtsmischer im SSB QO-100 Betrieb zwischen $433\,\text{MHz}$ und $434\,\text{MHz}$ liegt. Der Downlink des Schmalbandtransponder auf Es'Hail-2 (OQ-100) liegt dabei zwischen $433.5\,\text{MHz}$ und $434\,\text{MHz}$\newline
Das empfangene Frequenzspektrum soll mithilfe eines Wasserfalldiagramm und eines FFT-Spektrum dargestellt werden. Dafür gibt der Quellblock die Abtastwerte an einen Wasserfallblock (QT GUI Waterfall Sink) und einen FFT-Spektrumblock (QT GUI Frequency Sink) weiter\cite{GNU-Radio-Frequency-Sink}\cite{GNU-Radio-Waterfall-Sink}. Die Mittenfrequenz in beiden Spektren entspricht dabei der Mittenfrequenz des vom Quellblock ausgegeben Spektrums. Bei der Veränderung der Variable Mittenfrequenz verändert sich dementsprechend auch die dargestellte Mittenfrequenz.\newline
Der Multipliziererblock am Ausgang des Quellblocks wird als Mischer eingesetzt. Die Signalquelle fungiert dabei als lokaler Oszillator. Mit diesen beiden Blöcken besteht die Möglichkeit eine beliebige Frequenz im, vom Quellblock ausgegeben, Frequenzspektrum auszuwählen. Diese Frequenz wird Kanalfrequenz bezeichnet und kann über eine Eingabe oder durch einen Schieber im Betrieb verändert werden. Die Frequenz des lokalen Oszillator entspricht der Differenz zwischen der Mittenfrequenz und der Kanalfrequenz.\newline
Über einen folgenden Auswahlblock kann die Art der Demodulation ausgewählt werden. Zur Verfügung stehen dabei Einseitenband Amplitudenmodulation (SSB) mit oberen (USB) Seitenband und unteren (LSB) Seitenband, Frequenzmodulation (FM) und kontinuierliche Welle (engl. Continious Wave) CW.
\begin{figure}[H]
    \centering
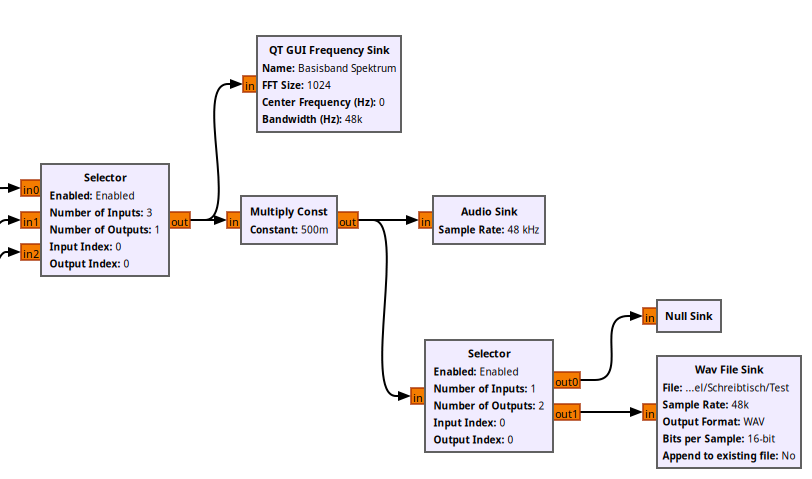
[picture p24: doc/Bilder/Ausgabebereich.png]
    
    \caption{Ausgabe des Audiosignals in GNU Radio}
    \label{fig:Ausgabe}
\end{figure}
Die Abbildung \ref{fig:Ausgabe} zeigt die möglichen Ausgabemöglichkeiten des Audiosignals. Das Audiosignal stammt dabei von dem jeweiligen angewendeten Demodulationsverfahren und wird über einen Auswahlblock an die Audio Ausgabe weitergegeben.\newline
Über einen FFT-Frequenzspektrum Block wird das Frequenzspektrum des Audiosignals angezeigt, wobei nur die positiven Frequenzen ab $0\,\text{Hz}$ dargestellt werden.\cite{GNU-Radio-Frequency-Sink}\newline
Das Audiosignal hat eine Abtastrate von $48\,\text{kS/s}$ und wird über eine Audio Senke an die Standard Ausgabe des Systems weitergegeben.\cite{GNU-Radio-Audiosink}\newline 
Die Lautstärke wird über den Multipliziererblock festgelegt. Sein Wert kann über einen Schieber im Betrieb zwischen $0$ und $1$ angepasst werden. Dabei entspricht $0$ stumm geschaltet und $1$ volle Lautstärke.\newline
Auch besteht die Möglichkeit das Audio Signal als eine 16-Bit .wav abzuspeichern. Verwendet wird dafür eine .wav Datei Senke (Wav File Sink). Der Speicherort, sowie der Name der .wav-Datei muss vor dem Start der Software in diesem Block angeben werden. Die Abtastrate des Audio Signals wird auf $48\,\text{kS/s}$ gestellt. Über einen Auswahlblock kann im Betrieb der Software die Aufnahme dann gestartet oder gestoppt werden.\cite{GNU-Radio-WAV}
\subsubsection*{FM-Demodulaton}
Bei der Frequenzmodulation (FM) werden die Informationen aus dem Basisband der Phase des Trägersignals auf moduliert.\cite{Nachrichtentechnik}\newline
\begin{equation*}
\begin{split}
        s_\mathrm{FM}(t)&=\hat{u}_\mathrm{T}\cdot \cos(\Psi_\mathrm{FM}(t))\\
        &=\hat{u}_\mathrm{T}\cdot \cos\left(\omega_\mathrm{T}+2\pi\cdot\Delta F\cdot\int u( \tau)d\tau\right)
\end{split}
\end{equation*}
Das Spektrum des FM-Signal kann nicht einfach angegeben werden, da es sich um ein nichtlineares Modulationsverfahren handelt. Die Anzahl der Nebenschwingungen neben dem Träger resultieren aus der Besselfunktion 0-ter Ordnung.\cite{Nachrichtentechnik}\newline
Für die Demodulation der FM-Signale wird eine erweiterte Version einer Beispielschaltung aus GNU Radio Dokumentation verwendet.\cite{GNU-Radio-FM}
\begin{figure}[H]
    \centering
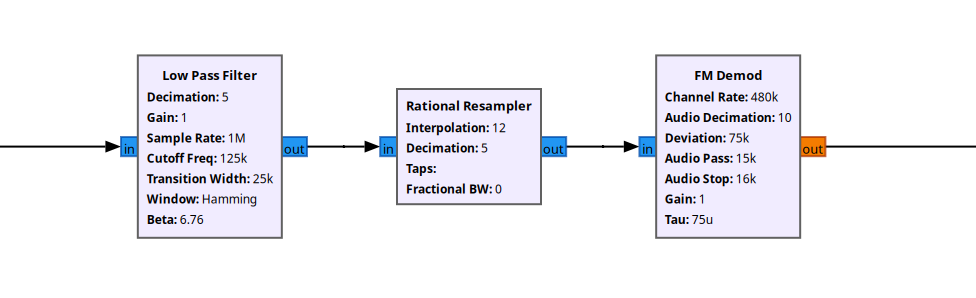
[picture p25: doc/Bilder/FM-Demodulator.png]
    
    \caption{Angewendeter FM Demodulator in GNU Radio}
    \label{fig:FM-Demodulator}
\end{figure}
Im ersten Schritt wird mit einem Tiefpassfilter das Frequenzspektrum begrenzt. So wird nur das gewünschte FM-Signal an den Demodulator weitergegeben. Die Grenzfrequenz des Tiefpasses kann über die Variable Filterbreite mit einem Schieber oder einer Eingabe verändert werden. Bei einer Radiostation beträgt die Bandbreite des FM-Signals ca. $120\,\text{kHz}$.\newline
Im nächsten Schritt wird mit einem rationalen Resampler die Abtastrate von $1\,\text{MS/s}$ auf $480\,\text{kS/s}$ reduziert.\cite{GNU-Radio-FM}\cite{GNU-Radio-Resampler}
\begin{equation*}
    \text{Faktor}=\frac{480000}{1000000}=\frac{12}{25}
\end{equation*}
Die Abtastrate wird erst um den Faktor $12$ erhöht und anschließend um den Faktor $10$ reduziert.\newline
Anschließend wird das FM-Signal mit dem FM-Demod Block von GNU Radio demoduliert.\cite{GNU-Radio-FM}. Die Kanalrate (engl. Channel Rate) wird auf die $480\,\text{kS/s}$ gestellt und die Audio Reduzierung auf $10$. Damit beträgt die Abtastrate des Audiosignals am Ausgang $48\,\text{kS/s}$. Somit kann das Audiosignal an die Audio Ausgabe weitergegeben werden.\cite{GNU-Radio-FM}\newline
Der FM-Demodulator wird mit in die SDR-Software aufgenommen, da mit diesem der Umgang mit dem SDR erprobt werden kann. Dieser kann verwendet werden um Radiostation zu empfangen und so z.B. neue Funktionen der Software zu testen.

\subsubsection*{Einseitenband-Demodulation}
Bei der Amplitudenmodulation (AM), wozu die Einseitenbandmodulation gehört, werden Information aus dem Basisband mit einem Mischer auf die Amplitude eines sinusförmigen Trägersignals auf moduliert. Das Trägersignal liegt dabei in einem für die Übertragung geeigneten Frequenzbereich.\cite{Nachrichtentechnik}\newline
\begin{equation*}
    \begin{split}
         s_\mathrm{AM}(t)&=s_\mathrm{BB}(t)\cdot s_\mathrm{T}(t)\\
         &=\frac{\hat{u}_\mathrm{BB}\cdot \hat{u}_\mathrm{T}}{2}\cdot (\cos((\omega_\mathrm{T}-\omega_\mathrm{BB})\cdot t)+\cos((\omega_\mathrm{T}+\omega_\mathrm{BB})\cdot t)
    \end{split}
\end{equation*}
\begin{figure}[H]
    \centering
    \includesvg[width=0.4\linewidth]{Bilder/AM-Signal}
    \caption{Spektrum eines AM-Signals}
    \label{fig:AM-Signal}
\end{figure}
Durch den Mischvorgang entstehen zwei Frequenzkomponenten links uns rechts neben dem Trägersignal, wie in Abbildung \ref{fig:AM-Signal} zu sehen. Diese beiden Frequenzkomponenten werden oberes und unteres Seitenband (engl. Upper- and Lower Sideband) genannt. Dabei befindet sich das obere Seitenband in der Regellage und das untere Seitenband in der Kehrlage\cite{Nachrichtentechnik}\newline
Beide Frequenzkomponenten enthalten dabei die gleichen Informationen aus dem Basisband, sprich sie sind identisch zu einander. Aus diesem Grund kann bei der Übertragung oder bei der Demodulation auf eins der beiden Seitenbänder verzichtet werden.\cite{Nachrichtentechnik}\newline
Um ein Einseitenbandsignal im Downlink von Es'Hail-2 (QO-100) demodulieren zu können, muss dieses zurück in das Basisband gebracht werden. Das resultierende komplexe Basisbandsignal muss dann nur noch mit einem Tief- oder Bandpass begrenzt werden. Für die Umsetzung des Einseitenband-Demodulators in GNU Radio wird eine angepasste Version eines Einseitenband-Demodulators aus der GNU Radio Dokumentation verwendet.\cite{GNU-Radio-SSB}
\begin{figure}[H]
    \centering
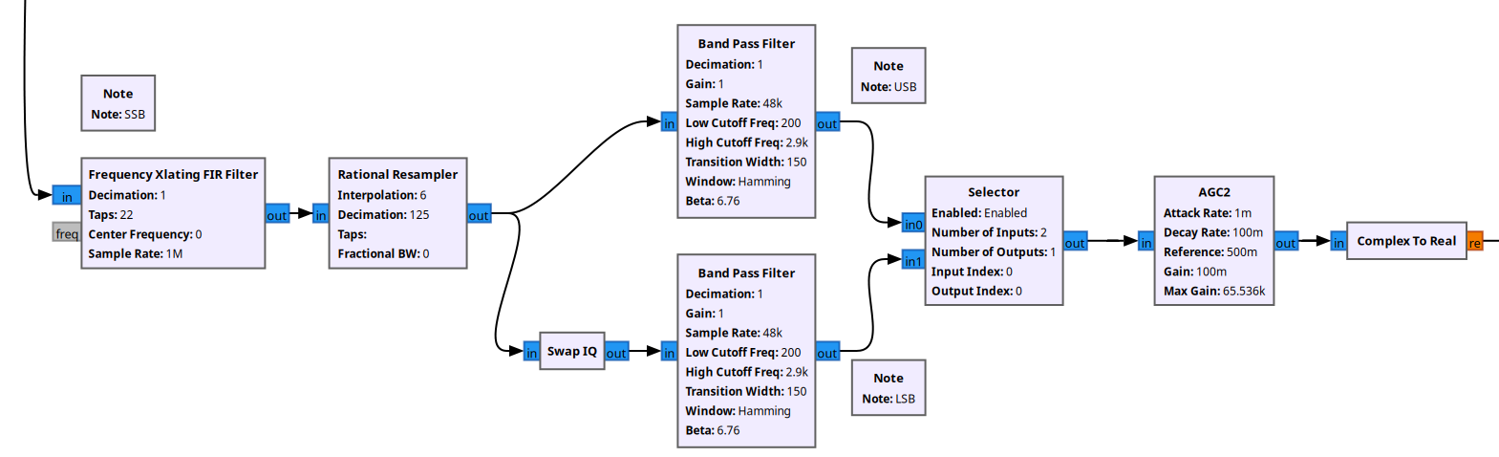
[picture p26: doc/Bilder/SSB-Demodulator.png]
    
    \caption{Signalflussgraph des umgesetzten Einseitenband-Demodulator in GNU Radio}
    \label{fig:SBB-Demodulator}
\end{figure}
Die Abbildung \ref{fig:SBB-Demodulator} zeigt den in GNU Radio umgesetzten Einseitenband-Demodulator. Das Herzstück des Demodulators ist ein Frequenz-umsetzender FIR Filter (Frequency Xlating FIR Filter). Dieser FIR Filter kombiniert mehrere Funktionen in einem Block. Das am Eingang anliegende Signal wird von diesem Filter Block in das Basisband verschoben. In den Eigenschaften des Blocks kann mit der Mittenfrequenz auch ein Offset zum gewünschten Signal eingestellt werden. Die bei der Frequenzverschiebung entstehenden hochfrequenten Anteile bei $\pm2\omega_\mathrm{T}$ können mit einem Filter, welcher über die Einstellung Taps definiert werden kann, entfernt werden. Auch kann über einen Faktor die Abtastrate des Signals dezimiert werden.\cite{GNU-Radio-SSB}
\begin{table}[H]
    \centering
    \begin{tabular}{c|c|p{4cm}}
       Einstellung  & Eingestellter Wert & Beschreibung\\
       \hline
       Dezimierung & $1$ & Keine Verringerung der Abtastrate\\
       Taps & $20$ & kein Filter, 20-fache Verstärkung\\
       Mittenfrequenz  & $0$ & kein Offset\\
       Abtastrate & $1\,\text{MS/s}$ & Abtastrate des eingehenden Signals
    \end{tabular}
    \caption{Getroffene Einstellungen des Frequenz-umsetzenden FIR Filter }
    \label{tab:Einstellungen-FIR-Filter}
\end{table}
Die Tabelle \ref{tab:Einstellungen-FIR-Filter} zeigt die verwendeten Einstellungen für den 
Frequenz-umsetzenden FIR Filter.\newline
Nachdem Frequenz-umsetzenden FIR Filter wird das Basisbandsignal in einen rationalen Resampler geführt, welcher die Abtastrate von $1\,\text{MS/s}$ auf $48\,\text{kS/s}$ reduziert. Die Abtastrate von $48\,\text{kS/s}$ entspricht der Standard Abtastrate von Audiosignalen.\cite{GNU-Radio-Resampler}
\begin{equation*}
    \text{Faktor}=\frac{48000}{1000000}=\frac{6}{125}
\end{equation*}
Die Abtastrate muss erst um den Faktor $6$ interpoliert und anschließend um den Faktor $125$ dezimiert werden.\newline
Bei dem Signal handelt es sich bisher um ein komplexes Signal im Basisband, welches ein oberes und unteres Seitenband enthalten kann. Das obere Seitenband liegt nach der Verschiebung in das Basisband im positiven Frequenzbereich und bildet die In-Phase Komponente. Das untere Seitenband liegt im negativen Frequenzbereich und bildet die Quadratur Komponente. Um das untere Seitenband nutzen zu können, muss die In-Phase Komponente mit der Quadratur Komponete getauscht werden. In GNU Radio kann diese Operation mit einem IQ-Tauschblock (Swap IQ) umgesetzt werden.\cite{GNU-Radio-SwapIQ}\newline
Mit einem nachfolgende Bandpassfilter wird das jeweiligen Seitenband in seiner Bandbreite begrenzt. Die untere Grenze des Bandpassfilters liegt bei $f_\mathrm{g}=200\,\text{Hz}$. Die obere kann während des Betriebes über eine Eingabe oder einen Schieber verändert werden. Die Wahl eines Bandpasses anstelle eines Tiefpasses kann mit der engen Bandbreite von $B=2.7\,\text{kHz}$ über den Schmalbandtransponder und dem Hauptsprachbereich der menschlichen Stimme erklärt werden. Dieser liegt zwischen $200\,\text{Hz}$ und $\approx3000\,\text{Hz}$\cite{Sprachbereich}. Durch den Einsatz des Bandpasses kann die volle Bandbreite von $B=2.7\,\text{kHz}$ auf den natürlichen Sprachbereich eines Menschen angepasst werden. Der Übergangsbereich des Bandpasses wird auf $150\,\text{Hz}$ gesetzt. Die Abtastrate bleibt bei $1\,\text{MS/s}$.\newline
Nach dem jeweiligen Bandpass kann über einen Auswahlblock das jeweiligen Seitenband ausgewählt werden. Das kann auch während der Benutzung der Software verwendet werden. Nach dem Auswahlblock wird das ausgewählte Seitenband von automatischen Verstärkungseinheit auf ein Referenzlevel angehoben oder reduziert. Die Angriffsrate (engl. Attack Rate) und die Abfallrate (engl. Decay Rate) bestimmen dabei die Rate, mit der das Audiosignal auf das Referenzlevel pro Abtastwert angehoben oder abgesenkt wird. Die Angriffsrate wird auf $0.01$ und die Abfallrate auf $0.1$ gesetzt. Die Abfallrate wird höher gewählt, um zu große Signale schneller abzuschwächen. Die Verstärkung oder Dämpfung pro Abtastwert liegt bei $0.1$. Zum Schluss wird das komplexe Audiosignal in ein reales Audiosignal umgewandelt. Anschließend wird das Audiosignal an den Ausgabebereich weitergegeben.  
\subsubsection*{CW-Demodulation}
Bei der CW-Modulation handelt es sich um eine Sonderform der Amplitudenmodulation. Bei einer herkömmlichen Amplitudenmodulationen werden Informationen (z.B. Audio) in Form von Basisbandsignalen mit einem kontinuierlichen Träger übertragen. Die Basisbandsignale bilden dabei die beiden Seitenbänder. Bei der CW-Modulation erfolgt die Übermittlung von Informationen durch das Ein- und Ausschalten des Trägers. Es werden keine Basisbandsignale selbst auf den Träger auf moduliert.\cite{CW}
\begin{figure}[H]
    \centering
    \includesvg[width=0.4\linewidth]{Bilder/AM zu CWsvg}
    \caption{Vergleich zwischen einem Signal mit AM (oben) und einem Signal mit CW (unten) im Zeitbereich}
    \label{fig:Vegleich-AM-CW}
\end{figure}
Eingesetzt wird diese Art der Kommunikation bei der Telegrafie (Morse Code).\cite{CW}\newline
Eine umfangreiche Demodulation ist bei Signalen mit CW Modulation nicht erforderlich. Sie müssen jegendlich in das Basisband verschoben werden und mit einem Tiefpass in ihrer Bandbreite begrenzt werden. Der Durchbruchsbereich des Tiefpasses ist möglichst eng zu wählen $(f_\mathrm{g}\leq2\,\text{kHz})$, um Rauschen und Einflüsse durch andere Signale zu minimieren.\newline
\begin{figure}[H]
    \centering
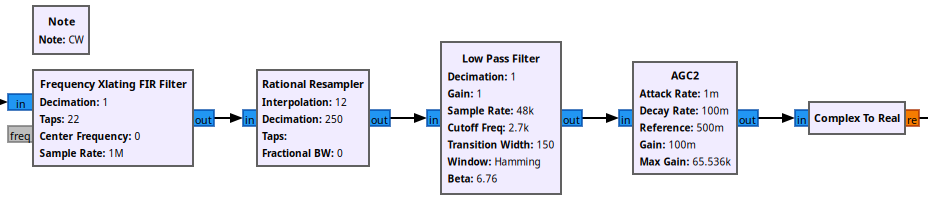
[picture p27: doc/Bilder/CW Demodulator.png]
    
    \caption{Signalflussgraph des in GNU Radio umgesetzten CW-Demodulators}
    \label{fig:CW-Demodulator}
\end{figure}
Die Abbildung \ref{fig:CW-Demodulator} zeigt den in GNU Radio umgesetzten Demodulator für CW-Signale. Ähnlich zum Demodulator für Einseitenband, wird für die für die Verschiebung des CW-Signals in das Basisband ein Frequenzumsetzender FIR Filter verwendet.\cite{GNU-Radio-SSB} Es wird kein Filter definiert, aber eine 20-fache Verstärkung eingestellt. Ebenso wird keine Dezimierung der Abtastrate mit dem Frequenzumsetzender FIR Filter vorgenommen.\newline
Die Reduzierung der Abtastrate wird mit einem folgenden rationalen Resampler durchgeführt. Mit diesem wird die Abtastrate von $1\,\text{MS/s}$ auf $48\,\text{kS/s}$, was der Abtastrate eines Audiosignals entspricht, herabgesetzt.\cite{GNU-Radio-Resampler}
\begin{equation*}
    \text{Faktor}=\frac{48000}{1000000}=\frac{6}{125}
\end{equation*}
Der Abtastrate wird erst um den Faktor $6$ interpoliert und anschließend um den Faktor $125$ dezimiert.\newline
Mit einem nachfolgenden Tiefpass wird das Basisband in seiner Breite begrenzt. Seine Grenzfrequenz $f_\mathrm{g}$ kann über die Bandbreite mit einer Eingabe oder Schieber während des Betriebes verändert werden. Bei CW-Signalen sollte ein möglichst schmaler Durchbruchsbereich  $(f_\mathrm{g}\leq2\,\text{kHz})$ gewählt werden. Der Übergangsbereich ist $150\,\text{Hz}$ breit.\newline
Die automatische Verstärkungseinheit hält den Pegel des Audiosignals auf einem gleichbleibenden Referenzlevel. In diesem Fall $0.5$. Die Angriffsrate wird auf $0.01$ und die Verfallsrate auf $0.1$ gesetzt. Dadurch werden Audiosignale mit zu großen Pegel schneller gedämpft. Die maximale Verstärkung pro Abtastwert liegt bei $0.1$. Anschließend wird das komplexe Audiosignal in ein reales umgewandelt. Damit kann es an den Ausgabebereich weitergegeben werden.

\subsection{Testen der Software}
Bevor die SDR-Software eingesetzt werden kann, müssen die einzelnen Demodulatoren und Funktionen der Software auf ihre Tauglichkeit überprüft werden. Für die Überprüfung des FM-Demodulator eignet sich der Empfang einer UKW-Radiostation.
\begin{figure}[H]
    \centering
    \includesvg[width=0.5\linewidth]{Bilder/Testaufbau FM}
    \caption{Angewendeter Testaufbau für den FM-Demodulator}
    \label{fig:Testaufbau FM-Demodulator}
\end{figure}
In der Abbildung \ref{fig:Testaufbau FM-Demodulator} ist der angewendete Aufbau zum testen des FM-Demodulators dargestellt. Zum testen wird eine Teleskop UKW Radioantenne über eine Koaxialleitung an den RX 2 SMA-Anschluss des RF A Erweiterungsbord vom USRP X310 angeschlossen. In der SDR-Software wird der FM-Demodulator ausgewählt. Die Mittenfrequenz wird auf $97\,\text{MHz}$ und die Kanalfrequenz auf $96.7\,\text{MHz}$ gestellt. An dieser Frequenz sollte sich  der Radiosender Bremen Next befinden. Als Filterbreite wird $B=57.423\,\text{kHz}$ eingestellt. Die Verstärkung bleibt bei $0\,\text{dB}$.
\begin{figure}[H]
    \centering
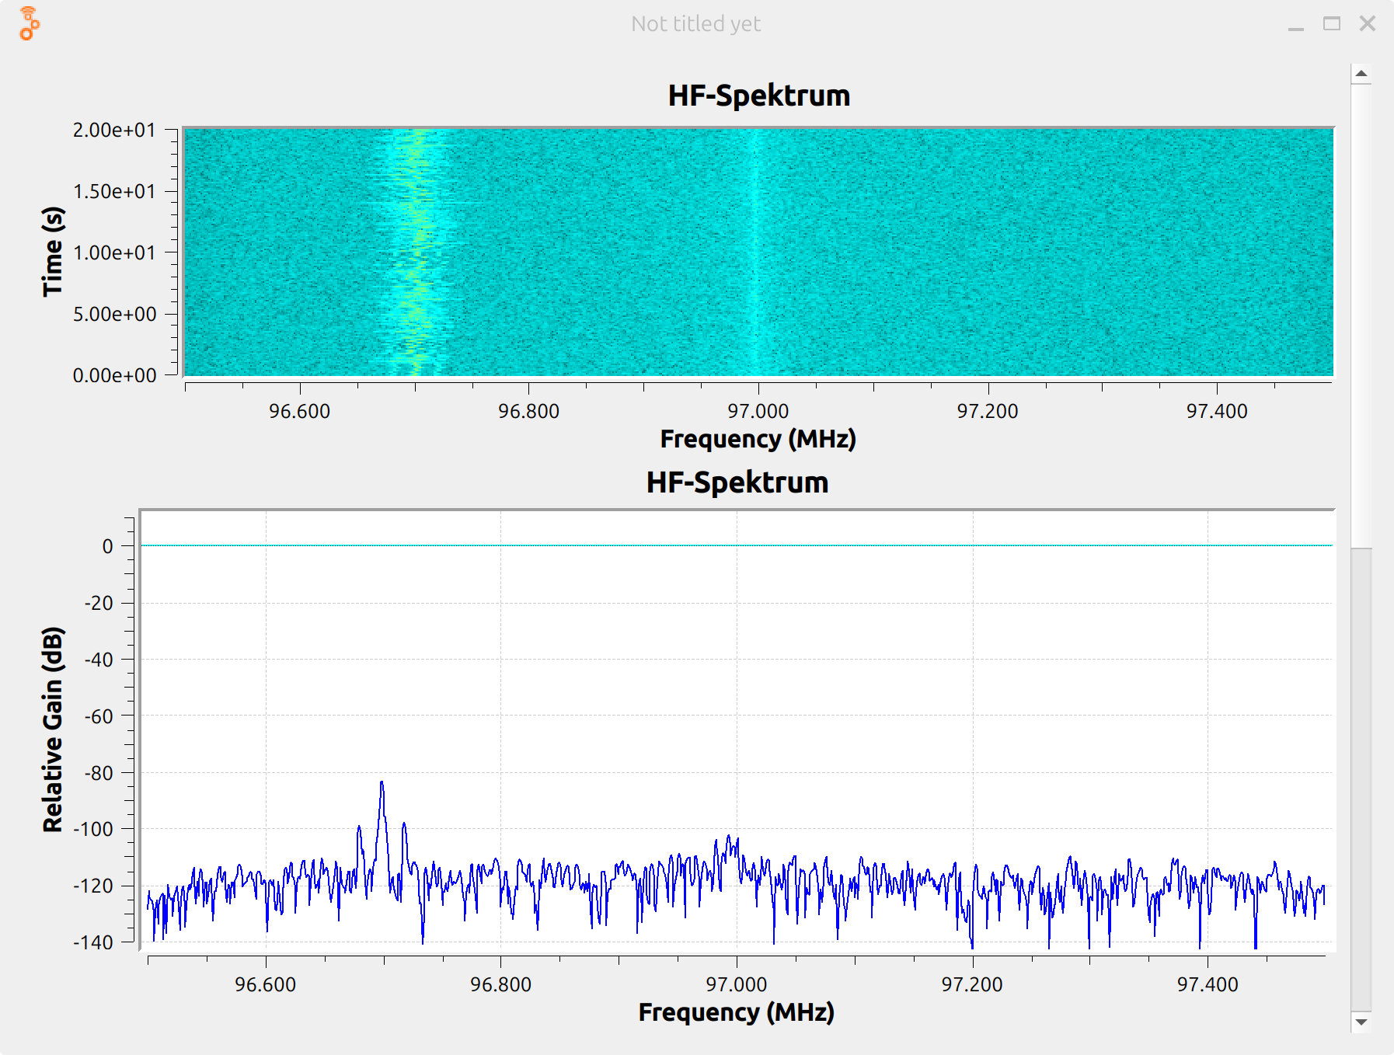
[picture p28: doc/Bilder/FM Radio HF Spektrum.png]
    
    \caption{HF-Spektrum beim Empfang von FM Radio}
    \label{fig:FM-HF-Spektrum}
\end{figure}
Die Abbildung \ref{fig:FM-HF-Spektrum} zeigt das empfangene HF-Spektrum beim Test des FM-Demodulators. Im oberen Plot ist ein Wasserfalldiagramm und im unteren Plot ein FFT-Spektrum. Die Mittenfrequenz liegt bei $97\,\text{MHz}$. In beiden Darstellungen kann gut das FM-Signal der Radiostation bei $96.7\,\text{MHz}$ erkannt werden. Der maximale Pegel liegt bei ca. $-82\,\text{dB}$. Der Rauschpegel liegt bei ca. $-112\,\text{dB}$. Das entspricht einem Signal-zu-Rauschabstand von $SNR=30\,\text{dB}$, was ein sehr zufriedenstellender Wert ist.
\begin{figure}[H]
    \centering
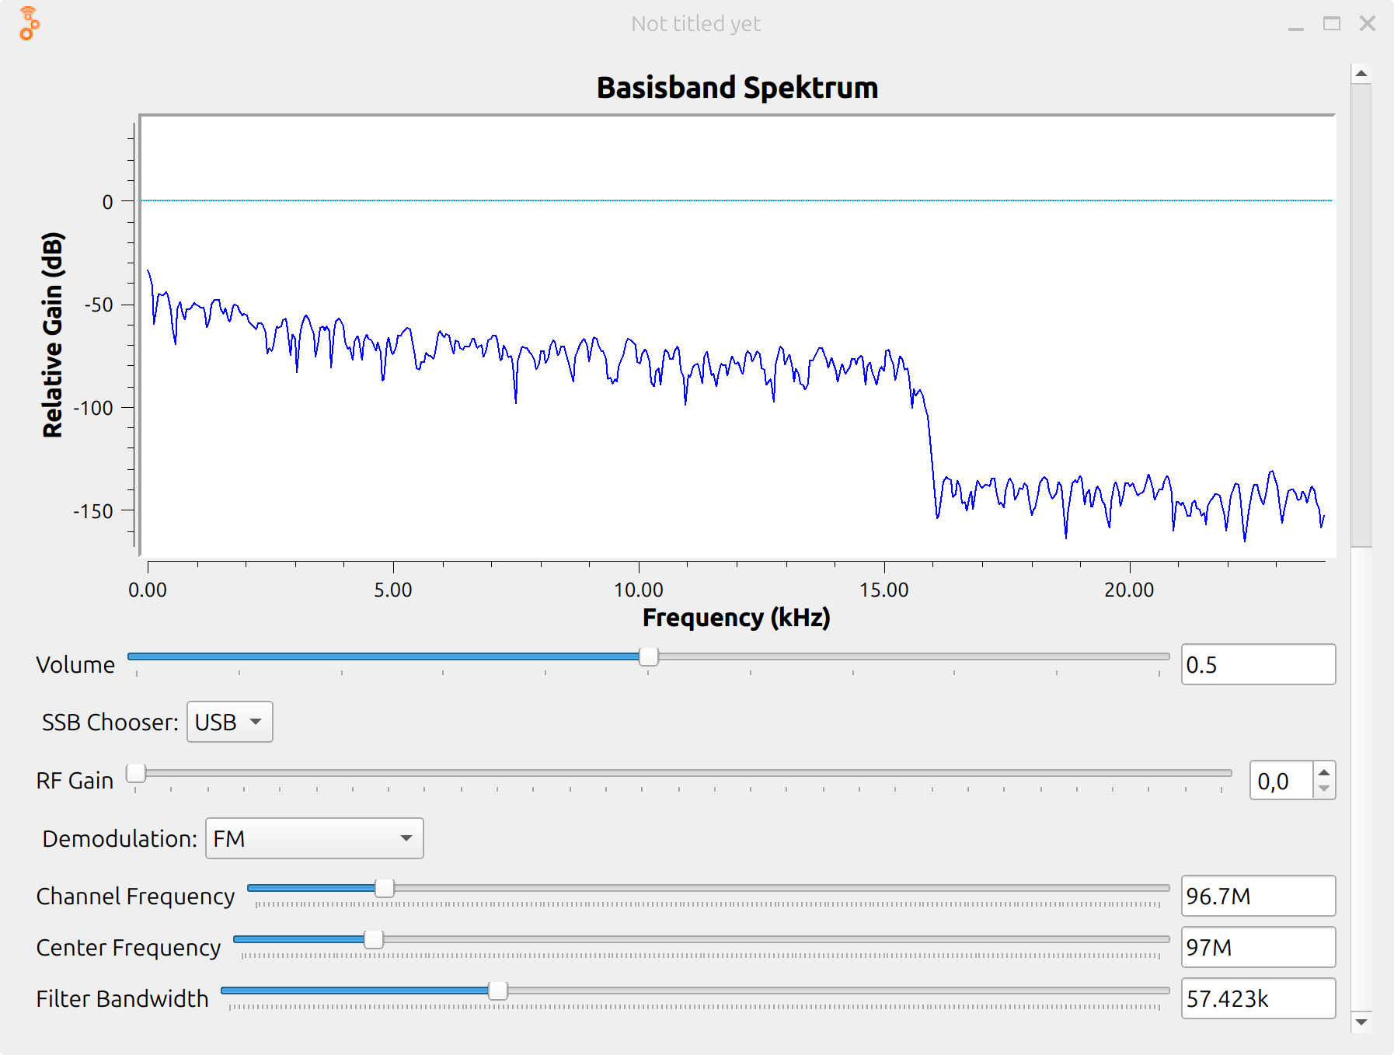
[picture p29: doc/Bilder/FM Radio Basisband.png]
    
    \caption{Spektrum vom Audiosignal des demodulierten FM-Signal}
    \label{fig:FM-Basisband}
\end{figure}
Das FFT-Spektrum in Abbildung \ref{fig:FM-Basisband} zeigt das Audiosignal des demodulierten FM-Signal. Durch den im FM-Demod Block integrierten Tiefpass wird das Audiosignal bei $15.5\,\text{kHz}$ abgegrenzt. Beim Testen des FM-Demodulators konnte ohne Probleme das Radioprogramm verfolgt werden. Es kann also von der vollen Funktionsfähigkeit des FM-Demodulators ausgegangen werden.\newline
Zum Testen des Einseitenband- und des CW-Demodulators wird ein anderer Testaufbau verwendet.
\begin{figure}[H]
    \centering
    \includesvg[width=0.7\linewidth]{Bilder/Testaufbau SSB CW}
    \caption{Angewendeter Testaufbau für den Einseitenband- und CW-Demodulator}
    \label{fig:Testaufbau-SSB-CW}
\end{figure}
In der Abbildung \ref{fig:Testaufbau-SSB-CW} ist der Aufbau für den Test des Einseitenband- und CW-Demodulator skizziert. Mit einem Hack RF One wird das jeweilige Signal generiert und über eine Koaxialleitung an der USRP X 310 angeschlossen. Verwendet wird dabei der Bereich RF A und der Anschluss RX2. Für die Generierung der Einseitenbandsignale wird ein einfacher Einseitenbandmodulator in GNU-Radio erstellt. Als Testübertragung wird die Audiospur eine .wav-Datei als oberes oder unteres Seitenband übertragen. Der verwendete Signalflussgraph ist im GitHub-Repository hinterlegt. \newline
Für den ersten Test des Einseitenband-Demodulator wird die Audiospur bei $433.05\,\text{MHz}$ als ein oberes Seitenband übertragen. In der SDR-Software wird die Mittenfrequenz auf $433.2\,\text{MHz}$ und die Kanalfrequenz auf $433.05\,\text{MHz}$ eingestellt. Die Filterbandbreite beträgt $B=2.7\,\text{kHz}$ und es wird eine Verstärkung von $G_\mathrm{SDR}=25\,\text{dB}$ verwendet.
\begin{figure}[H]
    \centering
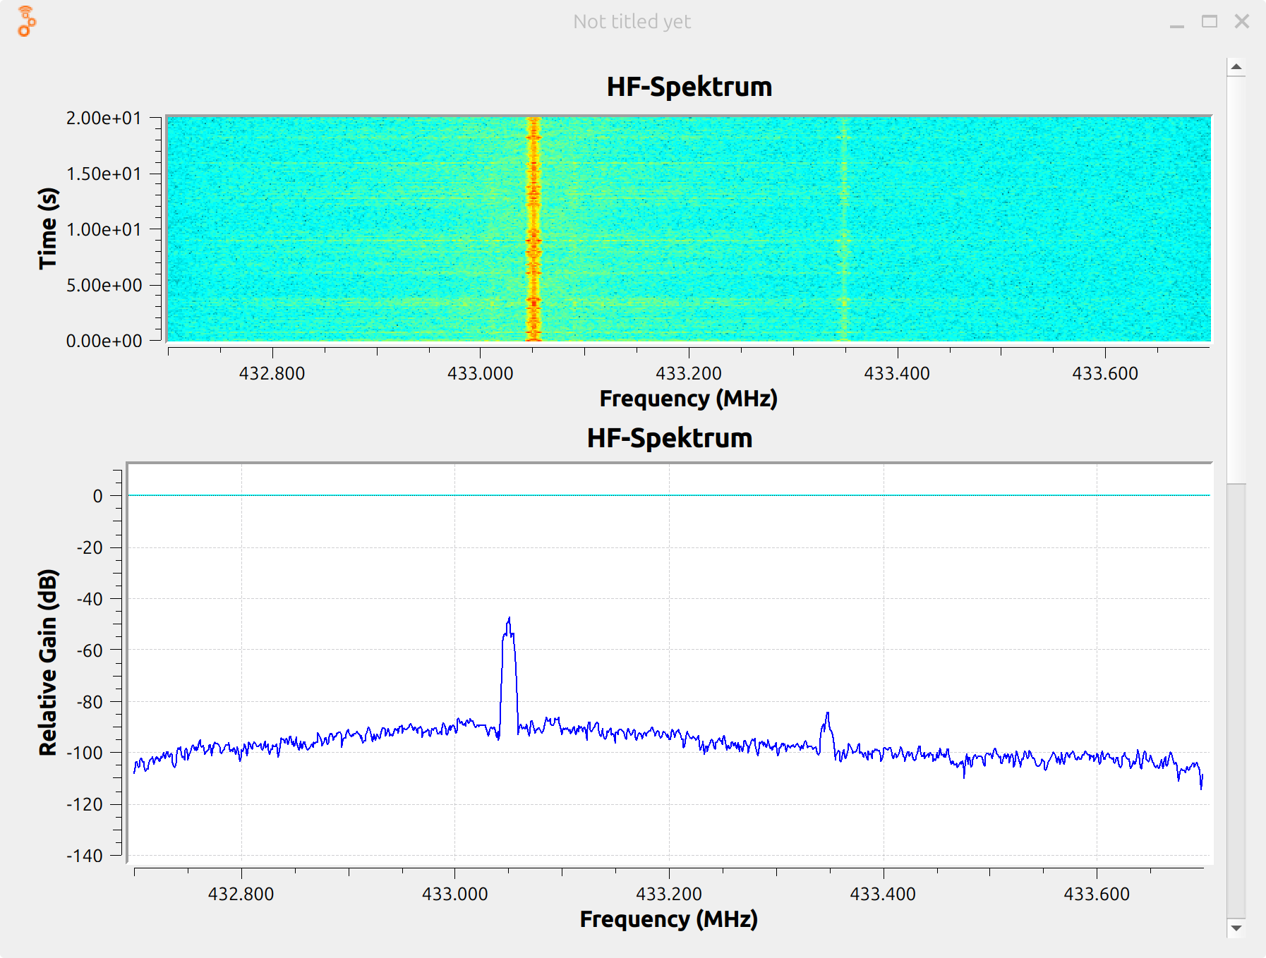
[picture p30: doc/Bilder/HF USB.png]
    
    \caption{Aufgezeichnetes HF-Spektrum bei der Übertragung des oberen Seitenbandes}
    \label{fig:USB-HF-Spektrum}
\end{figure}
In der Abbildung \ref{fig:USB-HF-Spektrum} ist das mit dem USRP X310 aufgezeichnete HF-Spektrum bei der Übertragung des oberen Seitenbandes zu sehen. Im oberen Plot ist das Spektrum in Form eines Wasserfalldiagramms dargestellt. Das obere Seitenband (rote Linie) liegt bei der gewünschten Frequenz von $433.05\,\text{MHz}$ und kann deutlich vom Rauschen unterschieden werden. Im unteren Plot ist das Frequenzspektrum als FFT-Spektrum dargestellt. Auch hier sticht das obere Seitenband deutlich heraus. Erreicht wird ein Pegel von $-45\,\text{dB}$. Der Rauschpegel liegt bei ca. $-90\,\text{dB}$. Damit wird ein Signal-zu-Rauschabstand von $SNR = 45\,\text{dB}$ erreicht, was für die Demodulation des oberen Seitenbandes mehr als ausreichend ist.
\begin{figure}[H]
    \centering
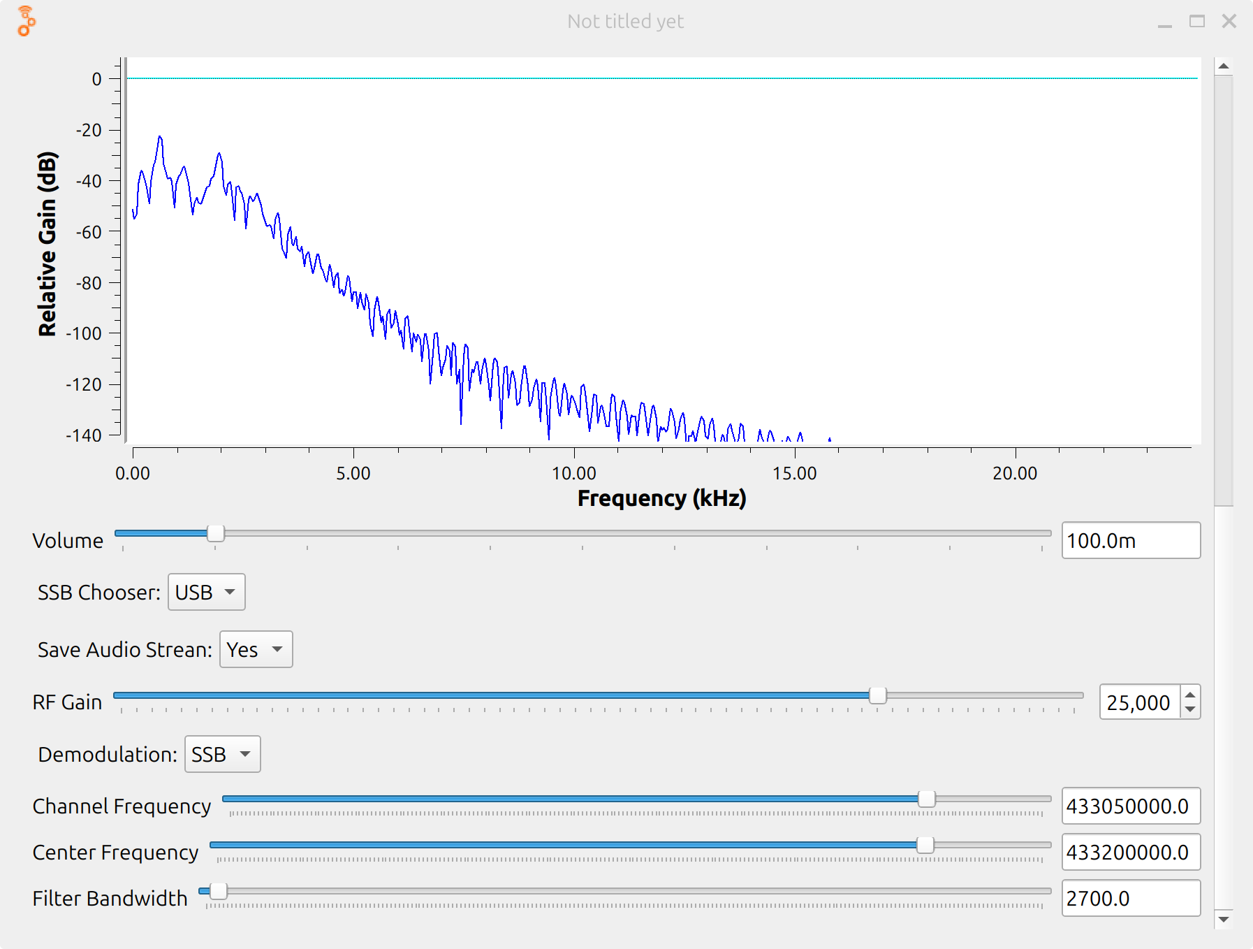
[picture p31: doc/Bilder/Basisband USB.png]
    
    \caption{Frequenzspektrum des demodulierten oberen Seitenbandes}
    \label{fig:USB-Basisband}
\end{figure}
Die Abbildung \ref{fig:USB-Basisband} zeigt das Spektrum des demodulierten Signals im Basisband. Erkennbar ist der Durchlassbereich von $300\,\text{Hz}$ bis $3\,\text{kHz}$ des Bandpassfilters. Durch die automatische Verstärkungseinheit wird der Pegel des Audiosignals auf ca. $-20\,\text{dB}$ angehoben. Dadurch ist das übertragende Audiosignal deutlich hörbar. Die aufgenommen Audiospur des übertragenden und demodulierten Testsignals ist im GitHub-Repository hinterlegt.\newine
Im zweiten Test des Einseitenband-Demodulators wird das Audiosignal als unteres Seitenband übertragen. Als Frequenz wird wieder $433.05\,\text{MHz}$ gewählt. Die Einstellung in der SDR-Software sind die gleichen wie im ersten Test. Jedoch wird als Seitenband jetzt das untere ausgewählt.
\begin{figure}[H]
    \centering
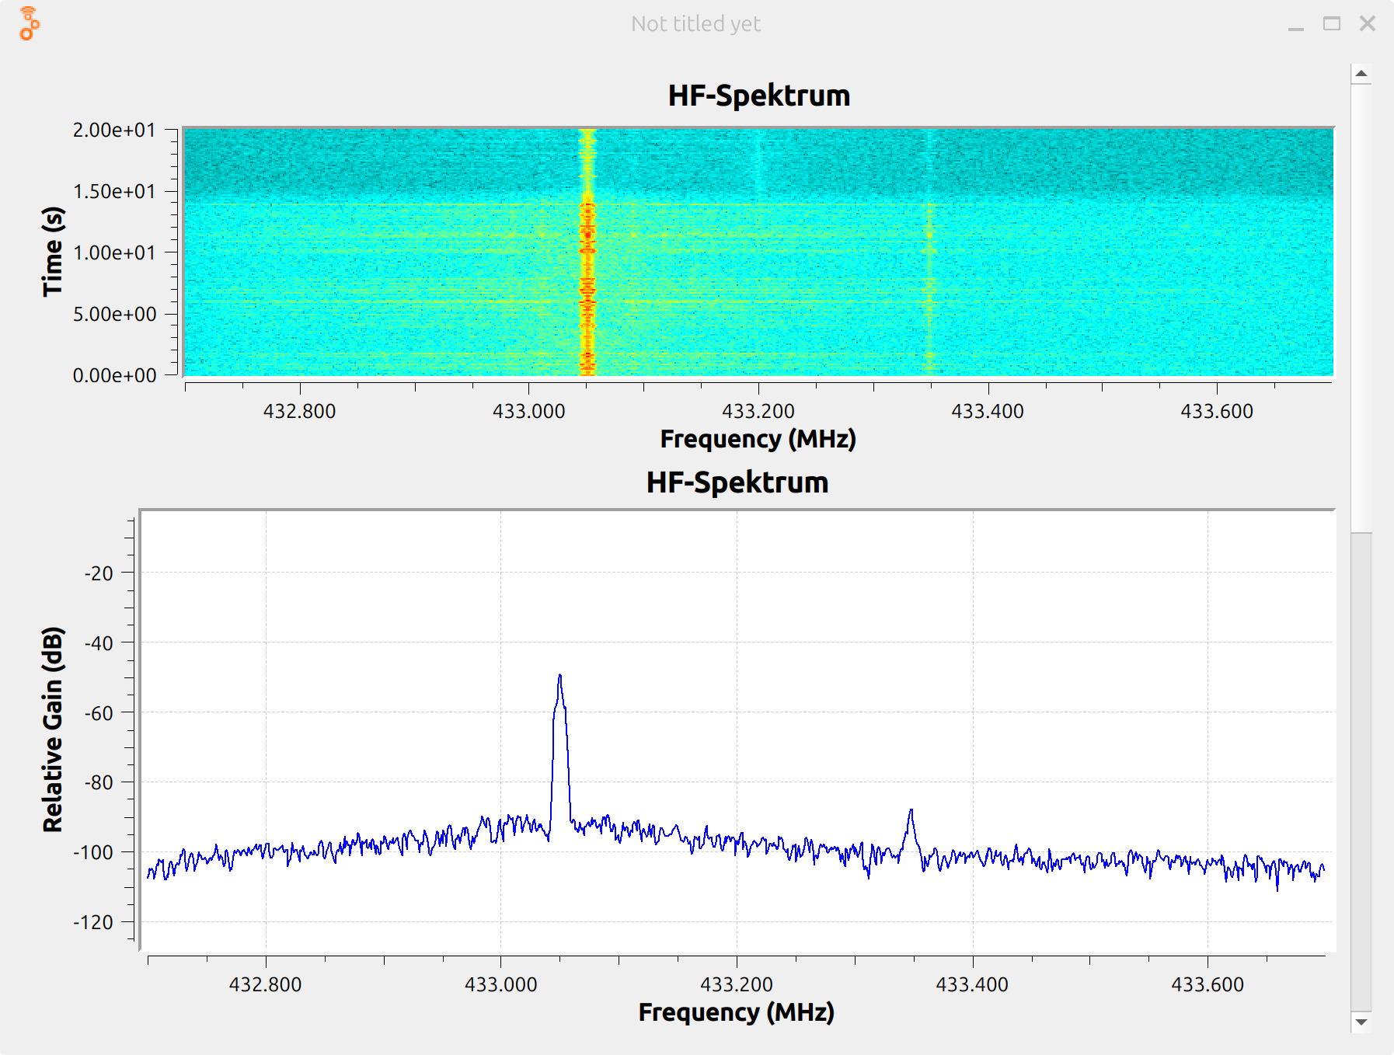
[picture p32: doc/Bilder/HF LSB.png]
    
    \caption{Aufgezeichnetes HF-Spektrum bei der Übertragung des unteren Seitenbandes}
    \label{fig:LSB-HF-Spektrum}
\end{figure}
Die Abbildung \ref{fig:LSB-HF-Spektrum} zeigt das mit dem USRP X310 augenommene HF-Spektrum als Wasserfalldiagramm (oberer Plot) und als FFT-Spektrum (unterer Plot). In beiden Darstellungen kann das unteren Seitenband an der gewünschten Frequenz von $433.05\,\text{MHz}$ angetroffen werden. Ähnlich wie beim oberen Seitenband wird ein Pegel von $-45\,\text{dB}$, sowie ein Signal-zu-Rauschabstand von $SNR=45\,\text{dB}$ erreicht, welcher mehr als ausreichend für die Demodulation ist.
\begin{figure}[H]
    \centering
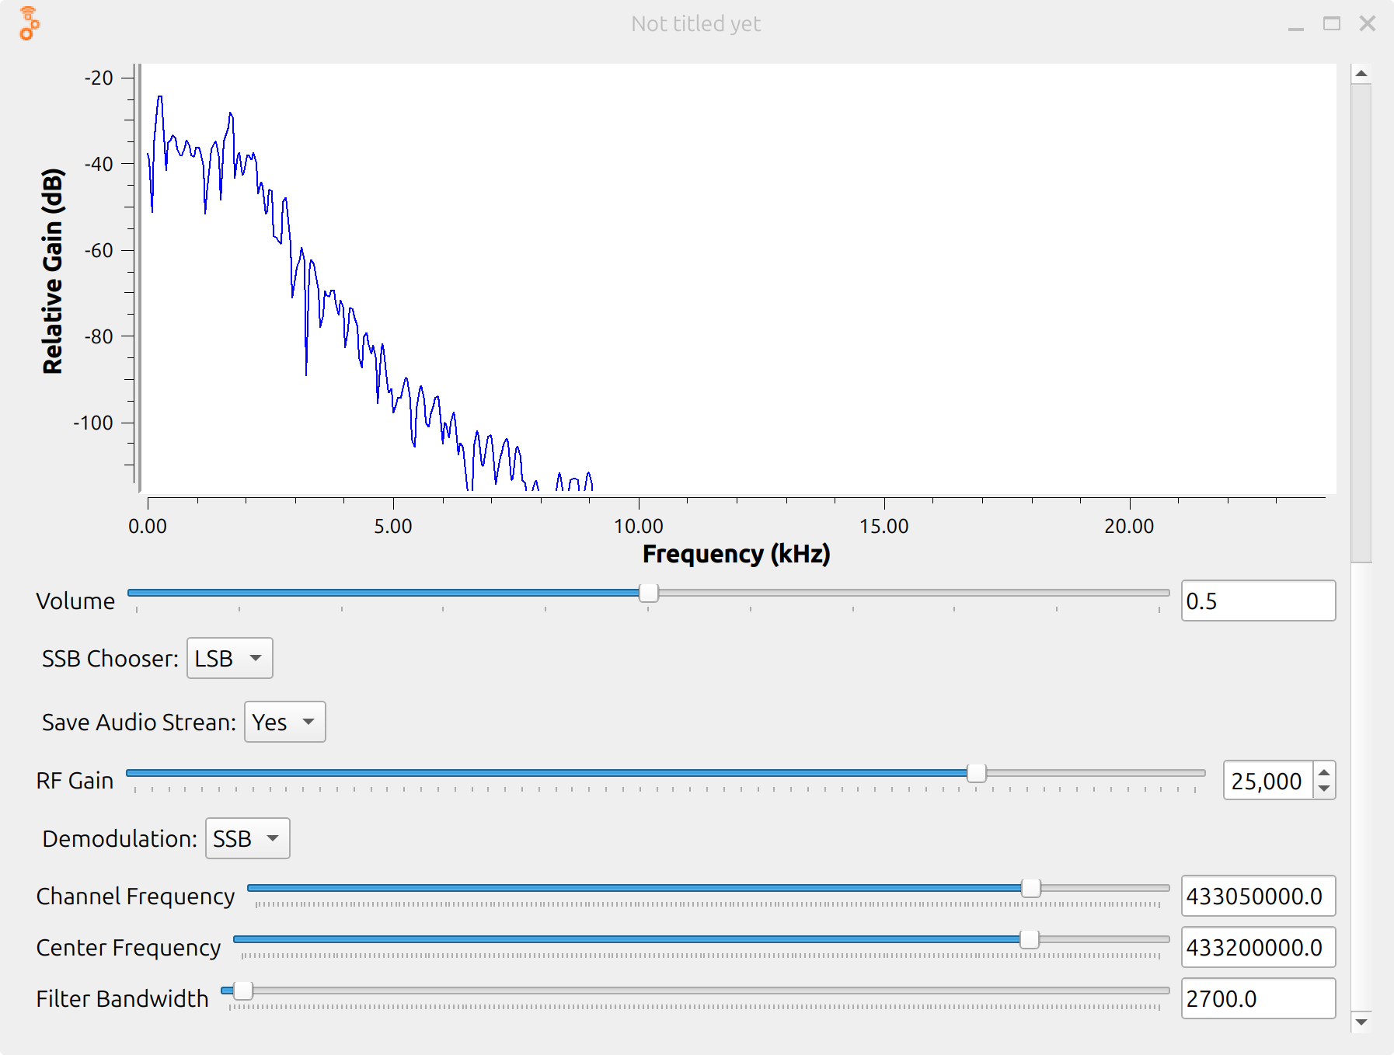
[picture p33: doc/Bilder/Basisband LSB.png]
    
    \caption{Frequenzspektrum des demodulierten unteren Seitenbandes}
    \label{fig:LSB-Basisband}
\end{figure}
In der Abbildung \ref{fig:LSB-Basisband} ist das Frequenzspektrum des demodulierten unteren Seitenbandes dargestellt. Ebenfalls ist wieder der Durchlassbereich des Bandpassfilter zwischen $300\,\text{Hz}$ und $3\,\text{kHz}$ erkennbar. Auch hier wird der Pegel des Audiosignals durch die automatische Verstärkungseinheit auf ca. $-25\,\text{dB}$ angehoben. Dadurch liegt der Pegel des Audiosignals im wahrnehmbaren Bereich. Die aufgezeichnete Audiospur des demodulierten unteren Seitenbandes ist im GitHub-Repository hinterlegt.\newline
Zum Testen des CW-Demodulators wird als .wav-Datei ein Morsecode mit einem $700\,\text{Hz}$ Ton als oberes Seitenband bei $433.05\,\text{MHz}$ übertragen. In der SDR-Software wird die Mittenfrequenz auf $433.2\,\text{MHz}$ und die Kanalfrequenz auf $433.05\,\text{MHz}$ eingestellt. Die Grenzfrequenz des Tiefpassfilters wird auf $1.2\,\text{kHz}$ gesetzt. Die Verstärkung beträgt $G_\mathrm{SDR}=25\,\text{dB}$.
\begin{figure}[H]
    \centering
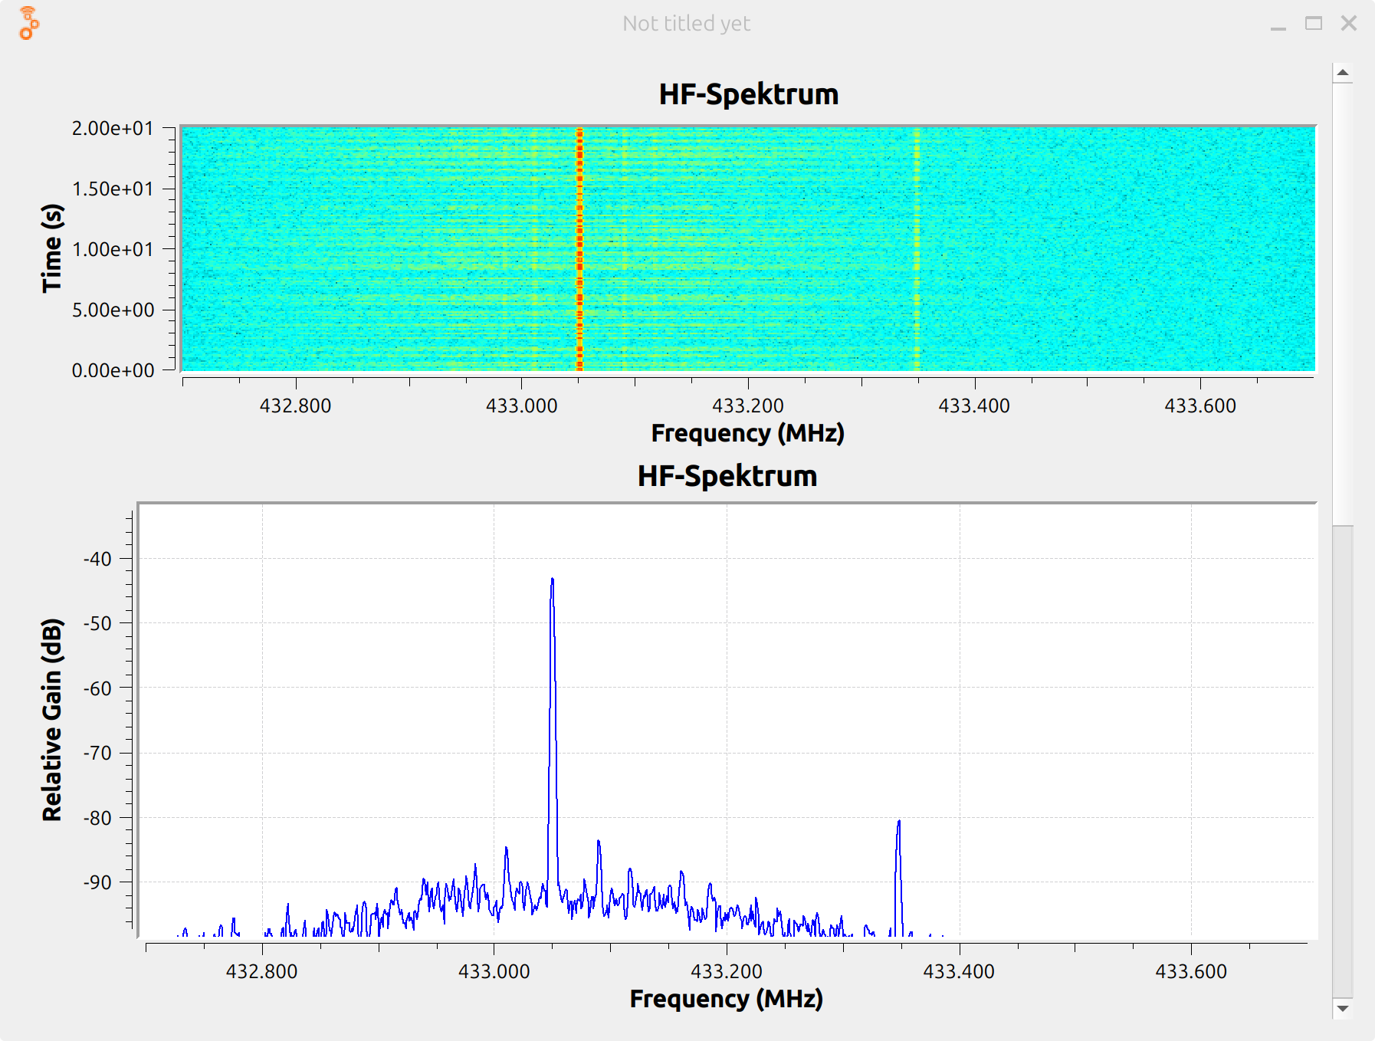
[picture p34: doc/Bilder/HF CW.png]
    
    \caption{Aufgezeichnetes HF-Spektrum bei der Übertragung des CW-Signals}
    \label{fig:HF-CW}
\end{figure}
Die Abbildung \ref{fig:HF-CW} zeigt das aufgezeichnete HF-Spektrum bei der Übertragung des CW-Signals als Wasserfalldiagramm (oberer Plot) und als FFT-Spektrum (unterer Plot). Das CW-Signal kann in beiden Darstellungsarten an der gewünschten Frequenz von $433.05\,\text{MHz}$ angetroffen werden. Der maximale Pegel liegt dabei bei ca. $-42\,\text{dB}$. Der Rauschpegel liegt wieder bei ungefähr $-90\,\text{dB}$, was zu eine Signal-zu-Rauschabstand von $SNR=47\,\text{dB}$ führt. Dieser ist ebenfalls mehr als ausreichend für die Demodulierung der CW-Signale.
\begin{figure}[H]
    \centering
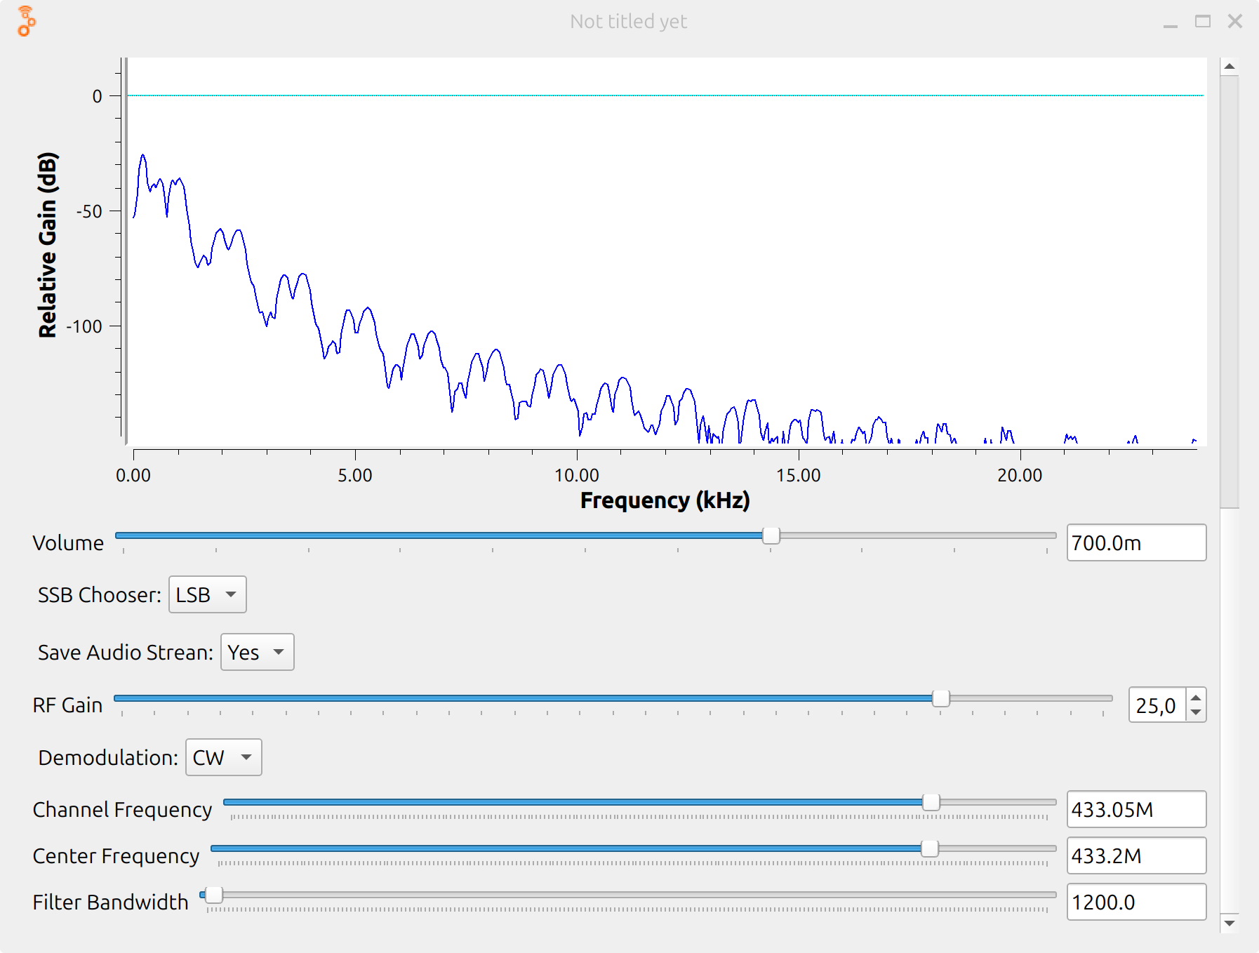
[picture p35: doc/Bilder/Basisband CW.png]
    
    \caption{Frequenzspektrum des demodulierten CW-Signals}
    \label{fig:CW-Basisband}
\end{figure}
Bei dem Spektrum in Abbildung \ref{fig:CW-Basisband} handelt es sich das Frequenzspektrum des demodulierten CW-Signals. Die Grenzfrequenz des Tiefpassfilters bei $1.2\,\text{kHz}$ ist gut zu erkennen. Wie beim Einseitenbanddemodulator wird auch beim CW-Demodulator der Pegel des demodulierten Signals auf ca. $-25\,\text{dB}$ angehoben. Dadurch konnte der Morsecode währrend des Test deutlic wahrgenommen werden. Eine Audioaufnahme des demodulierten Morsecode ist im GitHub-Repository hinterlegt. Aufgrund der kurzen Pulse bei Morsecode Übertragungen ist der $700\,\text{Hz}$ Trägerton nicht sichtbar.

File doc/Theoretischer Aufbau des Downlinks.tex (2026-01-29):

\subsection{Darstellung des Downlinks}
Beim Downlink handelt es sich um eine Datenverbindung zwischen einem Satelliten und einer Bodenstation, wobei der Datenaustausch von Satellit in Richtung der Bodenstation stattfindet.
\begin{figure}[H]
    \centering
    \includesvg[width=0.5\linewidth]{Bilder/Skizze Downlink.svg}
    \caption{Vereinfachte Darstellung des Downlinks}
    \label{SkizzeDownlink}
\end{figure}
Die Abbildung \ref{SkizzeDownlink} zeigt eine vereinfachte Darstellung des Downlinks zwischen dem Satelliten Es'Hail-2 (QO-100) und des Empfangssystem der Bodenstation am IAT. Der Downlink kann in drei Bereiche eingeteilt werden - Dem Sender, der Übertragungsstrecke und dem Empfänger. 
\subsection{Sender - Schmalbandtransponder auf Es'Hail-2 (QO-100)}
Beim ersten Bereich des Downlinks handelt es sich um den Sender. In diesem Fall handelt es sich um den Schmalbandtransponder auf Es'Hail-2 (QO-100).
\begin{figure}[H]
    \centering
    
    \caption{Vereinfachte Darstellung des Schmalbandtransponders auf Es'Hail-2\cite{Satellite_Communications_Systems}}
    \label{fig:Vereinfachter Sender}
\end{figure}
Die Abbildung \ref{fig:Vereinfachter Sender} zeigt ein vereinfachtes Blockschaltbild des Schmalbandtransponders auf Es'Hail-2 (QO-100). Der Schmalbandtransponder deckt ungefähr $1/3$ der Erdoberfläche ab, siehe Abbildung \ref{fig:CoverageEsHail2Amateur}, und hat die Aufgabe die Signale, welche von Amateurfunkern über den Uplink zum Satelliten gesendet werden, wieder in Richtung Erde mit der zusenden.\newline
Der Schmalbandtransponder verwendet zur Verstärkung der über den Uplink gesendeten Signale einen TWTA (engl.Traveling-Wave Tube Amplifier) mit einer Ausgangsleistung von $P_\mathrm{TX}=100\space\text{W} = 50\space\text{dBm}$\cite{PräsiEsHail2}. Die internen Verluste des Schmalbandtransponders werden mit $L_\mathrm{SAT}=1.5\space\text{dB}$ angegeben\cite{PräsiEsHail2}. Mit den beiden Angaben und mit einer $OBO = 6\space\text{dB}$ (engl. Output Back Off)\cite{PräsiEsHail2} lässt sich die Sendeleistung $P_\text{T}$ des Schmalbandtransponders ermitteln.\newline
\begin{equation}
    \label{Sendeleistung Es'Hail-2}
    P_\mathrm{T}=P_\mathrm{TX,dB}-L_\mathrm{SAT,dB}-OBO_\mathrm{dB}=50\space\text{dBm}-1.5\space\text{dB}-6\space\text{dB}=42.5\space\text{dBm}
\end{equation}
Der Schmalbandtransponder auf Es'Hail-2  verwendet eine Hornantenne mit einem Gewinn von $G_\mathrm{T}=17\space\text{dBi}$\cite{PräsiEsHail2} und einer 3dB-Strahlungsbreite von $\theta_\mathrm{3dB}=17.4\space\degree$\cite{PräsiEsHail2}. Mit der Sendeleistung $P_\mathrm{T}$ und Gewinn $G_\mathrm{T}$ der Antenne kann dann das $EIRP$ des Satelliten über die Gleichung \ref{eq:EIRPdBm} bestimmt werden. Zu den Verlusten der verwendeten Antenne lassen sich keine Informationen finden, weshalb eine verlustlose Antenne angenommen wird.
\begin{equation}
    EIRP_\mathrm{dBm}=P_\mathrm{T,dBm}+G_\mathrm{T,dBi}-L_\mathrm{SATANT,dB}=42.5\,\mathrm{dBm}+17\,\mathrm{dBi}-0\,\mathrm{dB}=59.5\,\mathrm{dBm}
    \label{eq:EIRP_dBm_Eshail2}
\end{equation}
Das in Gleichung \ref{eq:EIRP_dBm_Eshail2} $EIRP_\mathrm{dBm}$ kann in auch in $\text{W}$ angegeben werden.
\begin{equation}
    EIRP=10^{\frac{59.5\,\mathrm{dBm}}{10}}\cdot0.001\,\text{W}=891.251\,\text{W}
    \label{eq:EIRP_W_EsHail2}
\end{equation}
Ebenfalls kann die Strahlungsleistungsdichte $S_\mathrm{SAT}$ der von Es'Hail-2 abgestrahlten EM-Welle bestimmt werden. Diese ist für die spätere Bestimmung der Empfangsleistung von Bedeutung.\newline
Ermittelt werden kann die Strahlungsleistungsdichte $S_\mathrm{SAT}$ mit der Gleichung \ref{eq:isotroperkugelstrahler-strahlungsleistungsdichte} unter der Berücksichtigung des Gewinns $G_\mathrm{T}=17\space\mathrm{dBi}$ der Hornantenne, sowie der Entfernung $D_\mathrm{SAT}$, welche in Gleichung \ref{eq:EntfernungEsHail2} ermittelt wird.

\begin{equation}
    S_\mathrm{SAT}=\frac{P_\mathrm{T}\cdot \frac{G_\mathrm{T}}{L_\mathrm{ANT}}}{4\pi\cdot D_\mathrm{SAT}}=\frac{EIRP}{4\pi\cdot D_\mathrm{SAT}}=\frac{891.251\,\text{W}}{4\pi\cdot 38676\,\text{km}}=1.834\cdot10^{-6}\,\frac{\text{W}}{\text{m}^2}
    \label{eq:Strahlungsleistungsdichte_EsHail2}
\end{equation}

\subsection{Übertragungsstrecke zwischen Es'Hail-2 und der Bodenstation am IAT}
Den zweiten Bereich bildet die Übertragungsstrecke zwischen dem Satelliten Es'Hail-2 und der Bodenstation am IAT. Bevor die vom Schmalbandtransponder abgestrahlten EM-Wellen von der Bodenstation am IAT empfangen werden können legen diese eine große Entfernung zurück. Auf dem Weg verlieren die abgestrahlten EM-Wellen einen großen Teil ihrer Leistung, was mit der Dämpfung $L$ ausgedrückt wird. Die gesamt Dämpfung $L$ setzt sich dabei aus mehreren einzelnen Dämpfungen zusammen, welche in unterschiedlichen Abschnitten der Übertragungsstrecke auftreten.
\subsubsection*{Freiraumdämpfung}
Die Freiraumdämpfung, auch Pfadverlust genannt, $L_\mathrm{FR}$ bildet den größten Teil der auftretenden Dämpfung $L$. Sie ist abhängig von der Entfernung $D_\mathrm{SAT}$ zwischen dem Sender und Empfänger, Es'Hail-2 und der Bodenstation am IAT, sowie die Wellenlänge $\lambda$ von der Frequenz $f$, mit welcher der Downlink betrieben wird.
\begin{equation}
    \label{eq:Freiraumdämpfung}
    L_\mathrm{FR,dB}=10\cdot\log_\mathrm{10}\left( \left( \frac{4\pi\cdot D_\mathrm{SAT}}{\lambda} \right)^2\right)=20\cdot\log_\mathrm{10} \left( \frac{4\pi\cdot D_\mathrm{SAT}}{\lambda} \right)
\end{equation}
Mit der Freiraumdämpfung $L_\mathrm{FR}$ wird die Abnahme der Strahlungsleistungsdichte $S_\mathrm{SAT}$ beschrieben. Ein isotroper Kugelstrahler strahlt die Energie, in Form von EM-Wellen, gleichmäßig in allen Richtung ab. Somit verteilt sich die Energie gleichmäßig in Form einer Kugel um die Quelle herum, wie es auch in Gleichung \ref{eq:isotroperkugelstrahler-strahlungsleistungsdichte} und \ref{eq:Strahlungsleistungsdichte_EsHail2} ausgedrückt wird. Wird die Oberfläche der Kugel in gleichgroße Bereiche aufgeteilt, weisen alle Bereiche die gleiche Strahlungsleistungsdichte $S_\mathrm{SAT,xy}$ auf\cite{RadartutorialFreiraumdämpfung}.\newline
Mit steigender Entfernung $r$ zur Quelle, welche dem Radius der Kugel entspricht, wird auch die Oberfläche der Kugel größer. Da aber die von dem isotropen Kugelstrahler abgestrahlte Energie gleichbleibend ist, hat die steigende Oberfläche der Kugel eine Abnahme der Strahlungsleistungsdichte $S_\mathrm{SAT}$ zur Folge.\cite{RadartutorialFreiraumdämpfung}
\begin{figure}[H]
    \centering
    \includesvg[width=0.4\linewidth]{Bilder/Freiraumdämpfung Beispiel.svg}
    \caption{Graphische Repräsentation der Freiraumdämpfung}
    \label{Graphische Repräsentation der Freiraumdämpfung}
\end{figure}
Mit der Wellenlänge 
\begin{equation*}
   \lambda_\mathrm{center}=\frac{c}{f_\mathrm{center}}=\frac{3\cdot 10\,\frac{\text{m}}{\text{s}}}{10489.750\,\text{MHz}}=0.0286\,\text{m} 
\end{equation*}
und der Entfernung $D_\mathrm{SAT}$ aus Gleichung \ref{eq:EntfernungEsHail2} kann die Freiraumdämpfung $L_\mathrm{FR}$ über Gleichung \ref{eq:Freiraumdämpfung} bestimmt werden.
\begin{equation}
    \label{eq:BestimmteFreiraumdämpfung}
    L_\mathrm{FR,dB}=20\cdot\log_\mathrm{10}\left( \frac{4\pi\cdot D_\mathrm{SAT}}{\lambda} \right)=20\cdot\log_\mathrm{10}\left( \frac{4\pi\cdot 38676\,\text{km}}{0.0286\,\text{m}}\right)=204.61\,\text{dB}
\end{equation}
Die Freiraumdämpfung $L_\mathrm{FR,dB}$ ist zusammen mit der Strahlungsleistungsdichte $S_\mathrm{SAT}$ oder dem $EIRP$ wichtig für Bestimmung der empfangen Leistung $P_\mathrm{R}$ an der IAT Bodenstation.\newline
Obwohl sich der größte Teil der Übertragungsstrecke im freien Raum befindet, müssen neben der Freiraumdämpfung $L_\mathrm{FR,dB}$ noch zusätzlich Dämpfungen innerhalb der Atmosphäre berücksichtigt werden. Beim durchqueren der Atmosphäre erfahren die elektromagentischen Wellen eine nicht zu vernachlässigende Dämpfung. Die Dämpfung basiert dabei hauptsächlich durch die Absorption und Entpolarisierung der elektromagnetischen Wellen, welche durch Gase, Partikel und Dämpfe innerhalb der Atmosphäre hervorgerufen werden. \cite{Satellite_Communications_Systems}\newline
\begin{figure}[H]
    \centering
    \includesvg[width=0.5\linewidth]{Bilder/Atmosphäre_Stufen}
    \caption{Aufbau der Atmosphäre\cite{Bild_Atmosphäre}}
    \label{fig:Aufbau-der-Atmosphäre}
\end{figure}
Im Frequenzbereich von $1\,\text{GHz}$ bis $30\,\text{GHz}$ haben hauptsächlich Wasser- und Sauerstoffmoleküle eine großen Einfluss auf die elektromagnetischen Wellen. Daher sind hauptsächlich zwei Schichten der Atmosphäre von Interesse. Die Troposphäre, in welcher sich das Wettergeschehen abspielt, und die Ionosphäre, in welcher die UV-Strahlung der Sonne Gasmoleküle ionisiert.\cite{Ionosphäre} \cite{Satellite_Communications_Systems}\newline

\subsubsection*{Dämpfung durch Regen und Schnee}
Das Wetter, hauptsächlich Regen und Schnee, in der Troposphäre bildet den größten Teil der Dämpfung innerhalb der Atmosphäre. Gerade bei höheren Frequenzen $(f\geq10\,\text{GHz})$ darf die Dämpfung durch Regen $L_\mathrm{Regen}$ nicht vernachlässigt werden.
Für die Dämpfung durch Regen sind Niederschlagsraten $R_\mathrm{p}$ in $\text{mm/h}$ interessant, welche nur zu einem bestimmte Prozentsatz $p$ die durchschnittliche Niederschlagsmenge $\text{mm/h}$ eines Jahres überschreiten.\cite{Satellite_Communications_Systems}\newline
Für de Betrieb des Downlinks können drei Wetterbedingungen festgelegt werden.
\begin{itemize}
    \item Klarer Himmel (Clear Sky): Den größten Teil der Zeit $(p\approx20\,\%)$ sind mit niedrigen Regenraten zu rechnen. Je kleiner die Niederschlagsrate $R_\mathrm{p}$ in $\text{mm/h}$ ist, desto geringer ist die zu erwartende Dämpfung $L_\mathrm{Regen}$. Bei der Bedingung klarer Himmel sind die Niederschlagsmengen so gering, dass die resultierende Dämpfung vernachlässigt werden können.\cite{Satellite_Communications_Systems}
    
    \item leichter Regen (light Rain): Die häufigsten zu erwartenden Regenschauer sind leichte Regenschauer. Zu leichten Regenschauern zählen Regenschauer dessen Niederschlagsrate $R_\mathrm{p}$ in $\text{mm/h}$ zu $p=5\,\%$ der Zeit den jährlichen Durchschnitt $\text{mm/h}$ überschreiten. Die zu erwartende Dämpfung $L_\mathrm{leichterRegen}$ ist überschaubar und bietet einen guten Schätzwert für durchschnittliche Regenschauer.
    
    \item Regen (Rain): Starke Niederschläge haben eine sehr große Auswirkung auf die elektromagnetischen Wellen. Die starken Niederschläge verursachen eine nicht zu vernachlässigende Dämpfung $L_\mathrm{Regen}$. Zu starken Niederschlägen zählen Regenschauer deren Niederschlagsmenge $R_\mathrm{p}$ in $\text{mm/h}$ die durchschnittliche Niederschlagsmenge $\text{mm/h}$ eines Jahres zu $p=0.01\,\%$ der Zeit überschreiten.\cite{Satellite_Communications_Systems}
\end{itemize}

Die durch starke Niederschläge verursachte Dämpfung $L_\mathrm{Regen}$ ist das Produkt aus der spezifischen Dämpfung $\gamma_\mathrm{Regen}$ in $\text{dB/km}$ und der effektiven Pfadlänge $D_\mathrm{Regen}$ $(\text{km})$, welche die elektromagnetischen Wellen durch den Regen zurücklegen müssen.\cite{Satellite_Communications_Systems}
\begin{equation}
    L_\mathrm{Regen}=\gamma_\mathrm{Regen}\cdot D_\mathrm{Regen}
    \label{eq:Dämpfung-durch-Regen}
\end{equation}
Die spezifische Dämpfung $\gamma_\mathrm{Regen}$ ist abhängig von der Frequenz $f$ und der Niederschlagsmenge $R_\mathrm{\mathrm{0.01}}$, welche die durchschnittliche Niederschlagsmenge $\text{mm/h}$ eines Jahres zu $p=0.01\,\%$
überschreitet. Diese Niederschlagsmenge ist wichtig, da dann die spezifische Dämpfung $\gamma_\mathrm{Regen}$ am größten ist und der Downlink eventuell nicht mehr aufrecht erhalten werden kann. Damit steigt dann auch die Ausfallzeit.\cite{Satellite_Communications_Systems}\newline
Die Dämpfung für andere Niederschlagsrate $R_\mathrm{p}$, welche zu $0\,\%\leq p\leq5\,\%$ der Zeit den Jahresdurchschnitt überschreiten können aus der Dämpfung $L_\mathrm{Regen}$ für $R_\mathrm{0.01}$ gewonnen werden.\cite{Satellite_Communications_Systems}\newline
\begin{figure}[H]
    \centering
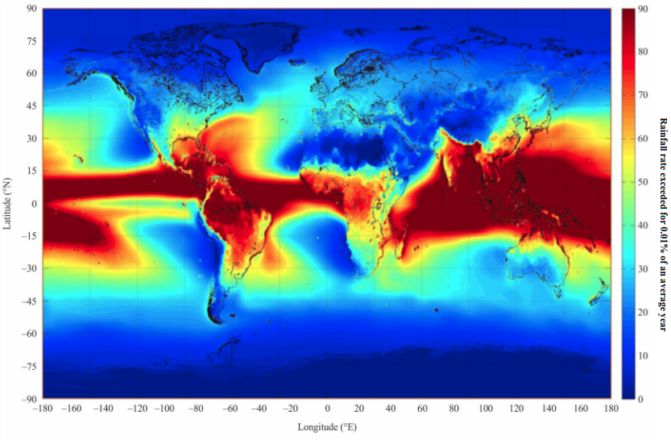
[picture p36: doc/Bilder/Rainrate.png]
    
    \caption{Karte zeigt die Niederschlagsmenge $(\text{mm/h})$ welche zu $p=0.01\,\%$ den jährlichen Durchschnitt überschreitet \cite{ITU-RP.837-8}}
    \label{fig:ITUR-Regenrate}
\end{figure}
Die Karte in Abbildung \ref{fig:ITUR-Regenrate} zeigt eine globale Übersicht über die Niederschlagsmenge $R_\mathrm{p}$ $(\text{mm/h)}$ welche zu $p=0.01\,\%$ den Jahresdurchschnitt in der jeweiligen Region überschreitet. Für den Norddeutschen Raum kann eine Niederschlagsrate $R_\mathrm{0.01}\approx35\,\text{mm/h}$ entnommen werden.\newline
Die durch starke Niederschläge verursachte Dämpfung $L_\mathrm{Regen}$ wird in mehreren Schritten bestimmt. Im ersten Schritt muss die effektive Regenhöhe $h_\mathrm{R}$ bestimmt werden. Dafür ist die Höhe $h_\mathrm{iso}$ der durchschnittliche $0\degree$ isothermische Schicht über dem Meeresspiegel wichtig. Die isothermische Höhe $h_\mathrm{iso}$ ist eine fiktive Grenze zwischen zwei Luftmassen. Oberhalb der Grenze weisen die Luftmassen eine negative Temperatur und unterhalb eine positive Temperatur auf. Sie kann aus einer Karte entnommen werden.\cite{isothermehöhe} Im Raum Europa beträgt diese $h_\mathrm{iso}=3\,\text{km}$.\cite{Satellite_Communications_Systems}
\begin{equation}
    h_\mathrm{R} = h_\mathrm{iso}+0.36\,\text{km}=3\,\text{km}+0.36\,\text{km}=3.36\,\text{km}
    \label{eq:effekitve-Regenhöhe}
\end{equation} 
Mithilfe der effektiven Regenhöhe $h_\mathrm{R}$ kann die Länge des Pfade unter den Regenwolken $D_\mathrm{S}$ bestimmt werden. Dafür ist auch der Elevationswinkel $\varepsilon$ der Antenne notwendig und die Höhe $h_\mathrm{Station}$der Bodenstation über dem Meeresspiegel. Das Gebäude der Hochschule Bremen am Flughafen, in welchem die Bodenstation errichtet wird, befindet sich $7\,\text{m ü.N.N}$\cite{höhebremen}. Die Höhe des Gebäudes kann mit $12\,\text{m}$ angenommen werden. Daraus ergibt sich für die Höhe der Station über dem Meeresspiegel $h_\mathrm{Station}=7\,\text{m}+12\text{m}=19\,\text{m}$. Für die Berechnung der Pfadlänge $D_\mathrm{S}$ wird der Elevationswinkel $\varepsilon$ der Antenne benötigt. Dieser wird in der Gleichung \ref{eq:Elevation-Antenne} mit $\varepsilon=27.36\degree$ angegeben.\cite{Satellite_Communications_Systems}
\begin{equation}
    D_\mathrm{S}=\frac{h_\mathrm{R}-h_\mathrm{Station}}{\sin(\epsilon)}=\frac{3.36\,\text{km}-0.019\,\text{km}}{\sin(27.36\degree)}=7.26\,\text{km}
    \label{eq:länge-des-schrägen-Pfads-unter-den-Wolken}
\end{equation}
Im nächsten Schritt wird die horizontale Projektion $D_\mathrm{HP}$ der Pfadlänge $D_\mathrm{S}$ bestimmt. Diese wird für die Bestimmung der spezifische Dämpfung $\gamma_\mathrm{Regen}$ benötigt.\cite{Satellite_Communications_Systems}
\begin{equation}
    D_\mathrm{HP}=D_\mathrm{S}\cdot\cos(\varepsilon)=7.26\,\text{km}\cdot{\cos(27.36\degree)}=6.44\,\text{km}
    \label{eq:horizontale-Projektion}
\end{equation}
Die spezifische Dämpfung $\gamma_\mathrm{Regen}$ ist von der bestimmten Niederschlagsrate 
$R_\mathrm{0.01}\approx35\,\frac{\text{mm}}{\text{h}}$ abhängig.\cite{Satellite_Communications_Systems}
\begin{equation}
    \gamma_\mathrm{Regen}=k\cdot(R_\mathrm{0.01})^\alpha
\end{equation}
Dabei sind $k$ und $\alpha$ frequenzabhängige Koeffizienten, welche mit\cite{Satellite_Communications_Systems} 
\begin{equation}
    k=\frac{k_\mathrm{H}+k_\mathrm{V}+(k_\mathrm{H}-k_\mathrm{V})\cos^2{\epsilon}\cdot\cos{2\tau}}{2}
\end{equation}
beziehungsweise
\begin{equation} \alpha=\frac{k_\mathrm{H}\cdot\alpha_\mathrm{H}+k_\mathrm{V}\cdot\alpha_\mathrm{V}+(k_\mathrm{H}\cdot\alpha_\mathrm{H}-k_\mathrm{V}\cdot\alpha_\mathrm{V})\cos^2{\epsilon}\cdot\cos{2\tau}}{2k}
\end{equation}
bestimmt werden können. Die Werte für $k_\mathrm{H}$, $k_\mathrm{V}$, $\alpha_\mathrm{H}$ und $\alpha_\mathrm{V}$ sind von der Frequenz des Downlinks abhängig und können aus einer Tabelle in ITU-R P.838 entnommen werden. Für $f=10\,\text{GHz}$ gilt\cite{ITU-RP.838-3}:
\begin{itemize}
    \item $k_\mathrm{H}=0.01217 $
    \item $k_\mathrm{V}=0.01129 $
    \item $\alpha_\mathrm{H}=1.2571 $
    \item $\alpha_\mathrm{V}=1.2156 $
\end{itemize}
Die weitere Berechnung der spezifischen Dämpfung $\gamma_\mathrm{Regen}$ erfolgt in Python. Das Pythonskript ist im Github-Repository und im Anhang \ref{lst:Dämpfung-durch-Regen-python} hinterlegt. Für die spezifischen Dämpfung $\gamma_\mathrm{Regen\,0.01}$ ergibt sich für eine Niederschlagsmenge $R_\mathrm{0.01}=35\,\text{mm/h}$ ein Wert von 
\begin{equation*}
    \gamma_\mathrm{Regen}=1.03\,\frac{\text{dB}}{\text{km}}
\end{equation*}
Für die effektive Pfadlänge ergibt sich ein Länge von
\begin{equation*}
    D_\mathrm{Regen}= 8.59\,\text{km}
\end{equation*}
Die mit Gleichung \ref{eq:Dämpfung-durch-Regen} bestimmte Dämpfung $L_\mathrm{Regen}$ durch Niederschläge, welche zu $p=0.01\,\%$ den Jahresdurchschnitt überschreitet, beträgt damit 
\begin{equation}
    L_\mathrm{Regen}=\gamma_\mathrm{Regen}\cdot D_\mathrm{Regen}=1.03\,\frac{\text{dB}}{\text{km}}\cdot8.59\,\text{km}=8.86\,\text{dB}
    \label{eq:bestimmte-Regendämpfung}
\end{equation}
Die Dämpfung $L_\mathrm{Regen}$ gilt für eine Niederschlagsmenge $R_\mathrm{0.01}=35\,\text{mm/h}$. Diese Niederschlagsmenge überschreitet im Bereich Norddeutschland den Jahresdurchschnitt zu $p=0.01\,\%$ der Zeit. Diese Dämpfung ist für die Wetterbedingung Regen relevant und bietet einen guten Schätzwert für die Dämpfung, welche bei stärkeren Regenschauern auftritt.\newline
\begin{figure}[H]
    \centering
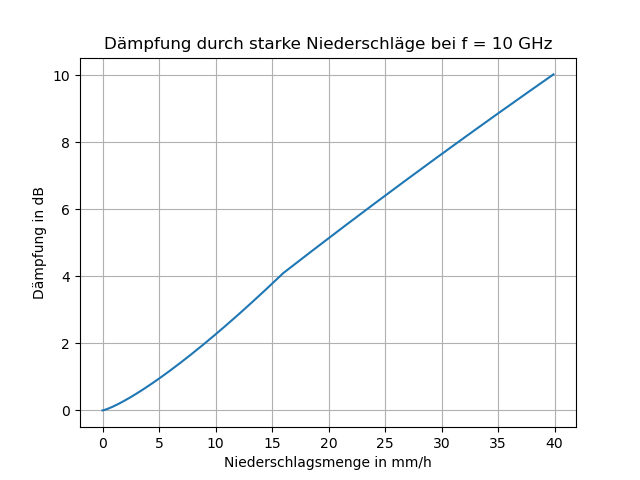
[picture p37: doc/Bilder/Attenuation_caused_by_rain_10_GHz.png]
    
    \caption{Graph zeigt die Dämpfung $L_\mathrm{Regen}$ in Abhängigkeit von der Niederschlagsrate $R_\mathrm{0.01}$ in $\text{mm/h}$ für die Frequenz $f=10\,\text{GHz}$ }
    \label{RegenDämpdungGraph}
\end{figure}
Die Abbildung \ref{RegenDämpdungGraph} zeigt die Dämpfung $L_\mathrm{Regen}$ in Abhängigkeit von der Niederschlagsrate für die Frequenz $f=10\,\text{GHz}$. Wichtig ist, dass die Niederschlagsraten $R_\mathrm{p}$ in $\text{mm/h}$ dabei die Niederschlagsraten sind, welche den Jahresdurchschnitt zu $p = 0.01\,\%$ der Zeit überschreiten.\newline
Wie bereits erwähnt können die geschätzte Dämpfungen für Niederschlagsmengen $R_\mathrm{p}$, welche den Jahresdurchschnitt zu  $0\,\%\leq p\leq5\,\%$ der Zeit überschreiten, aus der Dämpfung $L_\mathrm{Regen}$ bestimmt werden.\cite{Satellite_Communications_Systems}
\begin{equation}
    L_\mathrm{Regen\,p}=L_\mathrm{Regen}\cdot\left(\frac{p}{0.01}\right)^{-(0.655+0.033\cdot\ln(p)-0.045\ln(L_\mathrm{Regen})-\beta(1-p)\cdot\sin(\varepsilon)}
    \label{eq:Dämpfung-durch-Regen-für-0-bis-5}
\end{equation}
Der Koeffizient $\beta$ ist abhängig von der Wahrscheinlichkeit $p$, dem Längengrad $long_\mathrm{BS}$, sowie dem Elevationswinkel $\varepsilon$ der Antenne.\cite{Satellite_Communications_Systems}
\begin{equation}
 \beta = \begin{cases} 
  0 & \text{,}\, p \geq1\,\% \,\text{oder}\,|long_\mathrm{BS}|\geq36\degree \\ 
  -0.005(|long_\mathrm{BS}|-36) & \text{,}\, p <1\,\% \,\&\,|long_\mathrm{BS}|<36\degree\,\&\,\epsilon\geq27\degree \\ 
  -0.005(|long_\mathrm{BS}|-36)+1.8-4.25\cdot\sin(\varepsilon) & \text{,}\,\text{sonst}
  \label{eq:beta}
\end{cases} 
\end{equation}
Zur Bestimmung der Dämpfung $L_\mathrm{leichterRegen}$ für Niederschlagsmenge $R_\mathrm{p}$, welche zu $p=5\,\%$ der Zeit den Jahresdurchschnitt $(\text{mm/h})$ überschreiten, werden die Koordinaten der Bodenstation benötigt. Diese können aus der Karte in Abbildung \ref{fig:Koordinaten der Bodenstation} gewonnen werden. Die Bodenstation befindet sich an den Koordinaten $53.055\degree, 8.78\degree$, womit $long_\mathrm{BS} =8.78\degree$ ist. Der Elevationswinkel der Antenne wird in Gleichung \ref{eq:Elevation-Antenne} bestimmt und beträgt $e=27.88\degree$.\newline
Die Dämpfung $L_\mathrm{leichterRegen}$ für Niederschlagsmenge, welche zu $p=5\,\%$ der Zeit den Jahresdurchschnitt $(\text{mm/h})$ überschreiten, wird mithilfe der Gleichungen \ref{eq:Dämpfung-durch-Regen-für-0-bis-5} und \ref{eq:beta} in Python bestimmt.
\begin{equation}
    L_\mathrm{leichterRegen}=0.2\,\text{dB}
    \label{eq:Dämpfung-durch-leichten-Regen}
\end{equation}
Die Dämpfung $L_\mathrm{leichterRegen}$ aus Gleichung \ref{eq:Dämpfung-durch-leichten-Regen} ist deutlich geringer als die Dämpfung $L_\mathrm{Regen}$ in Gleichung \ref{eq:bestimmte-Regendämpfung}, da in $L_\mathrm{leichterRegen}$ auch niedrigere Regenrate mitberücksichtigt. Die Dämpfung $L_\mathrm{leichterRegen}$ bietet einen bessere Schätzung für die durchschnittliche Dämpfung bei normalen Regenschauern, während die die Dämpfung $L_\mathrm{Regen}$ eine gute Schätzung für starke Regenschauer ist.

\subsubsection*{Dämpfung durch Gase und Dämpfe in der Atmosphäre}
Neben Regen und Schnee haben auch Gase, Dämpfe und andere Partikel in der Atmosphäre eine dämpfende Wirkung auf die elektromagnetischen Wellen. In den Frequenzen $f\leq1000\,\text{GHz}$ tragen hauptsächlich Sauerstoff und Wasserdampf, welche in der Ionosphäre ionisiert werden, zur Dämpfung $L_\mathrm{Gas}$ bei.\cite{ITU-RP.676-13}\newline
Durch die Addition der einzelnen Spektrallinien von Wasserdampf und Sauerstoff kann, in Kombination mit einem kleinen Faktor, die spezifische Dämpfung $\gamma_\mathrm{Gas}$ präzise für verschiedene Drücke, Temperatur und Luftfeuchtigkeit bestimmt werden.\cite{ITU-RP.676-13}\cite{Satellite_Communications_Systems}
\begin{equation}
    \gamma_\mathrm{Gas}=\gamma_\mathrm{Oxygen}+\gamma_\mathrm{Waterwapor}=0.1820\cdot f(N^{\glqq}_\mathrm{0xygen}(f)+N^{\glqq}_\mathrm{Waterwapor}(f))
\end{equation}
Dabei wird die Frequenz $f$ in GHz angegeben und die $N^"_\mathrm{0xygen}(f)$und$N^"_\mathrm{Waterwapor}(f)$ sind von der Frequenzabhängige Funktionen. Ihre Werte können für eine bestimmte Frequenz in einem Graphen nachgeschaut werden.\cite{ITU-RP.676-13}
Für eine Standard Atmosphäre, bedeutet Druck am Boden $p=1013\,\text{hPa}$, Temperatur am Boden $T=19\degree\text{C}$ und Wasserdampfkonzentration am Boden $c=7.5\,\frac{\text{g}}{\text{m}³}$, lässt sich die Dämpfung $L_\mathrm{Gas}$ in Abhängigkeit der Frequenz $f$ für verschiedene Elevationswinkel $\epsilon\geq10\degree$ in einem Graphen darstellen.\cite{Satellite_Communications_Systems} 
\begin{figure}[H]
    \centering
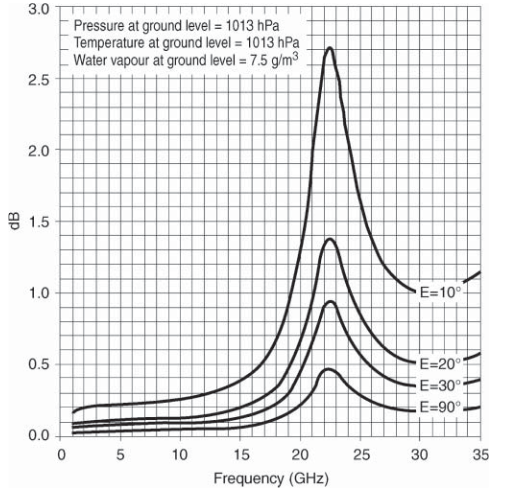
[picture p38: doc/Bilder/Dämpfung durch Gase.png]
    
    \caption{Die Dämpfung durch Gase und Dämpfe $L_\mathrm{Gas}$ in Abhängigkeit der Frequenz für verschiedene Elevationswinkel $\epsilon$.\cite{Satellite_Communications_Systems}}
    \label{DämpfungdurchGaseGraph}
\end{figure}
Die Abbildung \ref{DämpfungdurchGaseGraph} zeigt die Dämpfung durch Gase und Dämpfe $L_\mathrm{Gas}$ in der Atmosphäre in Abhängigkeit von der Frequenz $f$ für verschiedene Elevationswinkel $\epsilon$ der Antenne.\newline
Für Frequenzen $f\leq15\,\text{GHz}$ ist die Dämpfung eher gering. Die maximale Dämpfung im dargestellten Frequenzbereich liegt bei $L_\mathrm{Gas}=2,7\,\text{dB}$ bei $f=22.24\,\text{GHz}$. Die Dämpfung an dieser Frequenz folgt aus dem Absorptionsband von Wasserdampf.\cite{Satellite_Communications_Systems}\newline
Die Mittenfrequenz $f_\mathrm{center}$ des Schmalbandtransponders auf Es'Hail-2 (QO-100) liegt bei $f_\mathrm{center}=10489.750\,\text{MHz}\approx 10.5\,\text{GHz}$. Der Elevationswinkel der Antenne an der Bodenstation ist in Gleichung \ref{eq:Elevation-Antenne} mit $\epsilon=27.36\degree\approx30\degree$ angeben. Aus dem Graph kann für die angegeben Werte eine Dämpfung von $L_\mathrm{Gas}\approx0.1\,\text{dB}$ entnommen werden.

\subsubsection*{Verluste durch nicht optimale Ausrichtung der Antennen}
Die Antenne des Schmalbandtransponders auf Es’Hail‑2 (QO-100) und die Antenne der Bodenstation am IAT sind nicht ideal aufeinander ausgerichtet, wie in Abbildung\ref{fig:Ausrichtungsverluste} dargestellt. 
\begin{figure}[H]
    \centering
    \includesvg[width=0.5\linewidth]{Bilder/Ausrichtunsgverluste}
    \caption{Veranschaulichung der Ausrichtungsverluste. Die optimale Ausrichtung ist in schwarz dargestellt, die tatsächliche Ausrichtung in rot.}
    \label{fig:Ausrichtungsverluste}
\end{figure}
Die Antenne des Transponders ist senkrecht auf den Äquator ausgerichtet, um eine möglichst gleichmäßige Abdeckung großer Teile der Erde zu gewährleisten. Dadurch ergibt sich jedoch ein Gewinnverlust $ G_\mathrm{T} $ gegenüber dem maximal möglichen Gewinn $ G_\mathrm{T,max} $ auf der Seite des Senders. Dieser Verlust im Gewinn führt wiederum zu einer Reduzierung der empfangenen Leistung $ P_\mathrm{R} $ im Vergleich zur maximal erreichbaren Empfangsleistung $ P_\mathrm{R,max} $. Diese Verluste werden auch Ausrichtungsverluste genannt (engl. Depointing Losses).\cite{Satellite_Communications_Systems}\newline
Die Ausrichtungsverluste lassen sich auf der Seite des Senders mit\cite{Satellite_Communications_Systems}
\begin{equation}
    L_\mathrm{\theta T}=12\cdot \left(\frac{\theta_\mathrm{T}}{\theta_\mathrm{3dB}}\right)^2
    \label{eq:Berechnung-Fehlausrichtung-Sender}
\end{equation}
beziehungsweise auf der Empfängerseite mit\cite{Satellite_Communications_Systems}
\begin{equation}
    L_\mathrm{\theta R}=12\cdot \left(\frac{\theta_\mathrm{R}}{\theta_\mathrm{3dB}}\right)^2
    \label{eq:Berechnung-Fehlausrichtung-Empfänger}
\end{equation}
bestimmen. Dabei sind $\theta_\mathrm{T}$,beziehungsweise $\theta_\mathrm{R}$ der Winkel der Fehlausrichtung und $\theta_\mathrm{3dB}$ die 3dB-Strahlbreite der Antenne des Senders.\cite{Satellite_Communications_Systems}\newline
Die $3\,\text{dB-Strahlbreite}$ der Hornantenne auf Es'Hail-2 (QO-100) beträgt $\theta_\mathrm{3dB}=17.4\degree$.\cite{EsHail2} Zur Bestimmung der Ausrichtungsverluste auf der Seite des Senders $L_\mathrm{\theta T}$ muss zunächst der Winkel der Fehlausrichtung $\theta_\mathrm{T}$ bestimmt werden. Die Hornantenne des Schmalbandtransponders auf Es'Hail-2 (QO-100) ist für gleichmäßige Abdeckung über die Erde auf den Äquator gerichtet. Die Ausrichtung von Es'Hail-2 (QO-100) und der Bodenstation sind in Abbildung \ref{eq:EntfernungEsHail2} dargestellt. Dabei entspricht der Winkel der Fehlausrichtung $\theta_\mathrm{T}$ dem Winkel $\beta$ zwischen dem Abstand $r+r_\mathrm{02}$ von Es'Hail-2 (QO-100) zur Höhe der Bodenstation über den Äquator und dem Abstand zur Bodenstation am IAT $D_\mathrm{SAT}$.
\begin{equation}
    \theta_\mathrm{T}=\beta= \arccos\left(\frac{r+r_\mathrm{02}}{D_\mathrm{SAT}}\right)=\arccos\left(\frac{35790\,\text{km}+2548.22\,\text{km}}{38676\,\text{km}}\right)=7.58\degree
    \label{eq:Winkel-der-Fehlausrichtung-Sender}
\end{equation}
Damit beträgt der Ausrichtungsverlust auf der Seite des Senders
\begin{equation}
     L_\mathrm{\theta T}=12\cdot \left(\frac{\theta_\mathrm{T}}{\theta_\mathrm{3dB}}\right)^2=12\cdot\left(\frac{7.58\degree}{17.4\degree}\right)^2=5.23\,\text{dB}
     \label{eq:Senderseitige-Fehlausrichtung}
\end{equation}
Auf der Empfängerseite kann mit einem maximalen Winkel der Fehlausrichtung von $\theta_R=1\degree$ ausgegangen werden. So ergibt sich ein Ausrichtungsverlust auf der Seite des Empfängers von
\begin{equation}
     L_\mathrm{\theta R}=12\cdot \left(\frac{\theta_\mathrm{R}}{\theta_\mathrm{3dB}}\right)^2=12\cdot\left(\frac{1\degree}{17.4\degree}\right)^2=0.69\,\text{dB}
     \label{eq:Empfängerseitige-Fehlausrichtung}
\end{equation}

\subsubsection*{Weitere Einflüsse und Gesamtdämpfung}
Weiterhin kann auch die Dämpfung durch Regen- und Eiswolken, sowie Nebel berücksichtigt werden. Die spezifische Dämpfung $\gamma_\mathrm{REN}$ in $\text{dB/km}$ wird folgend bestimmt.\cite{Satellite_Communications_Systems}
\begin{equation}
    \gamma_\mathrm{REN}=K\cdot M
\end{equation}
Wobei $K=1.2\cdot10^{-3}\cdot f^{1.9}\,\text{in}\frac{\text{dB/km}}{\text{g/}\text{m}^3}$ ein approximierter Wert ist. Die Frequenz $f$ wird in $\text{GHz}$ angeben. Die Variable $M$ in $\text{g/}\text{m}^3$ ist die Wasserkonzentration in den Wolken oder Nebel.\cite{Satellite_Communications_Systems}\newline
Die Dämpfung durch Regen- und Eiswolken ist im Vergleich zu der Dämpfung durch Regen sehr gering $L_\mathrm{Wolken}\approx0.2\,\text{dB}$.\cite{Satellite_Communications_Systems}\newline
Für dichten Nebel, welcher im Raum Bremen schon häufiger auftritt, kann von einer Wasserkonzentration $M=0.5\,\text{g/}\text{m}^3$ ausgegangen werden\cite{Satellite_Communications_Systems}. Damit ergibt sich für eine Frequenz $f\approx10.5\,\text{GHz}$ eine spezifische Dämpfung $\gamma_\mathrm{REN}$ von
\begin{equation*}
    \gamma_\mathrm{REN}=K\cdot M=1.2\cdot 10^{-3}\cdot (10.5\,\text{GHz})^{1.9}\frac{\text{dB/km}}{\text{g/}\text{m}^3}\cdot0.5\,\text{g/}\text{m}^3=0.052\,\text{dB/km}
\end{equation*}
Was zusammen mit der in Gleichung effektiven Pfadlängen $D_\mathrm{Regen}=8.59\,\text{km}$ zu einer Dämpfung
\begin{equation}
     L_\mathrm{Nebel}=\gamma_\mathrm{REN}\cdot D_\mathrm{Regen}=0.052\,\text{dB/km}\cdot 8.59\,\text{km}=0.447\,\text{dB}
\end{equation}
führt. Die einzelnen in der Atmosphäre bestimmten Dämpfungen $L_\mathrm{Regen}$,$L_\mathrm{leichterRegen}$, $L_\mathrm{Gas}$, $L_\mathrm{Wolken}$ und $L_\mathrm{Nebel}$ können für die jeweilige Wetterbedienung zu einer gesamten Dämpfung $L_\mathrm{At}$ zusammengefasst werden.\newline
Bei der Wetterbedingung klarer Himmel (engl. clear Sky) kann die Dämpfung durch Regen und Wolken vernachlässigt werden. Die einzigen auftretenden Dämpfungen in der Atmosphäre entstehen durch Gase und Dämpfe in der Atmosphäre und gegebenenfalls durch Nebel auf dem Boden.\newline
\begin{equation}
    L_\mathrm{ATklarerHimmel}=L_\mathrm{Gas,\,dB}+L_\mathrm{Nebel,\,dB}=0.1\,\text{dB}+0.447\,\text{dB}=0.547\,\text{dB}
    \label{eq:Dämpfung-in-der-Atmosphäre-klarer-Himmel}
\end{equation}
In der Bedingung leichter Regen wird die Dämpfung durch Niederschlagsraten $R_\mathrm{p}$ in $\text{mm/h}$ berücksichtigt, welche zu $p=5\,\%$ der Zeit den Jahresdurchschnitt $(\text{mm/h})$ überschreiten. Ebenfalls werden auch die Verluste durch Gase und Dämpfe in der Atmosphäre, durch Wolken und gegebenenfalls durch Nebel berücksichtigt.
\begin{equation}
\begin{split}
    L_\mathrm{ATleichterRegen} & =L_\mathrm{leichterRegen\,dB}+L_\mathrm{Gas,\,dB}+L_\mathrm{Wolken,\,dB}+L_\mathrm{Nebel,\,dB}\\
    & = 0.2\,\text{dB}+0.1\,\text{dB}+0.2\,\text{dB}+0.447\,\text{dB} = 0.947\,\text{dB}
\end{split} 
\label{eq:Dämpfung-in-der-Atmosphäre-leichter-Regen}
\end{equation}
In der Bedingung Regen dominiert die Dämpfung durch starke Niederschläge. Es wird die Dämpfung durch Niederschlagsraten $R_\mathrm{p}$ in $\text{mm/h}$ berücksichtigt, welche den Jahresdurchschnitt $(\text{mm/h})$ zu $p=0.01\,\%$ der Zeit überschreiten. Auch werden wieder die Dämpfungen durch Gase und Dämpfe in der Atmosphäre, durch die Wolken und gegebenenfalls auch wieder durch Nebel berücksichtigt.
\begin{equation}
\begin{split}
    L_\mathrm{ATRegen} & =L_\mathrm{Regen,\,dB}+L_\mathrm{Gas,\,dB}+L_\mathrm{Wolken,\,dB}+L_\mathrm{Nebel,\,dB}\\
    & = 8.86\,\text{dB}+0.1\,\text{dB}+0.2\,\text{dB}+0.447\,\text{dB} = 9.61\,\text{dB}
\end{split}
\label{eq:Dämpfung-in-der-Atmosphäre-Regen}
\end{equation}

\subsection{Empfänger - Bodenstation am IAT}
Um die Signale des Schmalbandtransponders von Es'Hail-2 (QO-100) empfangen und weiterverarbeiten zu können, benötigt es ein geeignetes Empfangssystem. Das Empfangssystem muss mehrere Voraussetzung erfüllen.
\begin{enumerate}
    \item Das Empfangssystem sollte technisch dazu fähig sein den Downlink von Es'Hail-2 (QO-100) im X-Band empfangen und verarbeiten zu können.
    \item Das Empfangssystem sollte eine großen Dynamikbereich besitzen. Mit einem hohen Dynamikbereich kann das Empfangssystem Signale mit sehr kleinen Pegel in der Nähe des Rauschflurs, als auch Signale mit sehr großem Pegel ohne zu übersteuern verarbeiten.
    \item Die Bandbreite des Empfangssystem sollte mindestens $B_\mathrm{min}=2.7\,\text{kHz}$ breit sein, um die maximal zulässige Einzelsignalbandbreite gemäß des Bandplans vom Schmalbandtransponders auf Es'Hail-2 (Q0-100) empfangen zu können.
    \item Das Empfangssystem sollte ein möglichst hohes $SNR$ an seinem Eingang und Ausgang aufweisen. So können Fehler in der Demodulation der Signale von Es'Hail-2 (QO-100) gering gehalten werden. Ein hohes $SNR$ am Ausgang erfordert einen möglichst rauscharmen RF-Bereich des Empfangssystem. Daher sollte die möglichen Rauschquellen im RF-Bereich des Empfangssystem und die Rauschzahl $F$ so gering wie möglich gehalten werden.
    \item Gleichzeitig muss das Empfangssystem eine gewissen Verstärkung $G_\mathrm{sys}$ aufweisen. Mit einer passenden Verstärkung $G_\mathrm{sys}$ kann der schwache Pegel der Signale von Es'Hail-2 (QO-100) so angehoben werden, dass es vom SDR optimal verarbeiten werden kann.
    \item Das Empfangssystem sollte auch bei leichten Regenschauern, spricht Niederschlagsmengen $\text{mm/h}$, welche zu $5\,\%$ der Zeit die Durchschnittsniederschlagsmenge $\text{mm/h}$ eines Jahres überschreiten, den Downlink von Es'Hail-2 (QO-100) aufrechterhalten können.
    \item Die Verluste im RF-Fronted $L_\mathrm{sys}$ des Empfangssytems sollte so gering wie möglich gehalten werden. 
    \item Die neu zu beschaffenden Komponenten sollte mit den vorhandenen Komponenten der Bodenstation vom IAT kompatibel sein und den Standards in der Telekommunikation entsprechen.
    \item Für das Software Defined Radio (SDR) muss eine geeignete SDR-Software mithilfe von GNU-Radio Companion erstellt werden.
\end{enumerate}
Damit das Empfangssystem den Downlink im X-Band empfangen kann, braucht es hierfür eine geeignete Antenne. Am Flughafen Standort der Hochschule Bremen ist bereits eine Parabolantenne, wie sie für Satellitenfernsehen üblich ist, vorhanden. Diese müsste hinsichtlich ihrer Eignung für den Empfang des Downlinks von Es'Hail-2 (QO-100) im X-Band überprüft werden.\newline
Die Größe des Dynamikbereich wird vom ADC des SDR bestimmt. In der Bodenstation vorhanden ist ein USRP X310 SDR von National Instruments (NI). Auch wird die maximale Bandbreite $B_\mathrm{max}$ mit vom SDR bestimmt. Das SDR muss ebenfalls auf die Eignung, Hardware und Softwareunterstützung, für den Einsatz im Empfangssystem für den Downlink von Es'Hail-2 (QO-100) überprüft werden.\newline
Mithilfe der Gleichungen \ref{eq:Gesamtrauschzahl-Kaskade} und \ref{eq:Gesamt-äquivalente-Rauschtemperatur-Kaskade} lassen sich mehrere Vorschriften und Bedienungen für den Aufbau der Empfangskette herleiten.
\begin{enumerate}
    \item Das erste Zweitor nach der Antenne hat den größten Einfluss auf die Gesamtrauschzahl $F_\mathrm{sys}$ der Empfangskette. Daher sollte das erste Zweitor ein niedriges Eigenrauschen und damit verbundene niedrige Rauschzahl $F_\mathrm{1}$, sowie eine hohe Verstärkung $G_\mathrm{1}$ besitzen, da die folgenden Zweitore mit dem Gewinn $G_\mathrm{1}$ des ersten Zweitores gewichtet werden.\cite{HEUERMANN_2018}
    \item Die folgenden Zweitore haben bei einem entsprechend großen Gewinn $G_\mathrm{1}$ nur noch geringe Auswirkung auf die Gesamtrauschzahl $F_\mathrm{sys}$ oder der äquivalenten Rauschtemperatur des Gesamtsystems $T_\mathrm{e,sys}$.\cite{HEUERMANN_2018}
    \item Wie in Gleichung \ref{eq:Rauschzahl-passives-Zweitor} gezeigt, ist der Verlust $L$ passiver Zweitore gleich ihrer Rauschzahl $F$. Daher sollten Koaxialleitung mit niedrigen Verlust verwendet und Lange Wege reduziert werden. Auch sollte auf Dämpfungsglieder verzichtet werden.
    \item Da jedes Zweitor zwangsläufig das $SNR$ verschlechtert, sollte die Anzahl der Zweitore im RF-Frontend auf das mögliche Minimum reduziert werden.
\end{enumerate}
Mithilfe dieser Vorschriften und Bedienungen kann ein geeigneter RF-Bereich der Empfangssystems geplant werden.
\begin{figure}[H]
    \centering
    \includesvg[width=0.75\linewidth]{Bilder/Empfangskette}
    \caption{Blockschaltbild vom RF-Bereich des Empfangssystems}
    \label{fig:geplante-Empfangskette}
\end{figure}
In der Abbildung \ref{fig:geplante-Empfangskette} ist ein Blockschaltbild vom geplanten RF-Bereich des Empfangssystems zusehen. Als erstes Zweitor wird eine Koaxialleitung mit sehr geringen Verlusten eingesetzt. Die Koaxialleitung ist notwendig, da das zweite Zweitor, ein LNC, nicht direkt an die Antenne angeschlossen werden kann. Der LNC ist rauscharmer Mischer mit integrierten Verstärker. Montiert wird der LNC in der Nähe der Antenne, damit die Länge der ersten Koaxialleitung gering gehalten werden kann. Das dritte Zweitor ist wieder eine Koaxialleitung, welche die lange Strecke vom LNC auf dem Dach bis zum Serverschrank, wo sich die Fernspeiseweiche befindet, überbrückt wird. Über die Fernspeiseweiche wird der LNC mit der nötigen Betriebsspannung $V_\mathrm{cc}$ und ggf. einem $10\,\text{MHz}$ Referenzsignal versorgt. Das fünfte Zweitor ist ebenfalls wieder eine Koaxialleitung, mit welcher die Fernspeiseweiche mit dem Patchfeld verbunden wird. Über das Patchfeld, welches das sechste Zweitor ist, kann eine einfache Verkablung im Serverschrank vorgenommen werden. Vom Patchfeld gibt es eine weitere Koaxialleitung zur Schaltmatrix (engl. RF-Switch). Die Schaltmatrix hat mehrere Eingänge und kann einen beliebigen Eingang auf seinen Ausgang durchschalten. So könnten mit einem SDR mehrere verschiedene Empfangssysteme betrieben werden. Vom Ausgang der Schaltmatrix führt anschließend noch eine Koaxialleitung zum SDR, welches das letzte Zweitor im RF-Bereich vom Empfangssystem ist. Mit dem SDR werden die Datensignale von Es'Hail-2 (Q0-100) in brauchbare Daten und Informationen umgewandelt und anschließend an einen PC weitergegeben.\newline
Als Systemimpedanz werden $50\,\Omega$ gewählt. Alle verwendeten Komponenten im RF-Frontend sind auf dieses Systemimpedanz angepasst. Die $50\,\Omega$ Impedanz hat sich als Standard in der Telekommunikationstechnik etabliert. Begründet werden kann das mit der Impedanz von Koaxialleitungen.\cite{Altium-Impedanz}
\begin{figure}[H]
    \centering
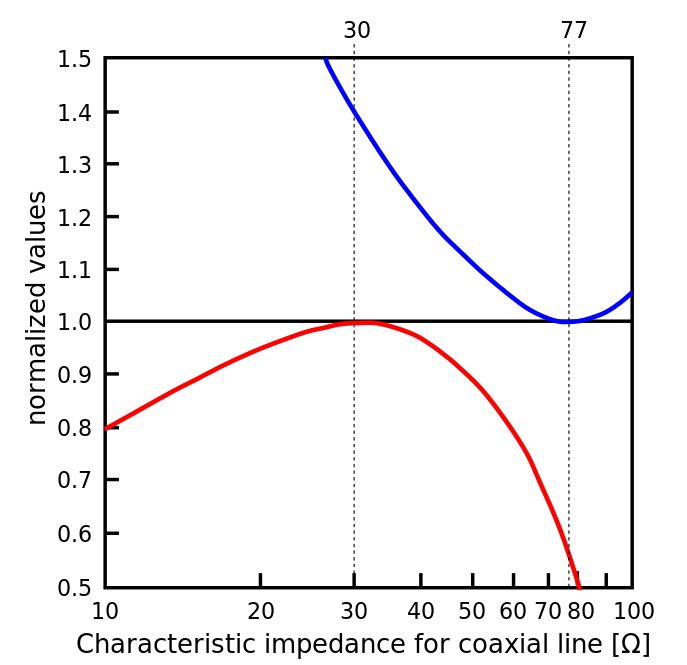
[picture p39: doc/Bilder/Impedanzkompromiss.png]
    
    \caption{Darstellung der Verluste (blau) und der maximalen Leistungsübertragung (rot)  von luftgefüllten Koaxialleitungen ($\varepsilon_\mathrm{r}=1$) über die Impedanz\cite{Altium-Impedanz}}
    \label{fig:Kompromiss-Impedanz}
\end{figure}
Eine Koaxialleitung soll drei Kriterien erfüllen. Sie soll möglichst geringe Verluste aufweisen. Das Dielektrikum soll dabei hohen Spannungen und damit verbunden hohen Feldstärke standhalten und die Koaxialleitung soll in der Lage sein, hohe Leistungen zu übertragen.\cite{Altium-Impedanz}\newline 
In der Grafik \ref{fig:Kompromiss-Impedanz} sind zwei Graphen zu sehen. Dargestellt sind die normierten Verluste (blau) und die normierte maximale übertragbare Leistung (rot) von luftgefüllten Koaxialleitungen über deren Impedanz. Die höchste maximal übertragbare Leistung wird bei einer Impedanz von $30\,\Omega$ erreicht. Jedoch sind dann auch die Verluste vergleichsweise hoch. Am niedrigsten sind die Verluste bei einer Impedanz von $77\,\Omega$, jedoch ist hier die maximale übertragbare Leistung eher gering. Mit dieser Gegebenheit kann möglicherweise die $75\,\Omega$ Impedanz im Rundfunkbereich erklärt werden. Im TE10-Modus erreicht das elektrische Feld sein Maximum bei einer Impedanz von $60\,\Omega$.\cite{Altium-Impedanz}\newline
Die $50\,\Omega$ Impedanz ist der beste Kompromiss aus minimaler Dämpfung, maximaler Leistungsübertragung und maximaler Feldstärke. Aus diesem Grund hat sie sich als Standard Referenz Impedanz etabliert.\cite{Altium-Impedanz}

\subsubsection*{Antenne und Antennenfeed}
Bei der verwendeten Antenne handelt es sich um eine Parabolantenne, wie sie z.B. für Satellitenfernsehen üblich ist. Die Parabolantenne gehört zu der Gruppe der Reflektorantennen, welche eine Kombination aus einem Reflektor und einem Antennenfeed sind.\cite{Balanis_2005}\newline
Der Reflektor hat die Aufgabe, einfallende elektromagnetische Wellen in eine bestimmte Richtung zu reflektieren und damit die abgestrahlte Energie gezielt zu bündeln. Anders als bei flachen Reflektoren werden bei Parabolspiegeln die auftretenden EM-Wellen durch die parabolische Krümmung des Reflektors in einem gemeinsamen Punkt fokussiert. Dieser Punkt wird Brennpunkt (engl. focal point) genannt.\cite{Balanis_2005}\newline
Im Brennpunkt der Parabolantenne befindet sich der Antennenfeed. Der Antennenfeed ist nichts anderes als eine gewöhnliche Antenne, welche die fokussierten EM-Wellen empfängt oder in Richtung des Reflektors abstrahlt. Hier wird eine Hornantenne als Antennenfeed verwendet. Diese bietet gegenüber einer Dipolantenne einen höheren Richtfaktor $D$ und damit verbunden auch einen höheren Gewinn $G$.\cite{Balanis_2005}\newline
An der Hochschule ist bereits eine Parabolantenne vorhanden. Diese ist im Zuge eines Sturmes umgeknickt und soll nun wieder verwendet werden. 
\begin{figure}[H]
    \centering
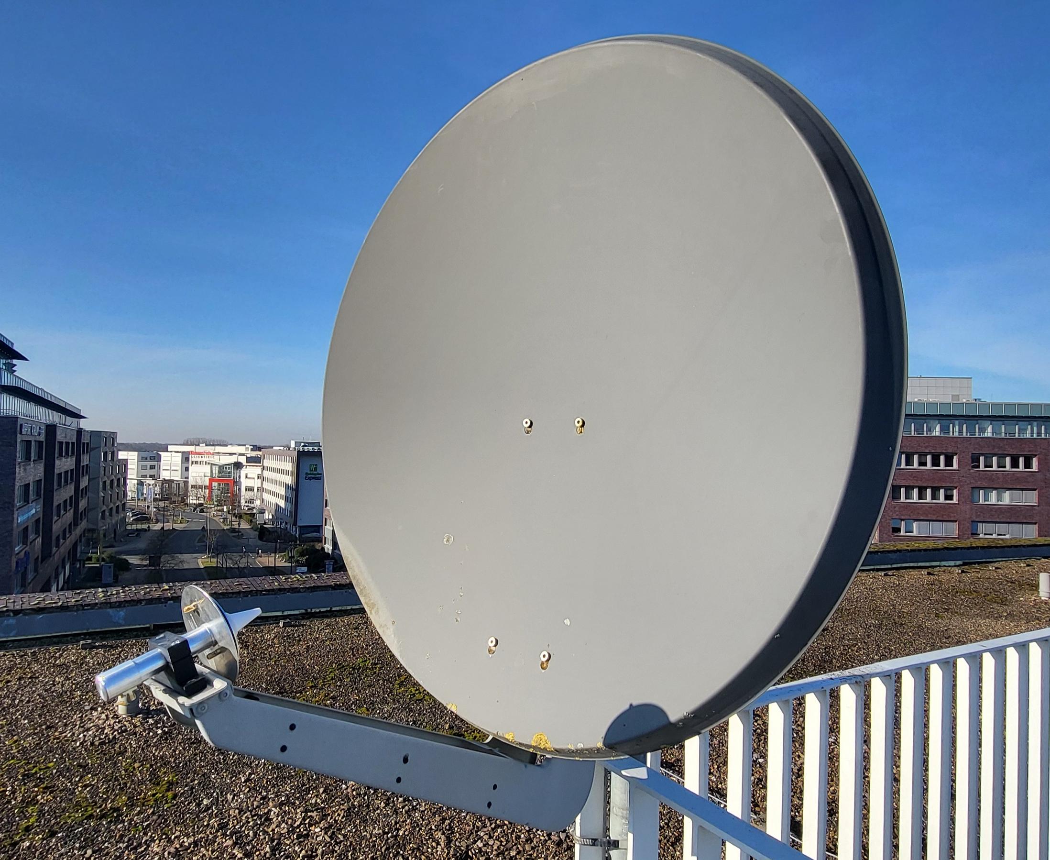
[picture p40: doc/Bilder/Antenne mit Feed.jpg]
    
    \caption{Vorhandene Parabolantenne mit neuem Antennenfeed.}
    \label{fig:vorhandene-Parabolantenne}
\end{figure}

Die Bild \ref{fig:vorhandene-Parabolantenne} zeigt die auf dem Dach der Hochschule vorhandene Parabolantenne. Beim Parabolspiegel handelt es sich um eine Kathrein CAS 90 HD ohne Logo. Der Parabolspiegel hat einen Durchmesser von $d_\mathrm{Antenne}=0.9\,\text{m}$ und ist für den Betrieb im X-Band und unteres Ku-Band, genauer zwischen $10.7\,\text{GHz}$ und $12.75\,\text{GHz}$, vorgesehen.\cite{KathreinCAS90HD}\newline
Aus dem Datenblatt lässt sich für den maximalen Gewinn $G_\mathrm{R,max}$ folgende Werte entnehmen.\cite{KathreinCAS90HD}
\begin{equation}
    G_\mathrm{R,max}=
    \begin{cases}
        38.6\,\mathrm{dBi}&,10.7\,\text{GHz}\leq f\leq 11.7\,\text{GHz}\\
        39.2\,\mathrm{dBi}&,11.7\,\text{GHz}\leq f\leq 12.5\,\text{GHz}\\
        39.6\,\mathrm{dBi}&,12.5\,\text{GHz}\leq f\leq 12.75\,\text{GHz}\\
    \end{cases}
    \label{eq:Gewinn-der-Empfangsantenne}
\end{equation}
Der bisher montierte LNB ist für den Empfang von Satellitenfernsehen ausgelegt und für die gewünschte Anwendung nicht geeignet. Daher wird dieser gegen einen Triplebandfeed von der Firma BaMaTech ausgetrauscht. Dieser Antennenfeed ist speziell für den Einsatz an Es'Hail-2 (QO-100) entwickelt und kann in drei verschiedenen Frequenzbänder eingesetzt werden. Daher kommt auch der folgt auch sein Name.\cite{amatech-feed}
\begin{figure}[H]
    \centering
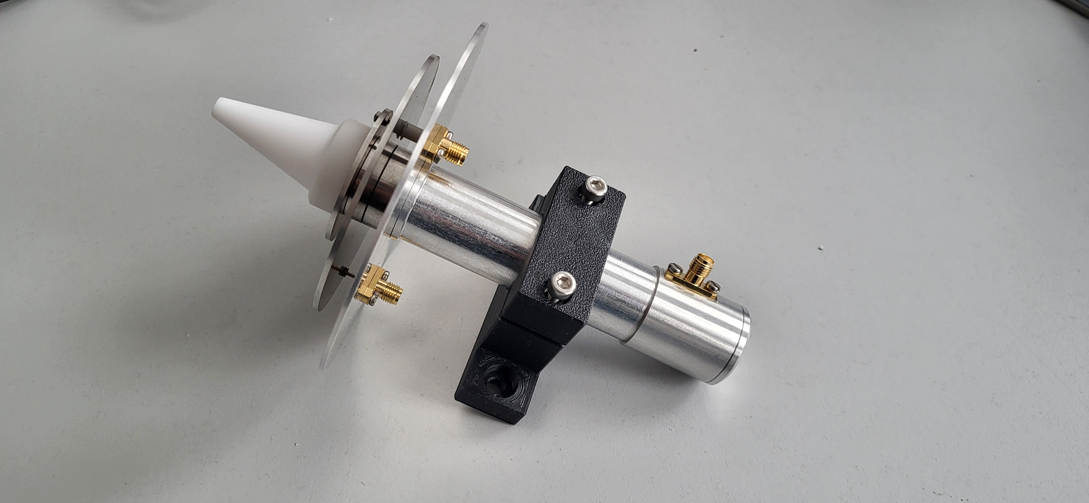
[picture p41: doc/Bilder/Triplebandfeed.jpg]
    
    \caption{Das Bild zeigt den ausgewählten Triplebandfeed von BaMaTech. Die schwarze Halterung am Antennenfeed dient zur Montage des Antennenfeeds in einem Halter. Diese ist im Zuge der Arbeit entwickelt worden.}
    \label{fig:verwendeter Triplebandfeed}
\end{figure}
Das Abbildung \ref{fig:verwendeter Triplebandfeed} zeigt den Triplebandfeed von der Firma BaMaTech. Im Grunde handelt es sich dabei um eine Hornantenne mit drei Anschlüssen für die einzelnen Frequenzbänder. Verwendet werden kann der Triplebandfeed im S-Band bei $2.4\,\text{GHz}$, im C-Band bei $5.6\,\text{GHz}$ und im X-Band bei $10.5\,\text{GHz}$, wobei im Zuge dieser Arbeit nur der Anschluss für das X-Band, wo sich der Downlink von Es'Hail-2 (QO-100) befindet, interessant.\cite{amatech-feed}\newline 
Angeschlossen werden kann der Triplebandfeed mittels SMA-Steckverbindungen.\cite{amatech-feed}\newline
Um die Tauglichkeit der Parabolantenne und des Feed für die Anwendung an Es'Hail-2 (QO-100) zu überprüfen kann zu einem die Effizienz $\eta_\mathrm{ANT}$ der effektive Antennenfläche $A_\mathrm{E}$ bestimmt werden. Auch kann die Reflexion $S11$ des Antennenfeeds gemessen und anschließend das $VSWR$ werden.\newline
Die effektive Antennenfläche $A_\mathrm{E}$ der Parabolantenne kann über die Gleichung \ref{eq:effektive-Antennenfläche} bestimmt werden. Benötigt wird dafür der Gewinn $G_\mathrm{R,max}$ der Parabolantenne und die Wellenlänge $\lambda$ der betrachteten Frequenz $f$. Von Interesse ist die Frequenz des Downlink von Es'Hail-2 (QO-100). Die Mittenfrequenz beträgt $f_\mathrm{center}=10489.750\,\text{MHz}\approx 10.5\,\text{GHz}$, was zu einer Wellenlänge $\lambda_\mathrm{center}=0.0286\,\text{m}$ führt. Der Gewinn der Antenne kann aus Gleichung \ref{eq:Gewinn-der-Empfangsantenne} mit $G_\mathrm{R,max}=38.6\,\text{dBi}$ angenommen werden.
\begin{equation}
    A_\mathrm{E}=\frac{G_\mathrm{R,max}\cdot\lambda_\mathrm{center}^2}{4\cdot\pi}=\frac{38.6\,\text{dBi}\cdot(0.0286\,\text{m})^2}{4\cdot\pi}=0.472\,\text{m}^2
    \label{eq:effektive-Antennenfläche-der-Empfangsantenne}
\end{equation}
Um die Effizienz der effektiven Antennenfläche $A_\mathrm{E}$ zu bestimmen, muss zunächst die physikalische Fläche $A_\mathrm{phy}$ der Parabolantenne bestimmt werden. Diese kann mithilfe der Mantelfläche eines Rotationsparaboloid bestimmt werden.\newline 
Die Mantelfläche des Rotationsparaboloid kann mit der Höhe $h$ des Rotationsparaboloid und dessen Radius $r=\frac{d}{2}$ bestimmt werden. Die Höhe von Boden bis zur Kante der Parabolantenne beträgt $h=0.1\,\text{m}$.
\begin{equation}
\begin{split}
   A_\mathrm{phy}
   &=\frac{\pi\cdot r}{6h^2}\cdot\left((r^2+4h^2)^{\frac{3}{2}}-r^3\right)\\
   &=\frac{\pi\cdot 0.45\,\text{m}}{6\cdot(0.1\,\text{m})^2}\cdot\left(((0.45\,\text{m})^2+4\cdot(0.1\,\text{m})^2)^{\frac{3}{2}}-(0.45\,\text{m})^3\right)\\
   &=0.667\,\text{m}^2 
\end{split}
\label{eq:physikalische-Fläche-der-Empfangsantenne}
\end{equation}
Zusammen mit der effektiven Antennenfläche $A_\mathrm{E}$ in \ref{eq:effektive-Antennenfläche-der-Empfangsantenne} und der physikalischen Antennenfläche $A_\mathrm{phy}$ in \ref{eq:physikalische-Fläche-der-Empfangsantenne} kann die Effizienz $\eta_\mathrm{ANT}$ der Parabolantenne mit Gleichung \ref{eq:Effizienz-effektive-Antennenfläche} bestimmt werden.
\begin{equation}
    \eta_\mathrm{ANT}=\frac{A_\mathrm{E}}{A_\mathrm{phy}}=\frac{0.472\,\text{m}^2}{0.667\,\text{m}^2}=0.708=70.8\,\%
    \label{eq:Effizienz-der-Antennenfläche-der-Empfangsantenne}
\end{equation}
Mit $\eta_\mathrm{Ant}= 70.8\,\%$ liegt die Effizienz der effektiven Antennenfläche $A_\mathrm{E}$ im typischen Bereich $(60\,\%-80\,\%)$ für Parabolantennen. Damit ist diese Parabolantenne für den Empfang des Downlinks von Es'Hail-2 (QO-100) geeignet.\newline
Die Reflexion $S11$ des Antennenfeeds kann mithilfe eines Vektor Netzwerk Analysator (VNA) gemessen werden. Verwendet wird hierfür ein VNA von Rohde und Schwarz, genauer der R\&S ZVL. Vor der Messung wird dieser entsprechend in einem Frequenzbereich von $2\,\text{GHz}$ bis $12\,\text{GHz}$ für Offen (Open), Kurzschluss (Short) und einer Last (Load) $50\,\Omega$ kalibriert. Beim Kalibrierkit handelt es sich um ein 01 BN 533828 vom Hersteller Spinner. Der Messaufbau ist in der Abbildung \ref{fig:Messaufbau-für-S11-des-Antennenfeeds} dargestellt.
\begin{figure}[H]
    \centering
    \includesvg[width=0.5\linewidth]{Bilder/Messaufbau S11}
    \caption{Messaufbau zur Ermittlung der Reflexion $S11$ des Antennenfeeds}
    \label{fig:Messaufbau-für-S11-des-Antennenfeeds}
\end{figure}
Für die Reflexion im X-Band wird der Frequenzbereich von $9\,\text{GHz}$ bis $12\,\text{GHz}$ mit $201$ Messpunkten betrachtet. Die Leistung wird auf $0\,\text{dBm}$ gesetzt, da es sich um ein passives Element handelt. Die Auflösung wird auf $5\,\text{dB/div}$ und das Referenzlevel auf $0\,\text{dB}$ eingestellt.
\begin{figure}[H]
    \centering
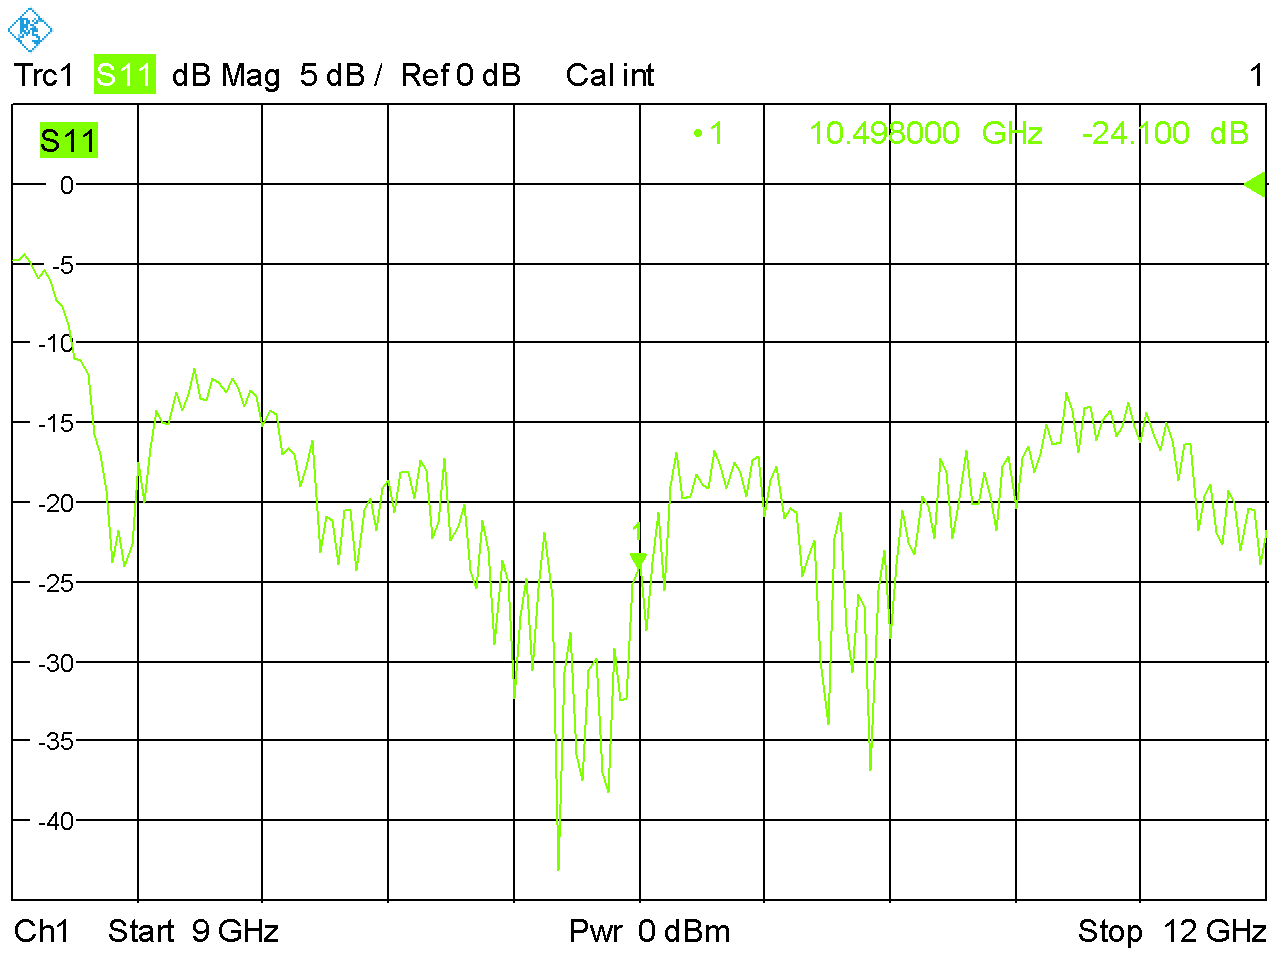
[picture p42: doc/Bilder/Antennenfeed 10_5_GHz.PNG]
    
    \caption{Gemessene Reflexion $S11$ des Antennenfeeds im X-Band}
    \label{fig:S11-Antennenfeed-X-Band}
\end{figure}
Der Graph in Abbildung \ref{fig:S11-Antennenfeed-X-Band} zeigt die gemessene Reflexion $S11$ des Antennenfeeds zwischen $9\,\text{GHz}$ und $12\,\text{GHz}$. Der Marker 1 befindet sich bei $10.498\,\text{GHz}$, was nahe der Mittenfrequenz des Downlins von $f_\mathrm{center}=10489.750\,\text{MHz}$ ist. Gemessen wird an der Stelle eine Reflexion von $S11=-24.1\,\text{dB}$. Mithilfe der Reflexion kann das $VSWR$ bestimmt werden. Das $VSWR$ ist das Stehwellenverhältnis ist ein Maß für die Impedanzanpassung zwischen der Antenne und der Koaxialleitung (Quelle) an. Es entspricht dem Verhältnis der maximalen zur minimalen Spannung einer stehenden Welle und gibt damit an, wie viel Leistung von der Antenne zurück zur Quelle reflektiert wird. Bei $VSWR=1$ wird keine Leistung zurück zur Quelle reflektiert und die gesamte Leistung wird von der Antenne abgestrahlt. Das $VSWR$ kann mithilfe des Reflexionsfaktors $\Gamma=10^{\frac{S11}{20}}$bestimmt werden.\newline
\begin{equation}
    VSWR=\frac{U_\mathrm{max}}{U_\mathrm{min}}=\frac{1+|\Gamma|}{1-|\Gamma|}=\frac{1+|10^{\frac{-24.1\,\text{dB}}{20}}|}{1-|10^{\frac{-24.1\,\text{dB}}{20}}|}=1.13
    \label{eq:VSWR-Empfangsantenne-X-Band}
\end{equation}
Mit einem $VSWR=1.13$ ist die Antenne sehr gut für den Frequenzbereich des Downlinks von Es'Hail-2 (QO-100) angepasst und ist somit für diese Anwendung geeignet.\newline
Auch kann die Reflexion des S-Band gemessen werden, falls in der Zukunft noch ein Uplink zu Es'Hail-2 (QO-100) an der Bodenstation eingerichtet werden soll. Der Messaufbau bleibt der gleiche. Betrachtet wird für die Reflexion $S11$ der Bereich von $2\,\text{GHz}$ bis $3\,\text{GHz}$. Ebenfalls mit $201$ Messpunkten und einer Leistung von $0\,\text{dBm}$. Die Auflösung wird auf $5\,\text{dB/div}$ und das Referenzlevel auf $0\,\text{dB}$ eingestellt.
\begin{figure}[H]
    \centering
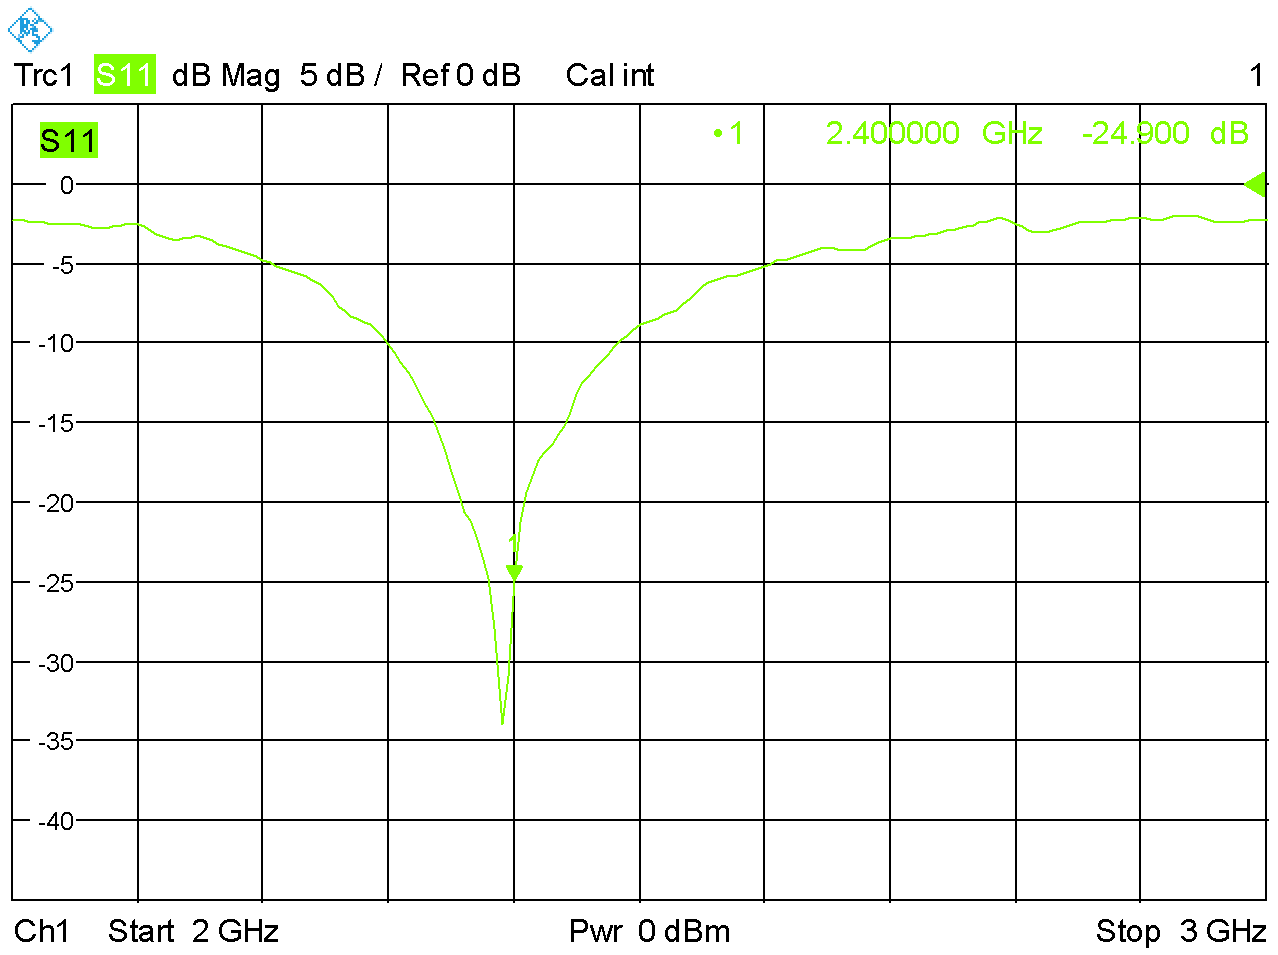
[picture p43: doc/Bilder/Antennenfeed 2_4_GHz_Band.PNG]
    
    \caption{Gemessene Reflexion $S11$ zwischen $2\,\text{GHz}$ und $3\,\text{GHz}$}
    \label{fig:S11-Antennenfeed-S-Band}
\end{figure}
Die Abbildung \ref{fig:S11-Antennenfeed-S-Band} zeigt die gemessene Reflexion $S11$ des Antennenfeeds zwischen $2\,\text{GHz}$ und $3\,\text{GHz}$. Der Marker befindet sich bei $2.4\,\text{GHz}$, was nah an der Mittenfrequenz $f_\mathrm{center}=2400.250\,\text{MHz}$ des Uplinks zu Es'Hail-2 (QO-100) ist. An diesem Punkt wird eine Reflexion von $S11=-24.9\,\text{dB}$ gemessen. Mithilfe der Gleichung \ref{eq:VSWR-Empfangsantenne-X-Band} kann das $VSWR$ bestimmt werden.
\begin{equation}
    VSWR=\frac{U_\mathrm{max}}{U_\mathrm{min}}=\frac{1+|\Gamma|}{1-|\Gamma|}=\frac{1+|10^{\frac{-24.9\,\text{dB}}{20}}|}{1-|10^{\frac{-24.9\,\text{dB}}{20}}|}=1.12
    \label{eq:VSWR-Empfangsantenne-S-Band}
\end{equation}
Das Ergebnis in Gleichung \ref{eq:VSWR-Empfangsantenne-S-Band} zeigt, dass die Antenne für Frequenzbereich des Uplinks zu Es'Hail-2 (QO-100) angepasst ist. Somit kann der Antennenfeed auch für den Uplink verwendet werden.\newline
\subsubsection*{Rauscharmer Signalumsetzer und Fernspeiseweiche}
Der von der Antenne empfangene Frequenzbereich wird über eine Koaxialleitung an das Empfangssystem weitergegeben. Jedoch ist ist die Leistung der gewünschte Signale zu gering und die Frequenz des Signals mit $f\approx10.5\,\text{GHz}$ viel zu hoch um direkt vom SDR verarbeitet werden zu können. Zuvor müssen die Signale also verstärkt und in niedriges Frequenzband umgesetzt werden.\newline
Für diesen Zweck wird rauscharmer Signalumsetzer (engl. low Noise Converter) LNC der Firma Kuhne Electronic. Der MKU LNC 10 QO-100 ist für die Anwendung im $3\,\text{cm-Amateurfunkband}$, speziell für die Anwendung an Es'Hail-2 (QO-100), vorgesehen.\cite{kuhne-downconverter}\newline
Dieser LNC kombiniert einen rauscharmen Verstärker (engl. Low Noise Amplifier) LNA und einen Mischer in einem Gerät und hat mehrere Vorteile gegenüber einem diskreten Aufbau aus Mischer und LNA. Gegenüber dem diskreten Aufbau benötigt der LNC weniger Platz und nur eine Stromversorgung gegenüber zwei beim diskreten Aufbau. Somit werden auch weniger Komponenten und Leitungen benötigt, was die Anzahl der Rauschquellen reduziert.\newline
\begin{figure}[H]
    \centering
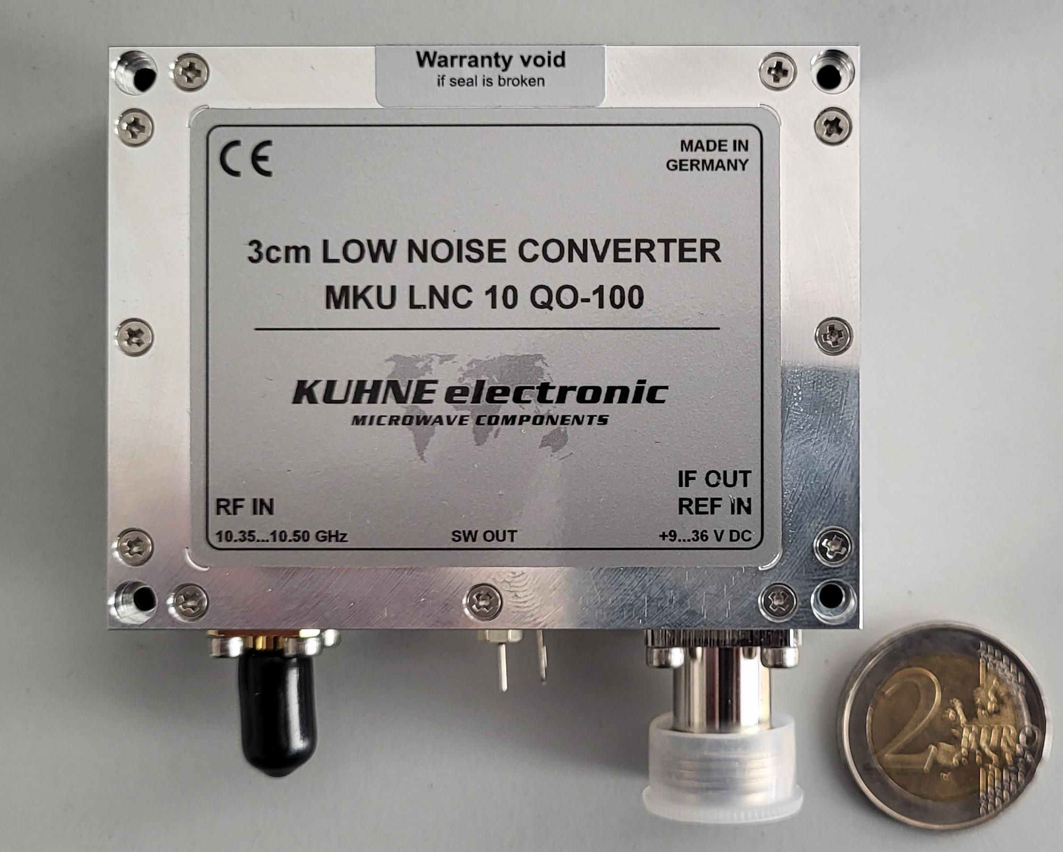
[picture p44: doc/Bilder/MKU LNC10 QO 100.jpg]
    
    \caption{Der vewendete MKU LNC 10 QO-100 von Kuhne Electronic. Die 2-Euro Münze dient zum Größenvergleich.}
    \label{MKU LNC 10 QO-100}
\end{figure}
Der MKU LNC 10 QO-100 verfügt über einen HF-Eingang und einen ZF-Ausgang, wobei am Eingang eine SMA-Buchse und am Ausgang eine N-Buchse verbaut ist. Er unterstützt vier verschiedene Frequenzbänder zwischen wischen $10.35\,\text{GHz}$ und $10.5\,\text{GHz}$, welche über die Frequenz des lokalen Oszillator $f_\mathrm{LO}$ ausgewählt werden können.\cite{kuhne-downconverter}\newline
Die Frequenz des lokalen Oszillator $f_\mathrm{ZF}$ kann mithilfe der Betriebsspannung $V_\mathrm{CC}$ ausgewählt werden. Die Betriebsspannung $V_\mathrm{CC}$ wird über die ZF-Buchse eingespeist.\cite{kuhne-bias-tee}\newline
Mit der Veränderung der Frequenz des lokalen Oszillator $f_\mathrm{LO}$ wird auch die Frequenz des ZF-Signals $f_\mathrm{ZF}$ am ZF-Ausgang verändert.\cite{kuhne-downconverter}
\begin{itemize}
    \item Q0-100 SSB-Betrieb: Bei einer Betriebsspannung $12\,\text{V}\leq V_\mathrm{CC} \leq 17\,\text{V}$ befindet sich der LNC im Einseitenbandbetrieb. Die Frequenz des HF-Bereiches $f_\mathrm{HF}$ befindet sich dann zwischen $10489\,\text{MHz}$ und $10490\,\text{MHz}$ und die Frequenz des lokalen Oszillator liegt bei $f_\mathrm{LO}=10056\,\text{MHz}$.\cite{kuhne-downconverter} Die Frequenz des ZF-Signals $f_\mathrm{ZF}$ kann mit Gleichung \ref{eq:Frequenz-des-Mischproduktes} bestimmt werden.
    \begin{equation}
    \label{eq:fZF-QO100-SSB}
        \begin{split}
            &f_\mathrm{ZF,min}=f_\mathrm{HF,min}-f_\mathrm{LO}=10489\,\text{MHz}-10056\,\text{MHz}=433\,\text{MHz}\\  
            &f_\mathrm{ZF,max}=f_\mathrm{HF,max}-f_\mathrm{LO}=10490\,\text{MHz}-10056\,\text{MHz}=434\,\text{MHz}
        \end{split}
    \end{equation}
    \item QO-100 ATV-Betrieb: Um den QO-100 Betriebsmodus verwenden zu können muss die Betriebsspannung $V_\mathrm{CC}$ zwischen $18\,\text{V}$ und $23\,\text{V}$ DC liegen. Die Frequenz des HF-Bereich $f_\mathrm{HF}$befindet sich dann zwischen $10490\,\text{MHz}$ und $10500\,\text{MHz}$. Der lokale Oszillator hat damit dann eine Frequenz von $f_\mathrm{LO}=9240\,\text{MHz}$.\cite{kuhne-downconverter} 
    \begin{equation}
    \label{eq:fZF-QO100-ATV}
        \begin{split}
            &f_\mathrm{ZF,min}=f_\mathrm{HF,min}-f_\mathrm{LO}=10490\,\text{MHz}-9240\,\text{MHz}=1250\,\text{MHz}\\  
            &f_\mathrm{ZF,max}=f_\mathrm{HF,max}-f_\mathrm{LO}=10500\,\text{MHz}-9240\,\text{MHz}=1260\,\text{MHz}
        \end{split}
    \end{equation}
    \item SSB-Betrieb: Bei einer Betriebsspannung $V_\mathrm{CC}$ zwischen $9\,\text{V}$ und $11\,\text{V}$ DC befindet sich der LNC im Einseitenbandbetrieb im HF-Bereich zwischen $10368\,\text{MHz}$ und $10370\,\text{MHz}$. Der lokale Oszillator hat in diesem Betriebsmodus eine Frequenz von $f_\mathrm{LO}=9936\,\text{MHz}$.\cite{kuhne-downconverter}
    \begin{equation}
    \label{eq:fZF-SSB1}
        \begin{split}
            &f_\mathrm{ZF,min}=f_\mathrm{HF,min}-f_\mathrm{LO}=10368\,\text{MHz}-9936\,\text{MHz}=433\,\text{MHz}\\  
            &f_\mathrm{ZF,max}=f_\mathrm{HF,max}-f_\mathrm{LO}=10370\,\text{MHz}-9936\,\text{MHz}=434\,\text{MHz}
        \end{split}
    \end{equation}    
    \item SSB-Betrieb: Das letzte unterstütze Frequenzband von $10450\,\text{MHz}$ bis $10452\,\text{MHz}$ im HF-Bereich, kann mit einer Betriebsspannung $V_\mathrm{CC}$ zwischen $24\,\text{V}$ und $36\,\text{V}$ DC ausgewählt werden. Der LNC befindet sich wieder in einem Einseitenbandbetrieb. Der lokale Oszillator schwingt dabei mit einer Frequenz $f_\mathrm{LO}=10016\,\text{MHz}$.\cite{kuhne-downconverter} 
    \begin{equation}
    \label{eq:fZF-SSB1}
        \begin{split}
            &f_\mathrm{ZF,min}=f_\mathrm{HF,min}-f_\mathrm{LO}=10450\text{MHz}-10016\,\text{MHz}=434\,\text{MHz}\\  
            &f_\mathrm{ZF,max}=f_\mathrm{HF,max}-f_\mathrm{LO}=10452\,\text{MHz}-10016\,\text{MHz}=436\,\text{MHz}
        \end{split}
    \end{equation}  
\end{itemize}
Der LNC hat eine typische Verstärkung von $G_\mathrm{LNC}=55\,\text{dB}$ und wird mit einer Rauschzahl von $F_\mathrm{LNC}=1.7\,\text{dB}=1.48$ bei $T_\mathrm{0}=291\,\text{K}$ angegeben, was für eine Kombination aus Mischer und Verstärker gute Werte sind.\cite{kuhne-downconverter}\newline
Mit Gleichung \ref{eq:Rauschzahl-aus-Te-und-T0} lässt sich die äquivalente Rauschtemperatur $T_\mathrm{e,LNC}$ des LNC bestimmen.
\begin{equation}
    T_\mathrm{eLNC}=(F_\mathrm{LNC}-1)T_\mathrm{0}=(1.48-1)290\,\text{K}=139.2\,\text{K}
    \label{eq:TE-LNC}
\end{equation}
Für den Betrieb des LNC ist nur die Einspeisung der Betriebsspannung $V_\mathrm{CC}$ notwendig. Die Einspeisung eines $10\,\text{MHz}$ Referenzsignals ist nicht erforderlich, kann aber zu einer besseren Frequenzstabilität beitragen.\cite{kuhne-downconverter}\newline
Die Betriebsspannung $V_\mathrm{CC}$ und ggf. das $10\,\text{MHz}$ Referenzsignal werden mithilfe einer Fernspeiseweiche (engl. Bias-Tee) in die Leitung am ZF-Ausgang eingespeist. Verwendet wird hier für die Fernspeiseweiche KU BT 10 REF. Diese stammt ebenfalls von der Firma Kuhne Electronic und ist für den MKU LNC 10 QO-100 vorgesehen.\newline
\begin{figure}[H]
    \centering
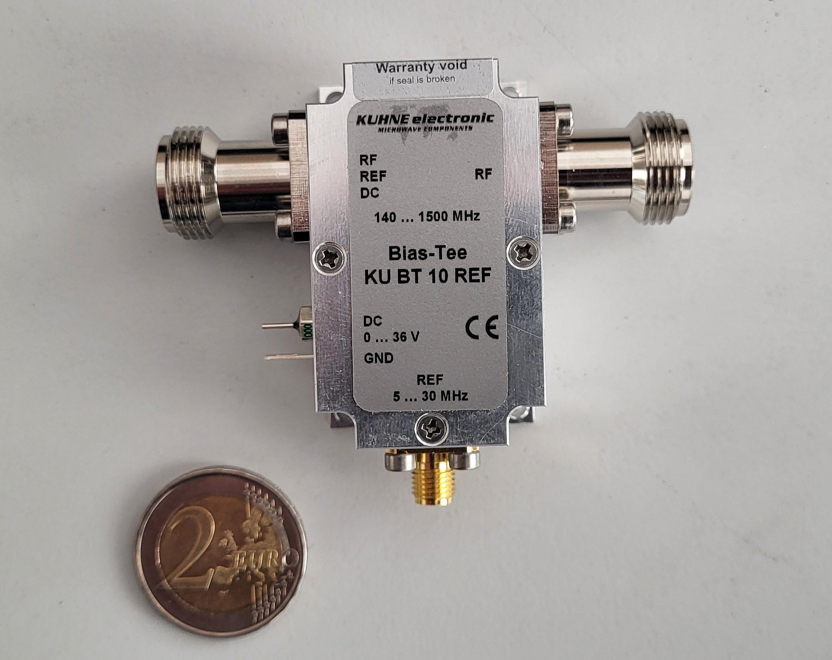
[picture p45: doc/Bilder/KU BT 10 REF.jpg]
    
    \caption{Die verwendete Fernspeiseweiche KU BT 10 REF von Kuhne Electronic. Die 2-Euro Münze dient zum Größen Vergleich.}
    \label{fig:KU-BT-10-REF}
\end{figure}
Die Fernspeiseweiche verfügt über drei Anschlüsse. Über de beiden N-Buchsen wird die Fernspeiseweiche in den RF-Weg zwischen dem ZF-Ausgang am LNC und dem Patchfeld geschaltet. Über die SMA-Buchse kann ein sinusförmiges $10\,\text{MHz}$ Referenzsignal mit maximal $2\,\text{Vss}$ für den LNC eingespeist werden. Die Versorgungsspannung $V_\mathrm{CC}$ für den LNC wird über die beide Pins auf der linken Seite in Abbildung \ref{fig:KU-BT-10-REF} in die Leitung zum LNC eingespeist.\cite{kuhne-bias-tee}\newline
Auslegt ist die Fernspeiseweiche im RF-Weg für Frequenzen $f_\mathrm{ZF}$ zwischen $140\,\text{MHz}$ und $1500\,\text{MHz}$. Die Verluste der Fernspeiseweiche betragen typisch $L_\mathrm{BiasTee}=1\,\text{dB}$ und maximal $L_\mathrm{BiasTee}=1.5\,\text{dB}$. Die maximale Leistung des Signals im RF-Weg darf $100\,\text{mW}=20\,\text{dBm}$ nicht überschreiten, da sonst die Fernspeiseweiche beschädigt werden könnte.\cite{kuhne-bias-tee}\newline
Die eingespeiste Versorgungsspannung $V_\mathrm{CC}$ kann im Bereich von $0\,\text{V}$ bis maximal $36\,\text{V}$ DC liegen und der Strom darf nicht größer als $500\,\text{mA}$ DC werden.\cite{kuhne-bias-tee}
\subsubsection*{Patchfeld und Schaltmatrix}
Bei der verwendeten Schaltmatrix handelt es sich um das Model RC-2SP4T-A18 von der Firma Mini-Circuits. Diese kann mit einer PC-Software über USB oder Ethernet gesteuert werden kann. Auch Remotezugriffe über eine Webseite sollten möglich sein.\cite{RFSP4T_Switch}\newline
Insgesamt bietet die Schaltmatrix 10 SMA Anschlüsse, welche für Signale mit einer Frequenz $f$ von $\text{DC}$ bis $18\,\text{GHz}$ und einer Leistung bis zu $20\,\text{W}$ sind. Die Schaltgeschwindigkeit beträgt dabei typischerweise $25\,\text{ms}$.\cite{RFSP4T_Switch}\newline
Die maximalen auftretenden Verluste sind von der Frequenz $f$ abhängig.\cite{RFSP4T_Switch}
\begin{equation}
    L_\mathrm{RF-Switch,max}=
    \begin{cases}
        0.3\,\text{dB}&,\text{DC}\leq f\leq 8\text{GHz}\\
        0.4\,\text{dB}&,8\,\text{GHz}\leq f\leq 12\text{GHz}\\
        0.8\,\text{dB}&,12\,\text{GHz}\leq f\leq 20\text{GHz}\\
    \end{cases}
\label{eq:max-Verluste-RF-Switch}    
\end{equation}
Auch bei hohen Frequenzen bleibt der maximale Verlust der Schaltmatrix gering. Bei den zu erwartenden Frequenzen $f_\mathrm{ZF}\leq1.3\,\text{GHz}$ würde ein maximaler Verlust durch die RF-Switch Matrix von $L_\mathrm{RF-Switch}=0.3\,\text{dB}$ auftreten. Das macht diese Schaltmatrix geeignet für die Anwendung im RF-Bereich des Empfangssystems.\newline
\begin{figure}[H]
    \centering
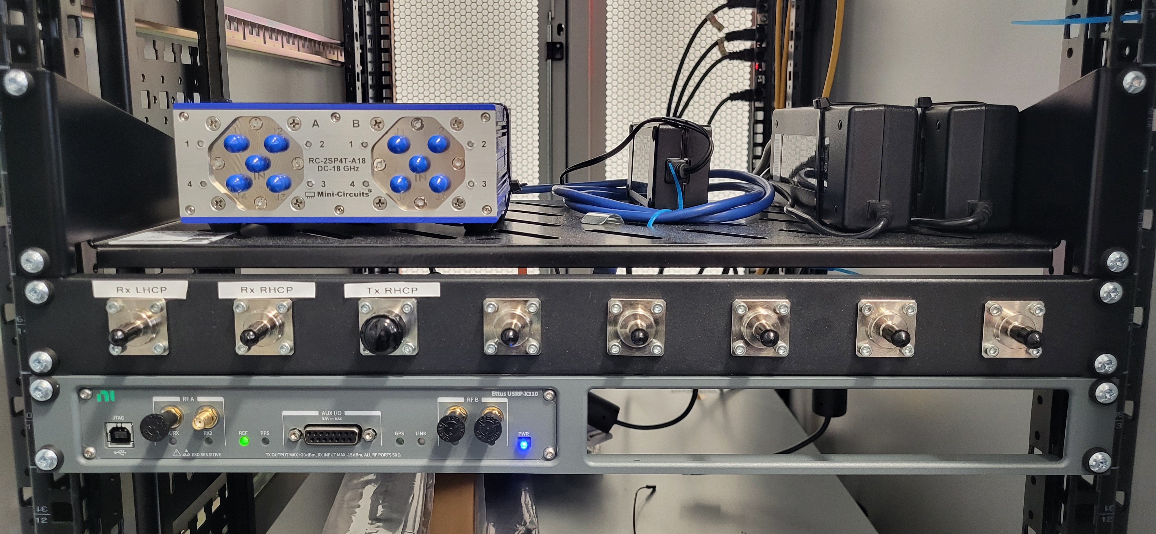
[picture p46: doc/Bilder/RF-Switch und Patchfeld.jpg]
    
    \caption{Verwendete Schaltmatrix RC-2SP4T-A18 und das Patchfeld}
    \label{fig:RF-Switch und Patchfeld}
\end{figure}
Die Abbildung \ref{fig:RF-Switch und Patchfeld} zeigt die verwendete Schaltmatrix (blau/silbernede Box in linken Mitte des Bildes) und das Patchfeld (schwarze Leiste mit den einzelnen SMA-Anschlüssen) im Serverschrank. Beim eingesetzten Patchfeld handelt es sich um ein Eigenbau. Insgesamt besteht das Patchfeld aus 7 N zu SMA Adapter Buchsen und einer N auf N Buchse. In diesem Empfangssystem wird eine N zu SMA Adapter Buchse verwendet. Der Verlust durch die Apapter Buchse kann ebenfalls mit einem VNA gemessen werden.
\begin{figure}[H]
    \centering
    \includesvg[width=0.4\linewidth]{Bilder/Messaufbau S21 Patchfeld}
    \caption{Messaufbau zum Messen des Verlustes durch Adapter Buchse}
    \label{fig:Messaufbau-S21-Patchfeld}
\end{figure}
Die Abbildung \ref{fig:Messaufbau-S21-Patchfeld} zeigt den angewendeten Messaufbau. Gemessen werden die Einspeiseverluste $S21$ zwischen $400\,\text{MHz}$ und $1.5\,\text{GHz}$, da die zu erwartenden Frequenzen $f_\mathrm{ZF}$ des ZF-Signals zwischen $433\,\text{MHz}$ und $1.26\,\text{GHz}$ liegen. Vor dem durchführen der Messung wird der VNA für den entsprechenden Frequenzbereich für Offen (Open), Kurzschluss (Short), Last (Load) von $50\,\Omega$ und Durchgang (Through) kalibriert. Das verwendete Kalibriertkit ist das 01 BN 533828 vom Hersteller Spinner.\newline
Das es sich um ein passives Element handelt, wird die Leistung auf $0\,\text{dBm}$ gestellt. Die Anzahl der Messpunkte beträgt $201$, die Auflösung $0.2\,\text{dB/div}$ und das Referenzlevel $0\,\text{dB}$.
\begin{figure}[H]
    \centering
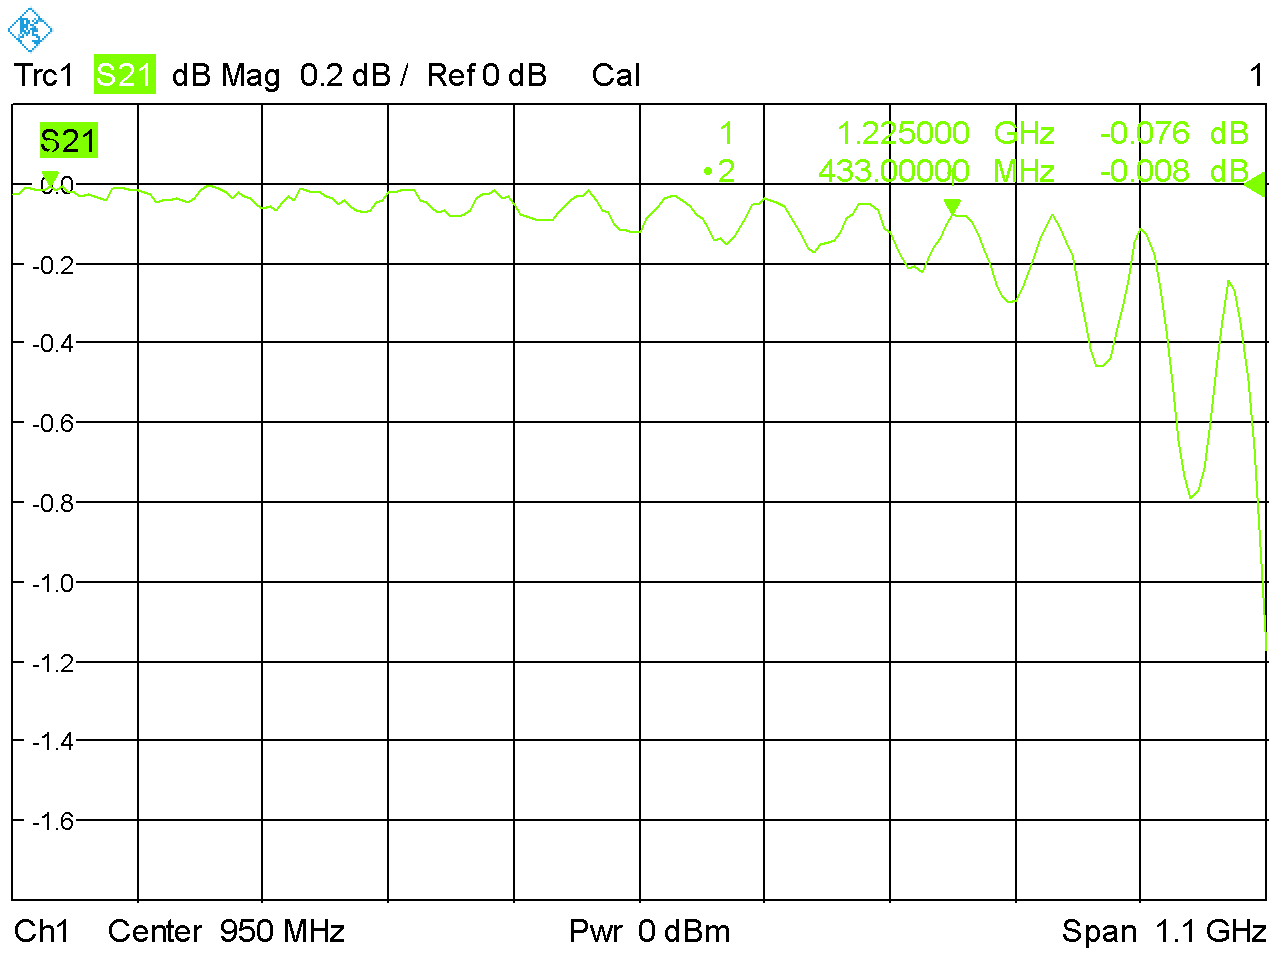
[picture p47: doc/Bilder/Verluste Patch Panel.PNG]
    
    \caption{Gemessene Einspeiseverluste $S21$ zwischen $400\,\text{MHz}$ und $1.5\,\text{GHz}$ des Patchfeld }
    \label{fig:S21-Patchfeld}
\end{figure}
Der Graph in Abbildung \ref{fig:S21-Patchfeld} zeigt die gemessenen Einspeiseverluste $S21$ des Patchfeld zwischen $400\,\text{MHz}$ und $1.5\,\text{GHz}$. Der Marker 1 befindet sich bei $433\,\text{MHz}$, was die niedrigste zu erwartende Frequenz $f_\mathrm{ZF}$ des ZF-Signals ist. Gemessen wird hier ein Verlust von $S21=0.008\,\text{dB}$. Der zweite Marker befindet sich bei $1.225\text{GHz}$. Der gemessene Verlust liegt hier bei $S21=0.076\,\text{dB}$. Beider Verluste sind sehr niedrig und fallen kaum ins Gewicht. Daher kann das Patchfeld problemlos im RF-Frontend des Empfangsystems verwendet werden. Für einen allgemeinen Wert wird die Dämpfung durch das Patchfeld mit dem höchsten gemessenen Dämpfungswert angegeben.
\begin{equation}
    L_\mathrm{Patchfeld}=0.076\,\text{dB}\approx0.8\,\text{dB}
\end{equation}

\subsubsection*{Wahl der Koaxialleitungen}
Die Koaxialleitungen sind notwendig um die einzelnen Komponenten mit einander zu verbinden. Es gibt viele verschiedene Arten an Koaxialleitungen, jedoch kann nicht eine beliebige genommen für jeden Abschnitt im RF-Bereich des Empfangssystems genommen werden. Jede Art an Koaxialleitung hat unterschiedliche Eigenschaften, welche es für bestimmte Anwendungsgebiete geeignet und für andere wiederum ungeeignet machen. Zum Beispiel kann je nach Art der Frequenzbereich, die Leitungsimpedanz ,die Dämpfung $\text{dB/m}$, die Anschlussmöglichkeiten, maximale Spannungsfestigkeit, sowie Umweltanforderungen und Preis stark variieren. Deshalb muss für jeden Abschnitt im RF-Frontend eine geeignete Koaxialleitung ausgewählt werden. Die jeweilige Koaxialleitung muss die folgenden Voraussetzungen erfüllen.
\begin{enumerate}
    \item Um mit der Systemimpedanz kompatibel zu sein, müssen die die Koaxialleitungen eine Impedanz von von $50\,\Omega$ aufweisen.
    \item Die jeweilige Koaxialleitung sollte für den jeweiligen Frequenzbereich im RF-Bereich des Empfangsystems geeignet sein. So können unnötigen Dämpfungen, etc. vermieden werden.
    \item Um die Rauschzahl $F_\mathrm{sys}$ des RF-Frontends und um die Verluste allgemein gering zu halten, sollte die Koaxialleitung eine niedrige Dämpfung und um das Signal gegen äußere elektromagnetische Strahlung zu schützen, ein hohes Schirmmaß aufweisen.
    \item Um das Verlegen der Koaxialleitungen zu vereinfachen und diese ebenfalls nicht zu beschädigen, sollte die Koaxialleitungen entsprechend geeignet für die Verlegung sein. Auch sollten die Koaxialleitungen für die jeweilige Umwelteinflüsse an ihrem Einsatzort geeignet sein.
    \item Die Koaxialleitung sollte die jeweiligen Steckverbindungen der Komponenten, ohne die Verwendung von Adapter, unterstützen. So können Verluste und damit verbunden mögliche Rauschquellen verringert werden.
\end{enumerate}
\begin{figure}[H]
    \centering
    \includesvg[width=0.75\linewidth]{Bilder/RF-Frontend}
    \caption{Darstellung des RF-Bereiches des Empfangssystems mit den einzelnen notwendigen Längen der Koaxialleitungen}
    \label{fig:länge-Koaxialleitungen}
\end{figure}
In der Abbildung \ref{fig:länge-Koaxialleitungen} ist eine Skizze vom RF-Bereich des Empfangsystems zu sehen. Dargestellt sind die einzelne Zweitore und die Koaxialleitungen, welche diese miteinander verbinden. Ebenfalls sind die notwendigen Längen der Koaxialleitungen eingetragen.\newline
Die erste Koaxialleitung (Koax 1) verbindet den Antennenfeed mit dem LNC. Diese Koaxialleitung ist das wichtigste Zweitor im gesamten RF-Frontend, da es das erste Zweitor in der Kette ist. Somit hat es die größte Auswirkung auf die Rauschzahl $F_\mathrm{ges}$ vom RF-Bereich des Empfangssystems. Da es eine Koaxialleitung ein passives Zweitor ist, wird die Rauschzahl $F_\mathrm{1}$, nach Gleichung \ref{eq:Rauschzahl-passives-Zweitor}, direkt aus den Verlusten der Koaxialleitung gewonnen. Daher muss eine Koaxialleitung mit besonders niedrigen Verlusten ausgewählt werden und die Länge der Koaxialleitung zu kurz wie möglich gehalten werden. Weiterhin muss die Koaxialleitung für eine Frequenz $f\approx10.5\,\text{GHz}$ ausgelegt sein, da diese Koaxialleitung das Signal des Downlink von Es'Hail-2 (QO-100) im X-Band zum LNC bringt, wo es dann in einen niedrigeren Frequenzbereich umgesetzt wird. Auch muss die Koaxialleitung für die Anwendung im Außenbereich geeignet sein, da sowohl Antenne und der LNC auf dem Dach der Hochschule montiert werden und die Leitung sollte flexibel sein, da vom Antennenfeed zum LNC enge Biegeradien zu erwarten sind. Als Steckverbindung sollte die Koaxialleitung SMA unterstützen.\newline
Für diese Verbindung wird die S\_04212\_B $50\,\Omega$ LOW-LOSS Koaxialleitung von Huber\&Suhner gewählt. Diese bestimmte Koaxialleitung ist für Frequenzen bis $18\,\text{GHz}$ geeignet und bietet mit einem Schirmmaß von $90\,\text{dB/m}$ guten Schutz vor elektromagnetischer Strahlung.\cite{S_04212_B}\newline 
Die Verluste in $\text{dB/m}$ können mithilfe einer Gleichung im Datenblatt für die gewünschte Frequenz bestimmt werden. Für eine Frequenz von $f\approx10.5\,\text{GHz}$ kann die folgende Dämpfung ermittelt werden.\cite{S_04212_B}
\begin{equation*}
    L=0.197\cdot \sqrt{f}+ 0.045\cdot f=0.197\cdot\sqrt{10.5\,\text{GHz}}+ 0.045 \cdot 10.5\,\text{GHz}=1.11\,\text{dB/m}
\end{equation*}
Das führt mit eine Länge von $l=1.5\,\text{m}$ zu einer Gesamtdämpfung von
\begin{equation}
    L_\mathrm{Koax1}=1.11\,\text{dB/m} \cdot 1.5\,\text{m}=1.655\,\text{dB}
    \label{eq:Dämpfung_Koax1}
\end{equation}
Die Dämpfung ist mit $1.655\,\text{dB}$, im Vergleich zum LL142 STR mit $\sim 1\,\text{dB}$\cite{LL142_koax24}, etwas höher. Jedoch ist die S\_04212\_B Koaxialleitung dank ihres SPE-Dielektrikum mit $50\,\%$ Luftanteil besonders flexibel und so auch führe engere statisch Biegeradien $\geq25\,\text{mm}$ geeignet\cite{S_04212_B}. Auch ist die S\_04212\_B Koaxialleitung deutlich günstiger \cite{LL142_koax24}\cite{S_04212_B_koax24} und mit ihren Mantel aus PUR (Polyurethan) besonders witterungsbeständig und für Temperaturen von $-40\degree\text{C}$ bis $+85\degree\text{C}$ geeignet.\cite{PUR_koax24}\newline
Die zweite Koaxialleitung (Koax2) verbindet den LNC mit der Fernspeiseweiche (Bias-Tee). Diese Koaxialleitung legt den größten Weg mit $l=13.5\,\text{m}$ zurück und sollte daher eine niedrige Dämpfung $\text{[db/m]}$ aufweisen. Zu erwarten sind nach der Abwärtsmischung Frequenzen $f_\mathrm{ZF}\leq1.3\,\text{GHz}$, was eine große Auswahlmöglichkeit an möglichen Koaxialleitung bietet. Zusätzlich sollte die Koaxialleitung für die Anwendung im Außenbereich und für Spannung $V_\mathrm{cc}\leq36\,\text{V}$ geeignet sein. Auch sollte die Koaxialleitung N-Stecker als Steckverbindung unterstützen.\newline
Ursprünglich ist für die zweiten Koaxialleitung eine LMR 600 Koaxialleitung vorgesehen gewesen. Diese ist bietet mit $0.109\,\text{dB/m}$ bei $f=1.5\,\text{GHz}$ eine sehr niedrige Dämpfung. Allerdings ist LMR 600 Koaxialleitung mit einem Biegeradius von $\geq38.1\,\text{mm}$ sehr starr, was zu Problemen bei der Verlegung führen könnte.\cite{LMR600}\newline
Aus diesem Grund wird die LMR 400 FR Koaxialleitung von Times Microwave verwendet. Diese hat mit $0.169\,\text{dB/m}$ bei $f=1.5\,\text{GHz}$ eine geringfügig höhere Dämpfung als das LMR 600 Kabel, ist jedoch mit einem Biegeradius $\geq25.4\,\text{mm}$ deutlich flexibler.\cite{LMR400_koax24}\cite{LMR400}\newline
Die Gesamtdämpfung $L_\mathrm{Koax2}$ dieser Koaxialleitung wird in Gleichung \ref{eq:Dämpfung_Koax2} mit einer Gesamtlänge $l=13.5\,\text{m}$ bestimmt.
\begin{equation}
    L_\mathrm{Koax2}=0.169\,\text{dB/m} \cdot 13.5\,\text{m}=2.282\,\text{dB}
    \label{eq:Dämpfung_Koax2}
\end{equation}
Dank des Mantels aus FRPE (Feuer Resistenten Polyethylen) ist die LMR 400 FR Koaxialleitung Wetterbeständig und für einen Temperaturbereich von $-40\degree\text{C}$ bis $+85\degree\text{C}$ geeignet.\cite{LMR400_koax24}\cite{FRPE_koax24}\newline
Mit einem Schirmmaß von $90\,\text{dB/m}$ schützt die LMR 400 FR Leitung gut gegen von außen einwirkende elektromagnetische Strahlung. Auch sind Spannungen bis $2500\,\text{V}$ und N-Stecker als Steckverbindung unterstützt.\cite{LMR400_koax24}\newline
Für die dritte Koaxialleitung (Koax3), welche die Fernspeiseweiche mit dem Patchfeld verbindet, wird ebenfalls die LMR 400 FR Koaxialleitung verwendet. Die Gesamtlänge dieser Leitung beträgt $l=1.5\,\text{m}$.
\begin{equation}
    L_\mathrm{Koax3}=0.169\,\text{dB/m} \cdot 1.5\,\text{m}=0.254\,\text{dB}
    \label{eq:Dämpfung_Koax3}
\end{equation}
Damit beträgt die Dämpfung der dritten Koaxialleitung $L_\mathrm{Koax3}=0.254\,\text{dB}$.\newline
Für die vierte (Koax4) und fünfte (Koax5) Koaxialleitung, welche das Patchfeld mit der Schaltmatrix und anschließend mit dem SDR verbinden, braucht es flexible Leitungen. Die flexiblen Leitung würden die Verkabelung im Serverschrank vereinfachen. Die Koaxialleitungen sollten zudem eine möglichst geringe Dämpfung und hohes Schirmmaß aufweisen, sowie für Frequenzen $f_\mathrm{ZF}\leq1.3\,\text{GHz}$ geeignet sein und SMA-Steckverbindung unterstützen.\newline
Verwendet werden für die beiden Koaxialleitungen die Hyperflex 5/ $50\,\Omega$ LOW-LOSS Koaxialleitung von Messi\&Paoloni. Diese Koaxialleitung ist für Frequenzen bis $6\,\text{GHz}$ geeignet und ist mit einem wiederholbaren Biegeradius von $50\,\text{mm}$ flexibel genug für diese Anwendung.\cite{Hyperflex5}\newline
Bei einer Frequenz $f=1.296\,\text{GHz}$ hat die Hyperflex 5 Koaxialleitung eine Dämpfung von $0.305\,\text{dB/m}$ und hat damit eine geringfügig bessere Dämpfung als eine Aircell 5 Koaxialleitung. Bei einer Länge von jeweils $l=0.35\,\text{m}$ führt das zu folgender Dämpfung je Koaxialleitung.\cite{Hyperflex5_koax24}
\begin{equation}
    L_\mathrm{Koax4}=L_\mathrm{Koax5}=0.309\,\text{dB/m} \cdot 0.35\,\text{m}=0.108\,\text{dB}
    \label{eq:Dämpfung_Koax4 und Koax5}
\end{equation}
Auch bietet die Hyperflex 5 Koaxialleitung mit $105\,\text{dB/m}$ ein sehr hohes Schirmmaß und es werden SMA-Steckverbindungen unterstützt.\cite{Hyperflex5_koax24}\newline
Damit die Kabel nicht unter ihren zulässigen Biegeradius gebogen werden können werden die Hyperflex 5 Koaxialleitungen mit einem Knickschutz versehen.\newline

\subsubsection*{Software Defined Radio und SDR Software}
Bei dem vorhandenen Software Defined Radio (SDR) handelt es sich um einen USRP X310 von Nationale Instruments. Der USRP X310 ist bestandteil einer skalierbaren SDR-Plattform, welche für die Entwicklung, Testung und Einsatz von Kommunikationsequipment vorgesehen ist.\cite{USRP-X310}
\begin{figure}[H]
    \centering
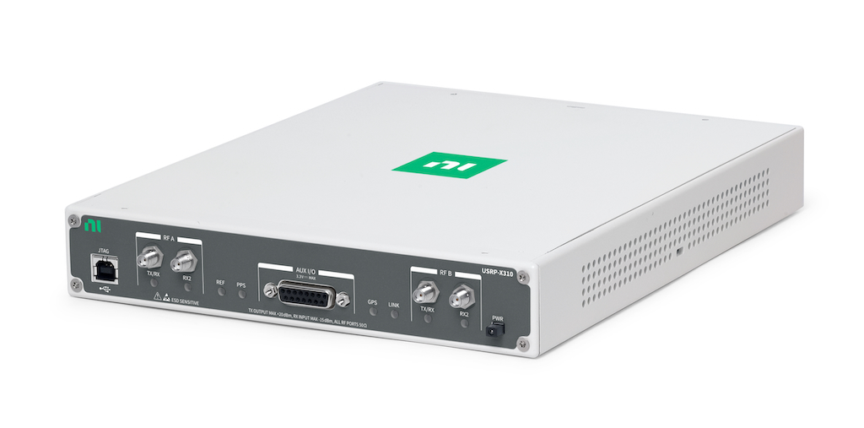
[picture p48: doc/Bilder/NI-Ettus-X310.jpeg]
    
    \caption{Der URSP X310 von National Instruments\cite{USRP-X310}}
    \label{fig:USRP-X310}
\end{figure}
Der USRP X310 basiert auf einem  XC7K410T FPGA, welcher eine schnelle Verbindung zu den Erweiterungskarten, dem $1\,\text{GB}$ DDR3 Arbeitsspeicher und verschiedenen Schnittstellen bietet, über welche das SDR mit einem PC verbunden werden kann.\cite{USRP-X310}\newline
Das SDR bietet die Möglichkeit über PCIe, über zwei $10\,\text{Gig}$ Ethernet- oder über zwei $1\,\text{Gig}$ Ethernetschnittstellen mit einem PC verbunden zu werden \cite{USRP-X310}. In diesem Fall ist der USRP X310 über eine $10\,\text{Gig}$ Ethernetschnittstelle mit dem PC verbunden.\newline
Das Herzstück des USRP X310 bilden die beiden die beiden modularen Erweiterungskarten. Insgesamt stehen 10 verschiedene Karten zur Auswahl. Von Ihnen ist der Frequenzbereich, die maximale Bandbreite und die Verstärkung abhängig. In dem USRP X310 sind zwei UBX Erweiterungskarten verbaut. Die UBX Erweiterungskarte erlaubt es dem USRP X310 in einem Frequenzbereich von $10\,\text{MHz}$ bis $6\,\text{GHz}$ zu arbeiten. Die maximale Bandbreite beträgt dabei $160\,\text{MHz}$. Die maximale Verstärkung der UBX Erweiterungskarte beträgt $G_\mathrm{SDR}=31.5\,\text{dB}$\cite{USRP-X310}\cite{USRP-X310-UBX-Doku}\newline
Jeder Kanal verfügt über einen 14-Bit ADC und einen 16-Bit DAC, wobei die maximale Abtastrate des ADC $200\,\text{MS/s}$. Die maximale Abtastrate des DAC beträgt $800\,\text{MS/s}$.\cite{USRP-X310}\newline
Mit der Bitgröße des ADC $n=14$ kann der Dynamikumfang des SDR ermittelt werden.\cite{DynamicRange}
\begin{equation}
\mathrm{DR} = 20 \cdot \log_{10}\left( 2^n \sqrt{\frac{3}{2}} \right)
= 20 \cdot \log_{10}\left( 2^{14} \sqrt{\frac{3}{2}} \right)
\approx 86\,\text{dB}.
\label{eq:dynamic-Range-USRP-X310}
\end{equation}
Mit dem Dynamikumfang wird das Verhältnis vom stärksten und schwächsten Signal angegeben, welches der SDR verarbeiten kann. Das stärkste Signal ist dabei das Signal, welches der SDR verarbeiten kann, ohne dabei zu übersteuern und das schwächste Signal stellt das Grundrauschen des SDR da. Der Dynamikumfang ist unter anderem wichtig für die zu wählende Verstärkung. Ist das verstärkte Signal zu groß für den Dynamikumfang kommt es zu einer Übersteuerung.\cite{DynamicRange}\newline
Mit der Gleichung \ref{eq:Rauschleistung-Ausgang-Zweitor} kann das Grundrauschen des SDR bestimmt werden. Die entschiedenen Faktoren für das thermische Grundrauschen ist die betrachtete Bandbreite $B$, die physikalische Temperatur $T_\mathrm{0}$ des SDR und die äquivalente Rauschtemperatur $T_\mathrm{eSDR}$ des SDR. Die Bandbreite $B$ wird mit der maximalen zulässigen Bandbreite $B=2.7\,\text{kHz}$ eines Signals über den Schmalbandtransponder angenommen. Bei physikalischen Temperatur wird von der Raumtemperatur $T_\mathrm{0}=290\,\text{K}$ ausgegangen. Die äquivalente Rauschtemperatur des SDR kann über die Umstellung der Gleichung \ref{eq:Rauschzahl-aus-Te-und-T0} aus der Rauschzahl $F_\mathrm{SDR}$ ermittelt werden. Diese wird mit typisch $F_\mathrm{SDR,dB}=8\,\text{dB}=6.31$ angegeben \cite{USRP-X310}.\newline
\begin{equation}
    T_\mathrm{eSDR}=(F_\mathrm{SDR}-1)\cdot T_\mathrm{0}=(6.31-1)\cdot290\,\text{K}=1539,9\,\text{K}
    \label{eq:äquivalente-Rauschtemperatur-SDR}
\end{equation}
Mit der äquivalente Rauschzahl aus Gleichung \ref{eq:äquivalente-Rauschtemperatur-SDR} kann dann das Grundrauschen vom SDR bestimmt werden.
\begin{equation}
\begin{split}
     N_\mathrm{oSDR}&=k\cdot(T_\mathrm{o}+T_\mathrm{eSDR})\cdot B=1.38\cdot10^{-23}\,\frac{\text{J}}{\text{K}}\cdot (290\,\text{K}+1539.9\,\text{K})\cdot2.7\,\text{kHz}\\
     &=6.82\cdot10^{-17}\,\text{W}=-131.66\,\text{dBm}
\end{split}
 \label{eq:Grundrauschen-SDR}  
\end{equation}
Der Pegel eines Siganls am Eingang des SDR müsste also größer als $-131.66\,\text{dBm}$ sein, um nicht im Grundrauschen des SDR zu verschwinden.\newline
Der maximale Eingangspegel am SDR darf $-15\,\mathrm{dBm}$ nicht überschreiten.\cite{USRP-X310-Doku}
Dank des Open-Source Software Support bietet der USRP X310 UHD Treiberunterstützung für verschiedene Plattformen, wie Windows und Linux Betriebssysteme, und ist mit C++ und Python APIs, sowie GNU Radio und anderen Frameworks und Programmen kompatibel.\cite{USRP-X310}\newline
Der Open-Source Software Support und die Kompatibilität mit GNU Radio bieten die Möglichkeit eine eigene geeignete SDR Software, speziell für den Einsatz an Es'Hail-2 (QO-100), zu erstellen. Bei GNU Radio handelt es sich um eine freie Software-Toolkit-Sammlung zur Implementierung von Software Defined Radio, kurz SDR. GNU Radio bietet eine umfangreiche Bibliothek an Signalverarbeitungsblöcken, welche zu einem gemeinsamen Flussgraphen einfach zusammengefügt werden können. Neben der Realisierung von Software Defined Radios, kann GNU Radio auch ohne Hardware für Simulation verwendet werden.\cite{GNU-Radio}\newline
Die in GNU Radio erstelle SDR Software muss mehrere Voraussetzungen erfüllen, um für die Anwendung an Es'Hail-2 (QO-100) geeignet zu sein.
\begin{enumerate}
    \item Die Software muss in der Lage sein den USRP X310 ansteuern zu können.
    \item Innerhalb der Software sollte es verschiedene Optionen für die Demodulation geben, um die Signale von Es'Hail-2 (QO-100) richtig demodulieren zu können. Gewünscht sind Einseitenband-AM (LSB/USB),CW und FM. Obwohl FM nicht auf Es'Hail-2 (Q0-100) verwendet werden darf,sollte diese Option für andere Anwendungszwecke der Software vorhanden sein.
    \item Die demodulierten Signale sollten als Audio ausgegeben werden. Auch sollten die demodulierten Signale als Audio abgespeichert werden können.
    \item Das empfangene Frequenzspektrum sollte als FFT und Wasserfalldiagramm korrekt dargestellt werden können.
    \item Die Frequenz, Filterbandbreite, Art der Modulation und Lautstärke sollte im Betrieb verändert werden können.
\end{enumerate}
Die Erstellung der SDR-Software erfolgt im Kapitel \ref{kap:SDR Software}.

\subsection{Bewertung des Empfangssystems}
Um die Eignung des zusammengestellten Empfangssystems für den geplanten Einsatz zu überprüfen, muss dessen Leistungsfähigkeit überprüft werden. Für die Bewertung der Leistungsfähigkeit stehen mehrere Möglichkeiten zur Verfügung. 
\subsubsection*{Rauschen des Empfangssystems}
Zwei wichtige Größen für das Empfangssystem sind seine äquivalente Rauschtemperatur $T_\mathrm{e,sys}$
und seine Rauschzahl $F_\mathrm{sys}$. Die beiden Größen drücken das eigen Rauschen des Systems und die Verschlechterung des $SNR$ vom Eingang des Empfangssystems bis zum Eingang des SDR aus.\newline
\begin{figure}[H]
    \centering
    \includesvg[width=0.9\linewidth]{Bilder/Rauschen der Empfangskette}
    \caption{Blockschaltbild des Empfangssystems mit den einzelnen äquivalenten Rauschtemperaturen $T_\mathrm{e}$, Rauschzahlen $F$ und Verstärkungen $G$ }
    \label{fig:Rauschen-des-Empfangssystems}
\end{figure}
In der Abbildung \ref{fig:Rauschen-des-Empfangssystems} ist ein Blockschaltbild des Empfangssystems zu sehen. Eingetragen sind neben den Namen der einzelnen Zweitore auch ihre äquivalente Rauschtemperatur $T_\mathrm{e}$, Rauschzahl $F$ und ihre Verstärkung $G$.\newline 
Die äquivalente Rauschtemperatur $T_\mathrm{e,sys}$ setzt sich aus äquivalenten Rauschtemperaturen $T_\mathrm{e}$ der einzelnen Zweitore im Empfangssystem zusammen. Deren äquivalente Rauschzahl $T_\mathrm{e}$ kann mithilfe der Gleichung \ref{eq:Rauschzahl-aus-Te-und-T0} mit ihrer Rauschzahl $F$ bestimmt werden. Die Rauschzahl passiver Zweitore, wie den Koaxialleitungen, der Fernspeiseweiche, dem Patchfeld und dem RF-Switch können mit der Gleichung \ref{eq:Rauschzahl-passives-Zweitor} aus ihrem Verlust $L$ bestimmt werden.
\begin{table}[H]
    \centering
    \begin{tabular}{c|c|c|c}
      Name   & Rauschzahl $F\,\text{in Absolut}$& $T_\mathrm{e}\,\text{in K}$ & Gewinn $G\,\text{in Absolut}$\\
      \hline
      Koax1   & $F_\mathrm{1}=L_\mathrm{Koax1}=1.46$& $T_\mathrm{e1}=133.4$ & $G_\mathrm{1}=\frac{1}{1.46}=0.685$\\
      LNC   & $F_\mathrm{LNC}=1.48$& $T_\mathrm{eLNC}=139.2$ & $G_\mathrm{LNC}=316227.77$\\
      Koax2   & $F_\mathrm{2}=L_\mathrm{Koax2}=1.69$& $T_\mathrm{e2}=200.1$ & $G_\mathrm{2}=\frac{1}{1.69}=0.59$\\
      BiasTee   & $F_\mathrm{BiasTee}=L_\mathrm{BiasTee}=1.41$& $T_\mathrm{eBiasTee}=118.9$ & $G_\mathrm{BiasTee}=\frac{1}{1.41}=0.71$\\
      Koax3   & $F_\mathrm{3}=L_\mathrm{Koax3}=1.06$& $T_\mathrm{e3}=17.4$ & $G_\mathrm{3}=\frac{1}{1.06}=0.94$\\
      Patchfeld   & $F_\mathrm{Patchfeld}=L_\mathrm{Patchfeld}=1.2$& $T_\mathrm{ePatchfeld}=58$ & $G_\mathrm{Patchfeld}=\frac{1}{1.2}=0.83$\\
      Koax4   & $F_\mathrm{4}=L_\mathrm{Koax4}=1.03$& $T_\mathrm{e4}=8.7$ & $G_\mathrm{4}=\frac{1}{1.03}=0.97$\\
      RF-Switch & $F_\mathrm{RF-Switch}=L_\mathrm{RF-Switch}=1.07$& $T_\mathrm{eRF-Switch}=20.3$ & $G_\mathrm{RF-Switch}=\frac{1}{1.97}=0.93$\\
      Koax5   & $F_\mathrm{5}=L_\mathrm{Koax5}=1.03$& $T_\mathrm{e5}=8.7$ & $G_\mathrm{5}=\frac{1}{1.03}=0.97$\\
      SDR  & $F_\mathrm{SDR}=6.31$& $T_\mathrm{eSDR}=1539.9$ & $G_\mathrm{SDR}=30\,\text{dB}$\\
    \end{tabular}
    \caption{Bestimmte Rauschzahl $F$, äquivalente Rauschtemperatur $T_\mathrm{e}$ und Verstärkung $G$ der einzelnen Zweitore}
    \label{tab:Bestimmte-Werte-der-Zweitore-für-Te}
\end{table}
Mit den Werten in Tabelle \ref{tab:Bestimmte-Werte-der-Zweitore-für-Te} kann die äquivalente Rauschtemperatur $T_\mathrm{sys}$ des Empfangssystems mithilfe der Gleichung \ref{eq:Gesamt-äquivalente-Rauschtemperatur-Kaskade} bestimmt werden. Der für die Berechnung verwendete Python Code ist im Github-Repository und im Anhang \ref{lst:Link-Budget-python} hinterlegt.
\begin{equation}
\begin{split}
        T_\mathrm{e,sys}=&T_\mathrm{e1}+\frac{T_\mathrm{eLNC}}{G_\mathrm{1}}+\frac{T_\mathrm{e2}}{G_\mathrm{1}\cdot G_\mathrm{LNC}}+\frac{T_\mathrm{eBiasTee}}{G_\mathrm{1}\cdot G_\mathrm{LNC}\cdot G_\mathrm{2}}+\frac{T_\mathrm{e3}}{G_\mathrm{1}\cdot G_\mathrm{LNC}\cdot G_\mathrm{2}\cdot G_\mathrm{BiasTee}}\\
        &+\frac{T_\mathrm{ePatchfeld}}{G_\mathrm{1}\cdot G_\mathrm{LNC}\cdot G_\mathrm{2}\cdot G_\mathrm{BiasTee}\cdot G_\mathrm{3}}\\&+\frac{T_\mathrm{e4}}{G_\mathrm{1}\cdot G_\mathrm{LNC}\cdot G_\mathrm{2}\cdot G_\mathrm{BiasTee}\cdot G_\mathrm{3}\cdot G_\mathrm{Patchfeld}}\\
        &+\frac{T_\mathrm{eRF-Switch}}{G_\mathrm{1}\cdot G_\mathrm{LNC}\cdot G_\mathrm{2}\cdot G_\mathrm{BiasTee}\cdot G_\mathrm{3}\cdot G_\mathrm{Patchfeld}\cdot G_\mathrm{4}}\\
        &+\frac{T_\mathrm{e5}}{G_\mathrm{1}\cdot G_\mathrm{LNC}\cdot G_\mathrm{2}\cdot G_\mathrm{BiasTee}\cdot G_\mathrm{3}\cdot G_\mathrm{Patchfeld}\cdot G_\mathrm{4}\cdot G_\mathrm{RF-Switch}}\\
        &+\frac{T_\mathrm{eSDR}}{G_\mathrm{1}\cdot G_\mathrm{LNC}\cdot G_\mathrm{2}\cdot G_\mathrm{BiasTee}\cdot G_\mathrm{3}\cdot G_\mathrm{Patchfeld}\cdot G_\mathrm{4}\cdot G_\mathrm{RF-Switch}\cdot G_\mathrm{5}}\\
        &=336.63\,\text{K}
\end{split}
\label{eq:äquivalente-Rauschtemperatur-Empfangsystem}
\end{equation}
Mit der bestimmten äquivalenten Rauschtemperatur $T_\mathrm{e,sys}$ des Empfangssystems kann die Rauschzahl $F_\mathrm{sys}$ des Empfangssystems mit Gleichung \ref{eq:Rauschzahl-aus-Te-und-T0}.
\begin{equation}
    F_\mathrm{sys}=1+\frac{T_\mathrm{e,sys}}{T_\mathrm{0}}=1+\frac{336.63\,\text{K}}{290\,\text{K}}=2.161=3.34\,\text{dB}
\end{equation}
 Die größte Auswirkung auf $T_\mathrm{e,sys}$ und $F_\mathrm{sys}$ haben die erste Koaxialleitung und der LNC. Dank der hohen Verstärkung des LNC mit $G_\mathrm{LNC}=55\,\text{dB}=316227.66$ als zweites Element werden die Rauschzahlen $F$, bzw. die äquivalenten Rauschtemperaturen $T_\mathrm{e}$ der folgenden Zweitore stark reduziert, sodass diese keine große Auswirkung mehr auf den Gesamtwert haben. Jedoch wird die äquivalente Rauschtemperatur des LNC $T_\mathrm{eLNC}$ durch die Dämpfung der ersten Koaxialleitung stärker gewichtet und nicht reduziert. Das erklärt die  Rauschzahl $F_\mathrm{sys}=3.34\,\text{dB}$ und die äquivalente Rauschtemperatur des Empfangssystems von $ T_\mathrm{e,sys}=336.63\,\text{K}$.

\subsubsection*{Verstärkungen und Dämpfungen im Empfangssystem}
Im Empfangssystem treten verschiedene Verstärkungen und Dämpfungen auf. Diese können in einer Größe, der Verstärkung $G_\mathrm{sys}$ des Empfangssystems, zusammengefasst werden. Mit dieser Größe kann übersichtliche Angabe zur Verstärkung des Empfangssystems gemacht werden.\newline
Im Empfangssystem sind nur zwei Verstärkenden Komponenten vorhanden. Die erste Komponente ist der LNC, welcher mit einer typischen Verstärkung von $G_\mathrm{LNC}=55\,\text{dB}$ angeben wird. Die zweite Komponente ist der USRP X310, welcher eine variable Verstärkung besitzt. Für Rechenzwecke wird hier von einer Verstärkung von $G_\mathrm{SDR}=31.5\,\text{dB}$ angegeben. Diese beiden Verstärkungen können in eine Größe $G$ zusammengefasst werden.
\begin{equation*}
    G=G_\mathrm{LNC,dB}+G_\mathrm{SDR,dB}=55\,\text{dB}+31.5\,\text{dB}=86.5\,\text{dB}
\end{equation*}
Dämpfungen treten im Empfangssystem an mehreren Stellen auf. Die größte Dämpfung wird durch Koaxialleitungen verursacht. Ihre Dämpfung ist in den Gleichung \ref{eq:Dämpfung_Koax1} bis \ref{eq:Dämpfung_Koax4 und Koax5} angegeben und kann in einer gemeinsamen Größe $L_\mathrm{Koax}$ zusammengefasst werden.
\begin{equation*}
    \begin{split}
        L_\mathrm{Koax}&=L_\mathrm{Koax1,dB}+L_\mathrm{Koax2,dB}L_\mathrm{Koax3,dB}L_\mathrm{Koax4,dB}L_\mathrm{Koax5,dB}\\
        &=1.655\,\text{dB}+2.282\,\text{dB}+0.254\,\text{dB}+0.108\,\text{dB}+0.108\,\text{dB}=4.407\,\text{dB}
    \end{split}
\end{equation*}
Eine weitere dämpfende Komponente ist die Fernspeiseweiche. Ihre Dämpfung wird mit $L_\mathrm{BiasTee}=1.5\,\text{dB}$ angegeben. Weitere Dämpfungen treten am Patchfeld $L_\mathrm{Patchfeld}=0.8\,\text{dB}$ und an der Schaltmatrix auf. Bei einer Frequenz $f_\mathrm{ZF}\leq1.3\,\text{GHz}$ tritt durch die Schaltmatrix eine maximale Dämpfung von $L_\mathrm{RF-Switch}=0.3\,\text{dB}$ auf. Die Dämpfungen $L_\mathrm{Koax}$, $L_\mathrm{BiasTee}$, $L_\mathrm{Patchfeld}$ und $L_\mathrm{RF-Switch}$
können zur besseren Übersicht in einer Größe $L_\mathrm{sys}$ zusammengefasst werden.
\begin{equation}
    \begin{split}
        L_\mathrm{sys}&=L_\mathrm{Koax,dB}+L_\mathrm{BiasTee,dB}+L_\mathrm{Patchfeld,dB}+L_\mathrm{RF-switch,dB}\\
        &=4.407\,\text{dB}+1.5\,\text{dB}+0.8\,\text{dB}+0.3\,\text{dB}=7.01\,\text{dB}
    \end{split}
    \label{eq:Verluste-Empfangsystem}
\end{equation}
Mit der Verstärkung $G$ und der Dämpfung $L_\mathrm{sys}$ kann die Gesamtverstärkung des Empfangssystems in einer übersichtlichen Größe $G_\mathrm{sys}$ dargestellt werden.
\begin{equation}
    G_\mathrm{sys}=G_\mathrm{LNC,dB}-L_\mathrm{sys,dB}=86.5\,\text{dB}-7.01\,\text{dB}=79.49\,\text{dB}
    \label{eq:Gesamtverstärkung-Empfangssystems}
\end{equation}
Die Gesamtverstärkung des Empfangssystems beträgt maximal $G_\mathrm{sys}=79.49\,\text{dB}$. Mit dieser Verstärkung ist es problemlos möglich die schwache Signale von Es'Hail-2 (QO-100) zu verstärken. 

\subsubsection*{Empfangsgüte $G/T$}
Mit der Empfangsgüte $G/T$ kann die Empfindlichkeit des Empfangssystems angegeben werden. Sie ist ein Maß für die Qualität des Empfangssystems, einschließlich der Antenne. Sie entspricht dem Verhältnis des Antennengewinn $G_\mathrm{R,max}$ und des Rauschens $T_\mathrm{A}+T_\mathrm{e,sys}$ des Empfangssystems.\cite{Satellite_Communications_Systems}
\begin{equation}
    G/T=\frac{G_\mathrm{R,max}}{T_\mathrm{e,sys}+T_\mathrm{A}}
    \label{eq:Empfangsgüte}
\end{equation}
Die Einheit der Empfangsgüte ist dabei $\text{1/K}$ oder $\text{dB/K}$. Je höher der Wert $(\text{dB/K})$ ist, desto besser ist die Empfangsgüte, da das Empfangssystem mehr Gewinn pro Rauschtemperatur hat.\newline
Da sich die Antennentemperatur $T_\mathrm{A}$ je nach Bedingung unterscheidet, muss diese zuerst für jede Bestimmung ermittelt werden.\newline
Für die Bedingung klarer Himmel kann die Antennentemperatur mit der Gleichung \ref{eq:Antennentemperatur-klarer-Himmel} bestimmt werden. Da für die verwendete Parabolantenne kein 
Antennendiagramm vorhanden ist, wird diese als eine ideale Antenne ohne Nebenkeulen Richtung Boden ausgegangen. Damit wird $T_\mathrm{Ground}=0\,\text{K}$. Die Helligkeitstemperatur kann für den jeweiligen Elevationswinkel der Antenne aus der Abbildung \ref{fig:Temperatur-Himmel} entnommen werden. Der Elevationswinkel $\varepsilon$ der Antenne ist in Gleichung \ref{eq:Elevation-Antenne} mit $\varepsilon=27.36\degree\approx30°$ angegeben. Zusammen mit einer Frequenz $f\approx10.5\,\text{GHz}$ kann eine Helligkeitstemperatur von $T_\mathrm{Sky}\approx6.5\,\text{K}$ ermittelt werden.\newline
\begin{equation}
    T_\mathrm{A,klarerHimmel}=T_\mathrm{Sky}+T_\mathrm{Ground}=6.5\,\text{K}+0\,\text{K}=6.5\,\text{K}
    \label{eq:Antennentemperatur-Bedingung-klarer-Himmel}
\end{equation}
Mit der Gleichung \ref{eq:Empfangsgüte} kann die Empfangsgüte $G/T$ für die Bedingung klarer Himmel bestimmt werden. Die äquivalente Rauschtemperatur ist in Gleichung \ref{eq:äquivalente-Rauschtemperatur-Empfangsystem} angegeben. Der Gewinn der Empfangsantenne ist in Gleichung \ref{eq:Gewinn-der-Empfangsantenne} angegeben und wird für eine Frequenz $f=10.5\,\text{GHz}$ mit $G_\mathrm{R,max}=38.6\,\text{dBi}=7244.36$ angenommen.
\begin{equation}
    G/T=\frac{G_\mathrm{R,max}}{T_\mathrm{e,sys}+T_\mathrm{A,klarerHimmel}}=\frac{7244.36}{336.63\,\text{K}+6.5\,\text{K}}=21.11\,\text{1/K}=13.24\,\text{dB/K}
    \label{eq:Empfangsgüte-Bedingung-klarer-Himmel}
\end{equation}
Eine Empfangsgüte von $13.24\,\text{dB/K}$ ist ein solider Wert für die geplante Anwendung, kann aber nicht mit der Empfangsgüte $G/T=26.5\,\text{dB/K}$ professionellen Empfangssystemen mithalten.\cite{Vergleich-GT}
Für die Bedingung leichter Regen muss bei der Antennentemperatur $T_\mathrm{A}$ die Dämpfung durch leichte Regenschauer berücksichtigt werden. Die Dämpfung ist in Gleichung     \ref{eq:Dämpfung-durch-leichten-Regen} mit $L_\mathrm{leichterRegen}=0.2\,\text{dB}=1.05$.Auch die Temperatur der Wolken $T_\mathrm{m}=275\,\text{K}$ spielt dabei eine Rolle. Die Antennentemperatur für die Bedingung leichter Regen kann mit der Gleichung \ref{eq:Antennentemperatur-bei-Regen} bestimmt werden.
\begin{equation}
\begin{split}
        T_\mathrm{A,leichterRegen}&=\frac{T_\mathrm{Sky}}{L_\mathrm{leichterRegen}}+T_\mathrm{m}\left(1-\frac{1}{L_\mathrm{leichterRegen}}\right)+T_\mathrm{Ground}\\
        &=\frac{6.5\,\text{K}}{1.05}+275\,\text{K}\left(1-\frac{1}{1.05}\right)+0\,\text{K}=19.29\,\text{K}
\end{split}
\label{eq:Antennentemperatur-leichterRegen}
\end{equation}
Im Vergleich zur Antennentemperatur bei klaren Himmel $T_\mathrm{A,klarerHimmel}=6.5\,\text{K}$ ist die Antennentemperatur bei leichten Regenfälle mit $T_\mathrm{A,leicherRegen}=19.29\,\text{K}$ fast dreimal so groß. Das zeigt auf, wie wichtig die Berücksichtigung der Dämpfung durch Regenschauer in der Antennentemperatur ist. Die höhere Antennentemperatur bedeutet mehr Rauschen am Eingang des Empfangssystem, was zur einer Verschlechterung des $G/T$ führt.
\begin{equation}
    G/T=\frac{G_\mathrm{R,max}}{T_\mathrm{e,sys}+T_\mathrm{A,leichterRegen}}=\frac{7244.36}{336.63\,\text{K}+19.29\,\text{K}}=20.35\,\text{1/K}=13.12\,\text{dB/K}
    \label{eq:Empfangsgüte-Bedingung-leichter-Regen}
\end{equation}
Im Vergleich zur Empfangsgüte bei klaren Himmel $G/T=13.24\,\text{dB/K}$ sinkt die Empfangsgüte bei leichten Regenschauern auf $G/T=13.12\,\text{dB/K}$. Das entspricht einem Verlust von $0.12\,\text{dB/K}$, was im ersten Moment nicht viel wirkt. In Absoluten Zahlen entspricht ein Verlust von $0.12\,\text{dB}$ einem Verlust von ca. $3.6\,\%$\newline
Die Antennentemperatur für die Bedingung Regen kann wird auch mit der Gleichung \ref{eq:Antennentemperatur-bei-Regen} bestimmt. Die Dämpfung durch stärkere Niederschläge ist in Gleichung \ref{eq:bestimmte-Regendämpfung} mit $L_\mathrm{Regen}=8.86\,\text{dB}=7.69$ angegeben.
\begin{equation}
\begin{split}
        T_\mathrm{A,Regen}&=\frac{T_\mathrm{Sky}}{L_\mathrm{Regen}}+T_\mathrm{m}\left(1-\frac{1}{L_\mathrm{Regen}}\right)+T_\mathrm{Ground}\\
        &=\frac{6.5\,\text{K}}{7.69}+275\,\text{K}\left(1-\frac{1}{7.69}\right)+0\,\text{K}=240.1\,\text{K}
\end{split}
\label{eq:Antennentemperatur-Regen}
\end{equation}
Verglichen mit der Antennentemperatur bei leichten Regen $T_\mathrm{A,leichterRegen}=19.29\,\text{K}$ ist die Antennentemperatur bei stärkeren Niederschläge $T_\mathrm{A,Regen}=240.1\,\text{K}$ deutlich höher. Die hohe Antennentemperatur ist den stärkeren Niederschlägen geschuldet. Die höhere Antennentemperatur führt zu einer deutlichen Erhöhung des Rausches im System, was sich negativ auf die Empfangsgüte $G/T$ und das $SNR$ auswirken wird.
\begin{equation}
    G/T=\frac{G_\mathrm{R,max}}{T_\mathrm{e,sys}+T_\mathrm{A,Regen}}=\frac{7244.36}{336.63\,\text{K}+240.1\,\text{K}}=12.56\,\text{1/K}=10.99\,\text{dB/K}
    \label{eq:Empfangsgüte-Bedingung-Regen}
\end{equation}
Wie vermutet wirkt sich die deutlich höhere Antennentemperatur negativ auf die Empfangsgüte $G/T$ aus. Im Vergleich zur Empfangsgüte bei klaren Himmel $G/T=13.24\,\text{dB/K}$ sinkt die Empfangsgüte bei starken Niederschlägen auf $G/T=10.99\,\text{dB/K}$. Das entspricht einem Verlust von $2.25\,\text{dB}$ oder ca.$40.5\,\%$. Das wird sich deutlich negativ auf das $SNR$ des Empfängers auswirken und eventuell zu Ausfällen des Downlinks führen.
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

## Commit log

2025-12-10 Working on conical horn antenna
2025-12-10 Simulation added for conical antennas
2026-01-07 Added first version of SDR Software, New Pythoncode for system noise temperatur
2026-01-11 Bug fixes and added 3D print files for the feed holder
    [Feed-Halter_Base.STEP, Feed-Halter_Top.STEP]
2026-01-29 Final Version of the Bachelor Thesis
    [Holder Downconverter-Body.step]
